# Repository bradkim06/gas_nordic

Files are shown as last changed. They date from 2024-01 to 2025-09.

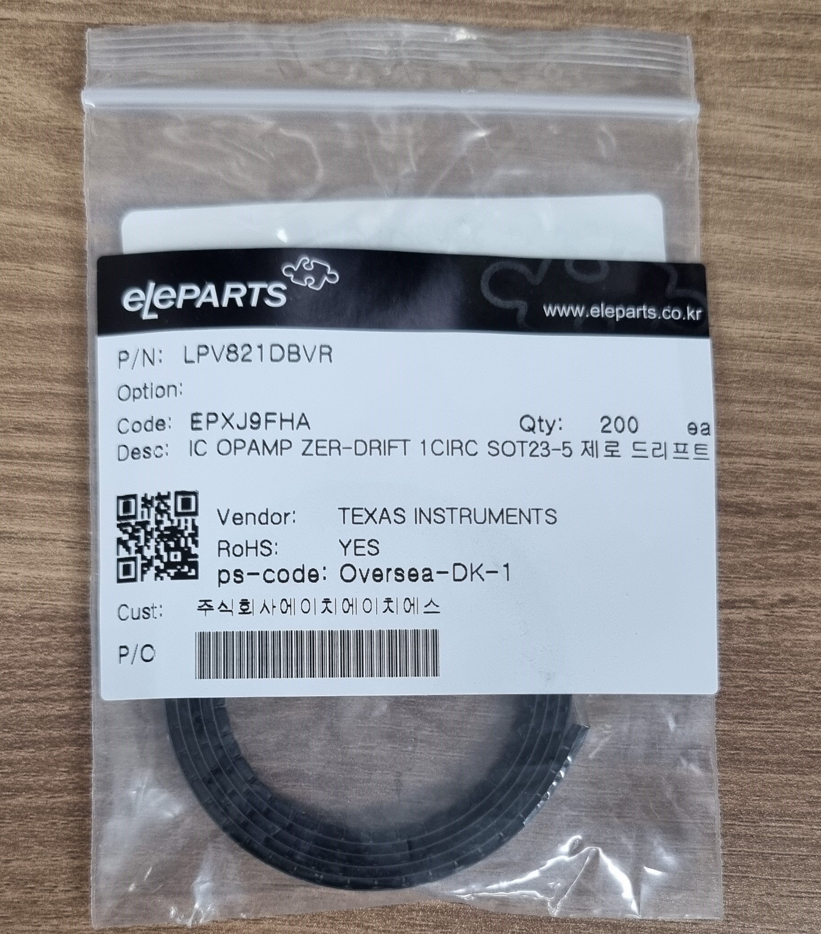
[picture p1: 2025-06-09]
hardware/gas_nrf52832/pcb/2차_Rev1.0.2(4L)/24.9.19 검수조서/9.19 검수조서 사진/19.jpg

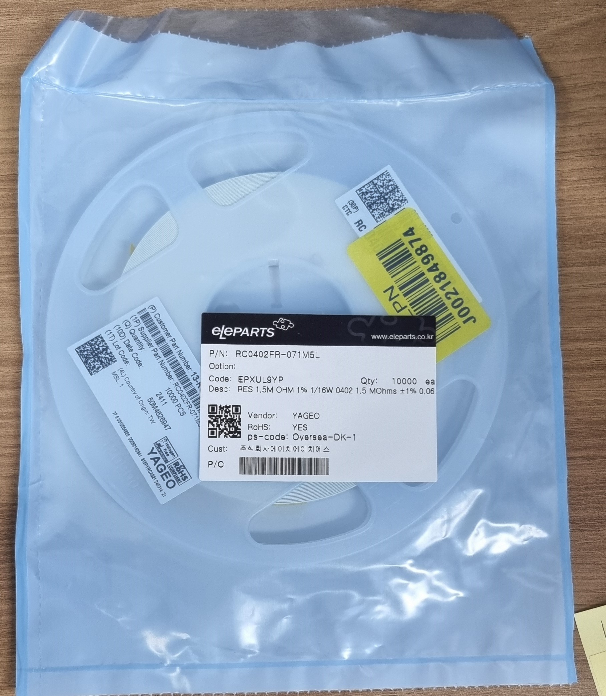
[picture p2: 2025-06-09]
hardware/gas_nrf52832/pcb/2차_Rev1.0.2(4L)/24.9.19 검수조서/9.19 검수조서 사진/10.jpg

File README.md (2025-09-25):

# Industrial Gas Monitor Firmware (nRF52832 + Zephyr)

Firmware version **1.0.2** for HHS's portable industrial gas monitor. The
application runs on a custom nRF52832 board, measures multiple gases, and
transmits real-time readings over Bluetooth® Low Energy. Environmental data is
fused with the Bosch BSEC2 library to provide indoor air-quality indicators in
addition to electrochemical gas concentrations.

---

## Table of contents

1. [Key features](#key-features)
2. [Hardware overview](#hardware-overview)
3. [Supported measurements](#supported-measurements)
4. [Firmware architecture](#firmware-architecture)
5. [Build and flash](#build-and-flash)
6. [Bluetooth protocol](#bluetooth-protocol)
7. [Calibration & persistent settings](#calibration--persistent-settings)
8. [Reference tables](#reference-tables)
9. [License](#license)

---

## Key features

- **Multi-gas sensing** – Electrochemical front-end for oxygen and a selectable
  toxic gas channel (NO₂, CO, H₂S, Cl₂, NH₃, etc.) with temperature
  compensation and dynamic calibration algorithms.【F:src/gas.c†L1-L212】
- **Environmental monitoring** – Integrated BME68x support with Bosch BSEC2
  fusion to derive temperature, humidity, pressure, IAQ, equivalent CO₂, and
  VOC indices. BSEC state is saved to flash for consistent long-term behavior.
  【F:drivers/bme68x_iaq/bme68x_iaq.c†L40-L460】【F:src/settings.c†L1-L137】
- **Bluetooth LE connectivity** – Custom 128-bit GATT service publishes
  semicolon-delimited measurements every 10 seconds and accepts configuration
  commands from a companion application.【F:src/bluetooth.h†L5-L45】【F:src/bluetooth.c†L520-L585】
- **Robust low-power platform** – Built on Zephyr RTOS (nRF Connect SDK v2.4.2)
  with watchdog, power management, persistent storage, and board-specific
  optimizations.【F:prj.conf†L1-L110】

## Hardware overview

- **Target SoC:** Nordic Semiconductor nRF52832 (ARM® Cortex®-M4F, BLE 5).
- **Custom board definition:** `boards/arm/hhs_nrf52832` (schematic and layout
  included in `doc/`).【F:boards/arm/hhs_nrf52832/hhs_nrf52832.yaml†L1-L53】
- **Latest hardware pack:** `doc/gas_nrf52832_rev1.0.1.pdf` with matching
  schematic `doc/gas_nrf52832_sch_rev0.1.0.pdf`.
- **Peripheral highlights:**
  - Bosch BME688/BME680 environmental sensor on I²C.
  - Dual-channel electrochemical sensor front-end via SAADC.
  - Battery gauge through voltage divider + ADC.
  - RGB status LED and watchdog support.

## Supported measurements

| Domain | Reported values |
| --- | --- |
| Electrochemical gas | Oxygen concentration (%VOL) and one selectable toxic gas in
| | ppm, both temperature compensated and filtered.【F:src/gas.c†L1-L212】 |
| Environmental | Temperature (°C), relative humidity (%RH), barometric
| | pressure (Pa), IAQ score, equivalent CO₂ (ppm), and breath
| | VOC index via BSEC2.【F:drivers/bme68x_iaq/bme68x_iaq.c†L40-L460】 |
| Power | Battery percentage derived from loaded voltage profile.
| BLE telemetry | Timestamped payload streamed every 10 seconds (default).

## Firmware architecture

The firmware is organized into cooperative Zephyr threads and kernel events. A
high-level flow is shown below:

```mermaid
---
title: Portable Gas Monitor Firmware Flow
---
stateDiagram-v2
    direction TB
    [*] --> ZephyrRTOS
    ZephyrRTOS --> BME68x_BSEC
    ZephyrRTOS --> Electrochemical_ADC
    ZephyrRTOS --> BluetoothLE

    state ZephyrRTOS {
        state BME68x_BSEC {
            direction LR
            initBSEC --> readEnvironmental : 3 s
            initBSEC --> computeIAQ : 60 s
        }
        state Electrochemical_ADC {
            direction TB
            sampleADC --> tempCompensation
            tempCompensation --> gasConversion
            gasConversion --> dynamicCalibration
        }
        state BluetoothLE {
            direction LR
            initialize --> advertise
            advertise --> connected
            connected --> notifyData : 10 s
        }
    }
```

Key modules reside in `src/` (application logic), `drivers/bme68x_iaq/`
(BSEC2 integration), and `lib/` (Bosch libraries). Threads communicate via
Zephyr events for deterministic BLE publishing and alarm handling.

## Build and flash

1. **Install prerequisites**
   - [nRF Connect SDK v2.4.2](https://developer.nordicsemi.com/nRF_Connect_SDK/doc/2.4.2/nrf/index.html)
     with the Zephyr toolchain, `west`, and SEGGER J-Link tools.
   - Bosch BSEC2 library files are already provided under `lib/`.
2. **Fetch the source**
   ```bash
   git clone https://github.com/<your-org>/gas_nordic.git
   cd gas_nordic
   west init -l .
   west update
   ```
3. **Build**
   ```bash
   west build -b hhs_nrf52832 .
   ```
   The output image is generated at `build/zephyr/zephyr.hex`.
4. **Flash**
   ```bash
   west flash
   ```
   or, to use Nordic's command-line tools directly:
   ```bash
   ./flash.sh
   ```
   (`flash.sh` performs a chip erase and programs the generated HEX via
   `nrfjprog`).【F:flash.sh†L1-L5】

## Bluetooth protocol

The device exposes a proprietary 128-bit primary service (`0000FFF0-0000-1000-8000-00805F9B34FB`).【F:src/bluetooth.h†L9-L26】

| Characteristic | UUID | Properties | Description |
| --- | --- | --- | --- |
| Measurement | `0000FFF1-0000-1000-8000-00805F9B34FB` | Notify | Periodic payload `O2;Gas;Battery;Temp;Pressure;Humidity` separated by semicolons, integers scaled as `<val1>.<val2>` where applicable.【F:src/bluetooth.c†L536-L576】 |
| Command | `0000FFF2-0000-1000-8000-00805F9B34FB` | Write | ASCII commands for calibration and configuration: `O2=<percent>`, `NO2=<ppm>`, `BT=<name>`.【F:src/bluetooth.c†L60-L124】 |

Notifications are issued when a connection is active and the client enables
CCCD. Each update corresponds to the latest sensor snapshot and is throttled to
the configured 10 s publishing interval.

## Calibration & persistent settings

- **Dynamic calibration** continuously refines oxygen and toxic gas baselines by
  monitoring derivative stability, expected ranges, and board temperature.
  Manual calibration can be triggered by writing to the command characteristic as
  described above.【F:src/gas.c†L1-L212】【F:src/bluetooth.c†L60-L124】
- **Persistent storage** uses Zephyr's settings/NVS subsystem to retain BSEC
  state, sensor calibration voltages, and the advertised Bluetooth name across
  reboots.【F:src/settings.c†L1-L200】
- **Battery reporting** samples SAADC channels and converts them into a
  percentage using empirically tuned thresholds (see `src/battery.c`).

## Reference tables

### Oxygen concentration guide

| Category | Concentration range | Notes |
| --- | --- | ----- |
| High oxygen | &gt; 24 % | Elevated combustion risk. |
| Normal air | 20.9 % | Nominal breathable atmosphere. |
| Elevated exposure risk | 19.5 – 20.9 % | Monitor for dilution hazards. |
| Low oxygen | 16 – 19.5 % | Impaired cognition and physical performance. |
| Anoxic | &lt; 16 % | Life-threatening within minutes. |

### Indoor air quality (IAQ) interpretation

| IAQ index | Air quality | Suggested action |
| --- | --- | --- |
| 0 – 50 | Excellent | None required. |
| 51 – 100  | Good | None required. |
| 101 – 150 | Lightly polluted | Ventilate if convenient. |
| 151 – 200 | Moderately polluted | Increase ventilation with clean air. |
| 201 – 250 | Heavily polluted | Identify contamination source, improve airflow. |
| 251 – 350 | Severely polluted | Restrict access, maximize ventilation. |
| &gt; 351 | Extremely polluted | Avoid occupancy until levels normalize. |

### CO₂ comfort levels

| Level | Description | ppm |
| :---: | --- | --- |
| 😆 | Healthy outdoor reference | 350 |
| 😀 | Healthy indoor climate | 600 |
| 🙂 | Acceptable indoors | 800 |
| 🙁 | Ventilation desirable | 1000 |
| 😩 | Ventilation necessary | 1200 |
| 😡 | Noticeable health effects | 2000 |
| ⚠️ | Dangerous for prolonged exposure | 5000 |

### VOC hygiene guidance

| Rating | Recommendation | Exposure duration | TVOC (ppm) |
| --- | --- | --- | --- |
| Excellent | Target value | Unlimited | 0 – 0.065 |
| Good | Ventilation recommended | Unlimited | 0.065 – 0.22 |
| Moderate  | Increase ventilation, inspect for sources | &lt; 12 months | 0.22 – 0.66 |
| Poor | Intensify ventilation, locate emission sources  | &lt; 1 month | 0.66 – 2.2 |
| Unhealthy | Immediate ventilation required | Hours | 2.2 – 5.5 |

## License

Distributed under the terms of the [MIT License](LICENSE). Bosch BSEC2 library
usage is subject to its proprietary license (see `lib/Bosch-BSEC2-Library`).

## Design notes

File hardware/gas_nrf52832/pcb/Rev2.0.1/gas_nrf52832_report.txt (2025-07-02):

PCB 통계 보고서
=======================
- 날짜: Tuesday, June 24, 2025 at 10:41:05 AM
- 프로젝트: gas_nrf52832
- 보드 이름: gas_nrf52832

기판
-----
- 두께: 알 수 없음
- 높이: 알 수 없음
- 지역: 알 수 없음

패드
----
- 스루홀: 28
- SMD: 236
- 연결선: 0
- NPTH: 4

비아
----
- 관통 비아: 104
- 매립/매장: 0
- 마이크로 비아: 0

부품
----------

| | 전면 | 후면 | 합계 |
|---|----|----|----|
|THT: |  6 |  2 |  8 |
|SMD: | 68 |  7 | 75 |
|지정되지 않음:  |  0 |  0 |  0 |
|합계: | 74 |  9 | 83 |

드릴 홀
-----------

| 개수 | 형상 | X 크기 | Y 크기 | 도금 | 비아/패드 | 시작 레이어 | 종료 레이어 |
|----|----|---|---|---|---|---|---|
| 92 | 둥근 | 0.3000 mm | 0.3000 mm | 도금 관통 홀 | 비아 | F.Cu | B.Cu |
| 12 | 둥근 | 0.4000 mm | 0.4000 mm | 도금 관통 홀 | 비아 | F.Cu | B.Cu |
|  8 | 둥근 | 1.0000 mm | 1.0000 mm | 도금 관통 홀 | 패드 | F.Cu | B.Cu |
|  6 | 둥근 | 2.8000 mm | 2.8000 mm | 도금 관통 홀 | 패드 | F.Cu | B.Cu |
|  4 | 둥근 | 0.9000 mm | 0.9000 mm | 도금 관통 홀 | 패드 | F.Cu | B.Cu |
|  4 | 둥근 | 2.2000 mm | 2.2000 mm | NPTH | 패드 | F.Cu | B.Cu |
|  4 | 슬롯 | 0.4000 mm | 0.8000 mm | 도금 관통 홀 | 패드 | F.Cu | B.Cu |
|  2 | 둥근 | 0.6500 mm | 0.6500 mm | 도금 관통 홀 | 패드 | F.Cu | B.Cu |
|  2 | 둥근 | 1.3000 mm | 1.3000 mm | 도금 관통 홀 | 패드 | F.Cu | B.Cu |
|  2 | 슬롯 | 0.4000 mm | 1.2000 mm | 도금 관통 홀 | 패드 | F.Cu | B.Cu |

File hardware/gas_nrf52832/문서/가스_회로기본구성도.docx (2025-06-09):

기능 Flow Chart

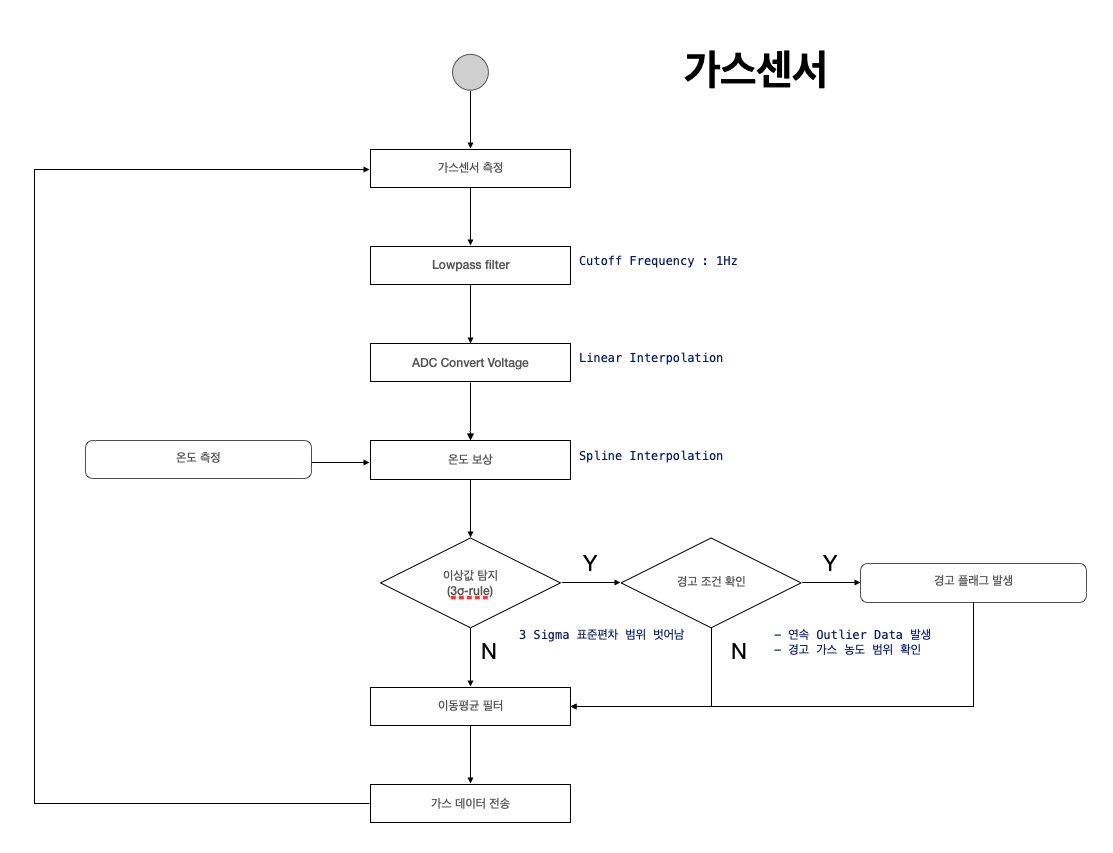
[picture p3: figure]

전기화학식 가스센서 회로 구성 요약

- 전원 주기를 반복하는 것은 일반적으로 긴 회복 시간, 재영점 조정 요구사항, 또는 전원 주기로 인한 센서 손상 가능성 때문에 지속적으로 바이어스가 필요
- LPV821 마이크로파워 증폭기는 초저전력(일반적으로 채널당 650 nA)으로 선택되어 전체 포텐셔스탯 회로가 1 µA의 공급 전류를 사용하므로 배터리 구동 애플리케이션에서 회로를 지속적으로 전원을 공급
- 센서 바이어스와 전류-전압 변환을 제공하는 3단자 전기화학 센서 증폭기 회로, 저항 분배기 바이어스 전압 회로, 아날로그-디지털 변환, 처리 및 블루투스 전송 기능
- 가스센서 온,습도 보정을 위한 BME680 환경센서

전기화학식 가스 센서 장점

- 출력 선형 성
- 저전력 소모
- 우수한 분해능
- 목표 기체에 대해 측정의 반복정 밀도(repeatability)와 정확도

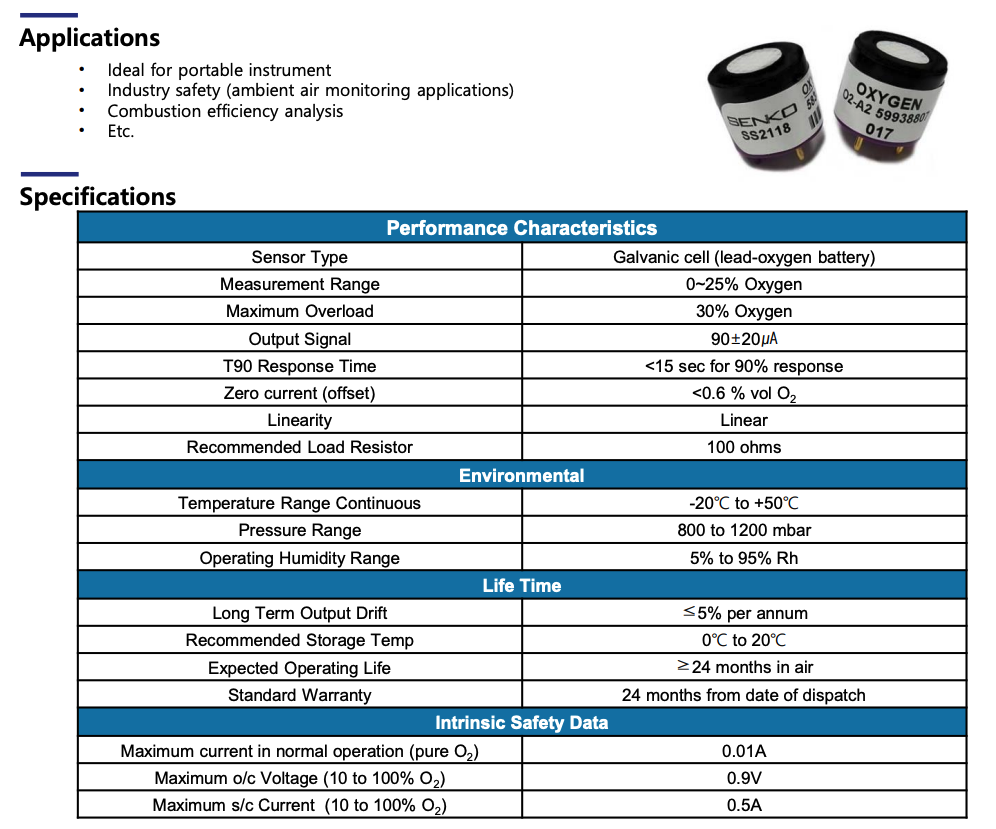
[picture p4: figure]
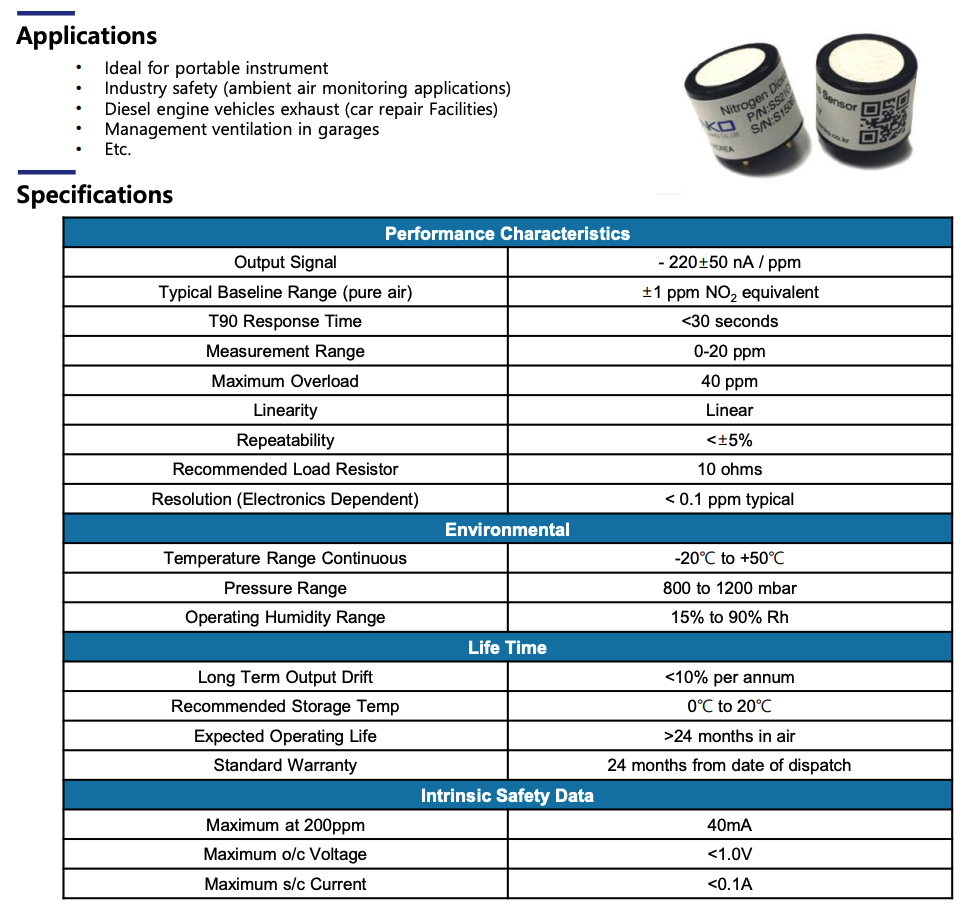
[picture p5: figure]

가스센서 회로

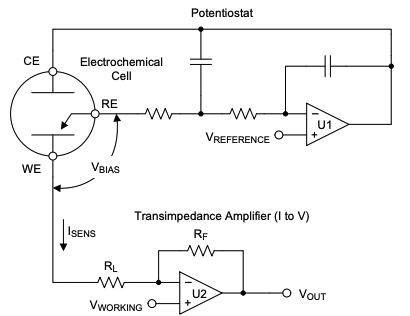
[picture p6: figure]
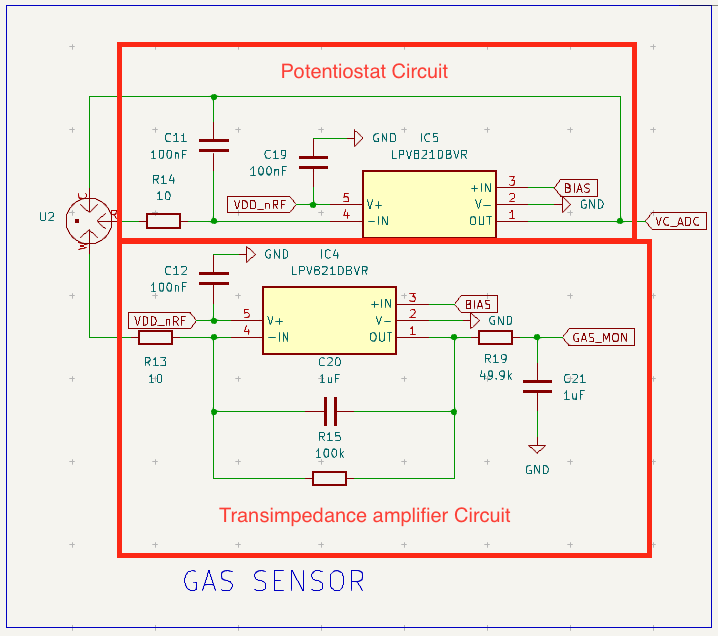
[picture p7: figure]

- 유해가스 회로는 3단자 가스센서로 구성
- 센서의 안정적인 작동과 정확한 측정을 위해 작용전극(Working electrode)과 기준전극(Reference electrode) 사이의 전압을 일정하게 유지하는 Potentiostat 회로
- 가스센서에서 발생하는 미세한 전류 신호를 안정적이고 측정 가능한 전압 신호로 변환하여 가스 농도를 정확하게 측정할 수 있게 해주는 Transimpedance amplifier 회로
- Amplifier의 출력단과 피드백단은 Hardware Low-pass filter 적용

Gas Detection OP-Amp (LPV821)

- 저전력 : Quiescent Current 650 nA
- 고정밀 : Low Offset Voltage: ±10 μV (Maximum) Offset Voltage Drift: ±0.096 μV/°C (Maximum)

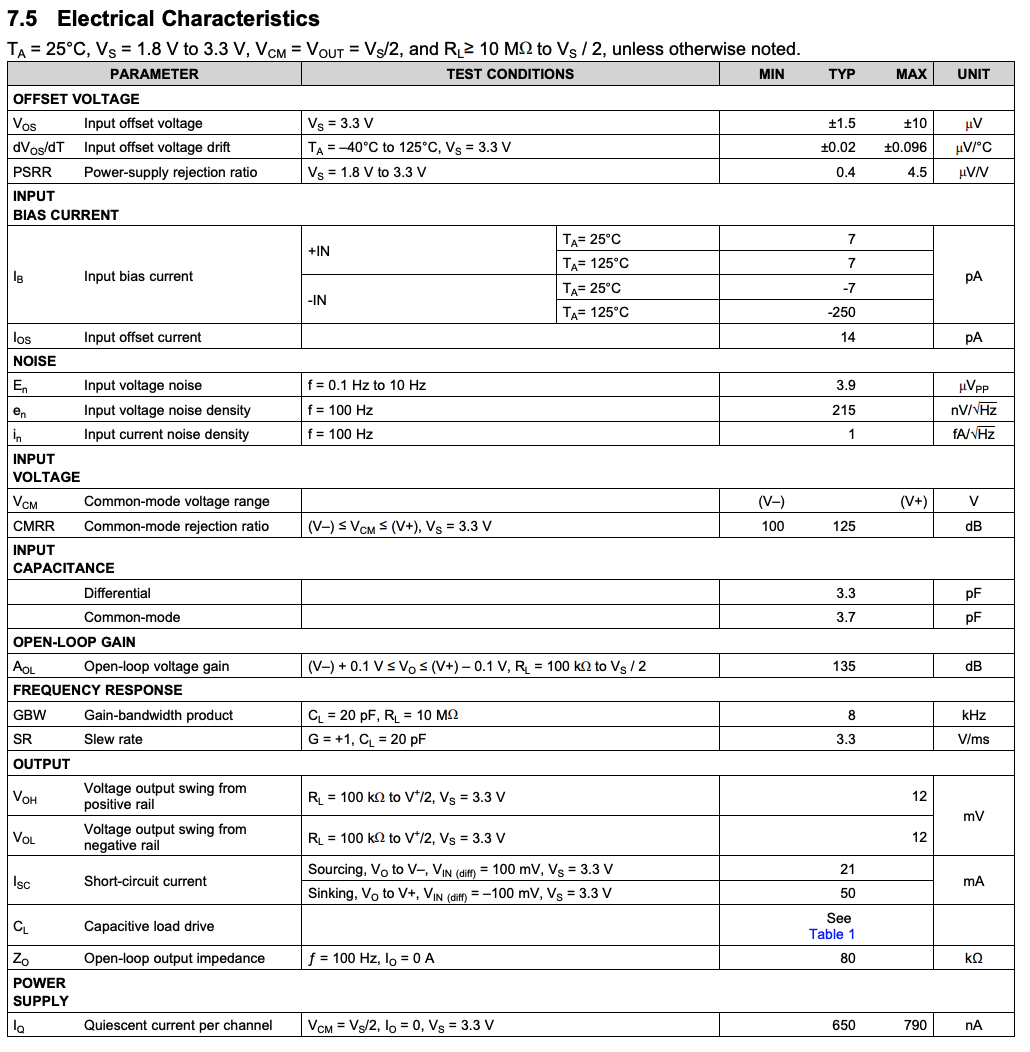
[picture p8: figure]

Battery System

- 50uA 저전력소모 (연간 = 0.05mA*24*365 = 438mA)
- 400mA 이하의 2차 전지 사용시 USB-C 충전 부가회로 (현재)
- 1000mA 이상 1차 전지 사용시 2년 10개월 사용 (전기화학식 센서의 일반적인 수명 2년) (TODO)

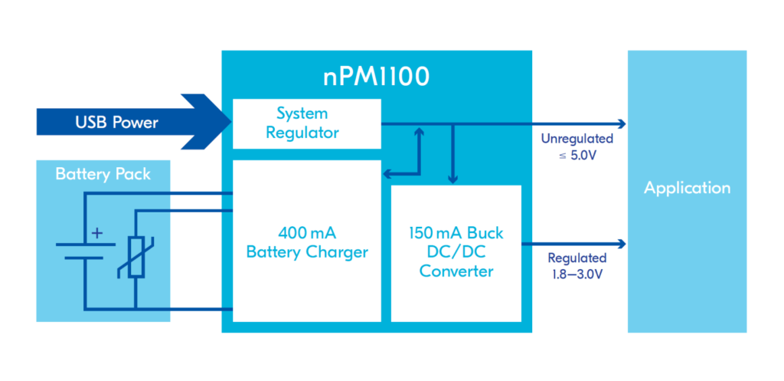
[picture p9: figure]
nPM1100 Power Management IC from Nordic Semiconductor Delivers Power to Your Circuits and Charges Battery - CIRCUITSTATE Electronics

환경센서 BME680(온도,습도 등)

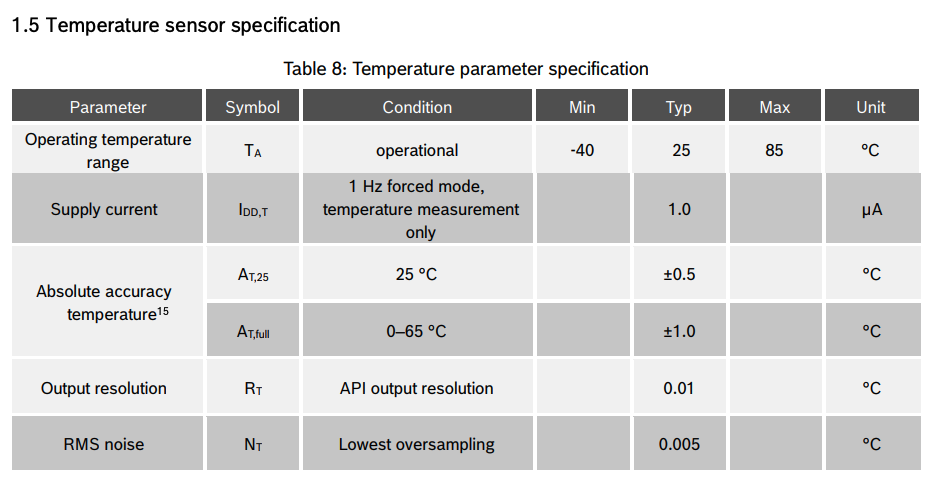
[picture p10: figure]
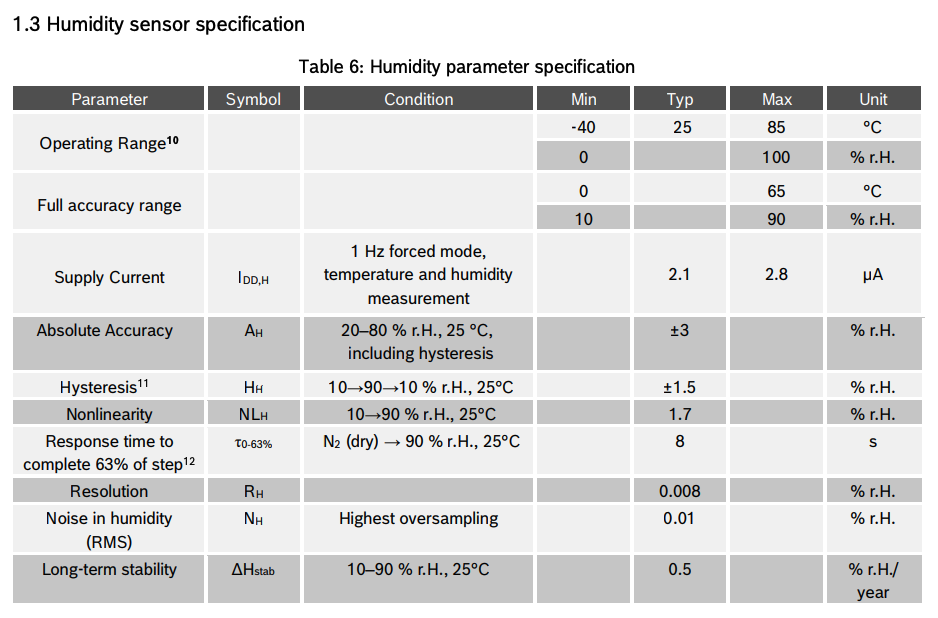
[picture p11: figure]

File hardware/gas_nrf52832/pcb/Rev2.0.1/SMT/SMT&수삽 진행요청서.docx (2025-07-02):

S M T & 수 삽 견 적 요 청 서
업체명 | HHS | | 담당자 /연락처 | 김준수 010-4496-1966
모델명 | Gas_Rev2.0.1 | | 수량 | 4Kit

SMT 제작정보
1 표면실장 : 양면 2 메탈마스크 : 도급 3 크림솔더유형 : 유연 4 부품인계방법 : 경동화물 5 수삽부품유무 : 무 | | | | (단면/양면) (사급/도급) (유연/무연) (퀵/경동화물/방문전달) (유/무)

기타 요청사항

- 부품 6/24(화) 경동화물 발송예정

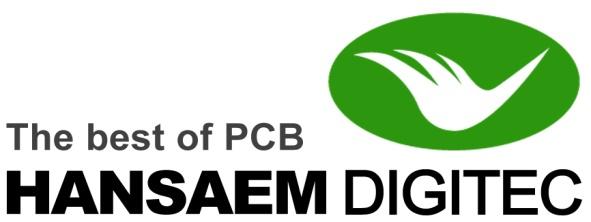
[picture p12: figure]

BOM,PL 및 데이터 전송 | | hs@hsdgt.com
SMT 주문관련 문의 032-581-5375 | | 영업부 차장 김병길 010-6516-5375 과장 최인석 010-6517-5375

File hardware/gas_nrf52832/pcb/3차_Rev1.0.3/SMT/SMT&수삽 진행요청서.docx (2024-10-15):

S M T & 수 삽 견 적 요 청 서
업체명 | HHS | | 담당자 /연락처 | 김준수 010-4496-1966
모델명 | Gas_Rev1.0.3 | | 수량 | 10Kit(20EA)

SMT 제작정보
1 표면실장 : 단면 2 메탈마스크 : 도급 3 크림솔더유형 : 유연 4 부품인계방법 : 경동화물 5 수삽부품유무 : 무 | | | | (단면/양면) (사급/도급) (유연/무연) (퀵/경동화물/방문전달) (유/무)

기타 요청사항

- 부품 10/4(금) 경동화물 발송예정

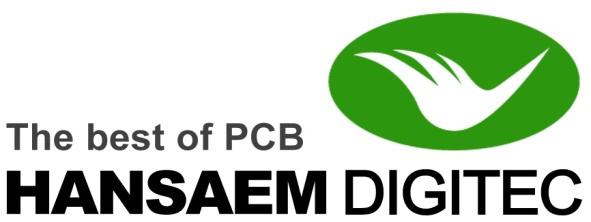
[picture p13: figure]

BOM,PL 및 데이터 전송 | | hs@hsdgt.com
SMT 주문관련 문의 032-581-5375 | | 영업부 차장 김병길 010-6516-5375 과장 최인석 010-6517-5375

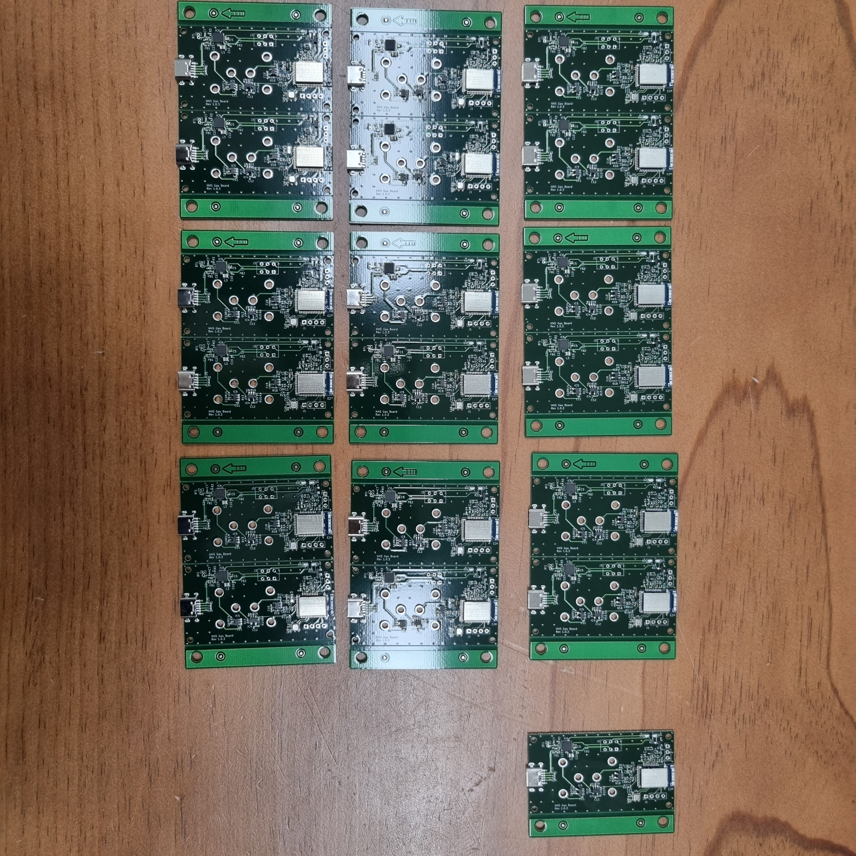
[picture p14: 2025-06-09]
hardware/gas_nrf52832/pcb/3차_Rev1.0.3/문서/24.10.15 검수조서/10.15 검수조서 사진/KakaoTalk_20241015_093432720_01.jpg

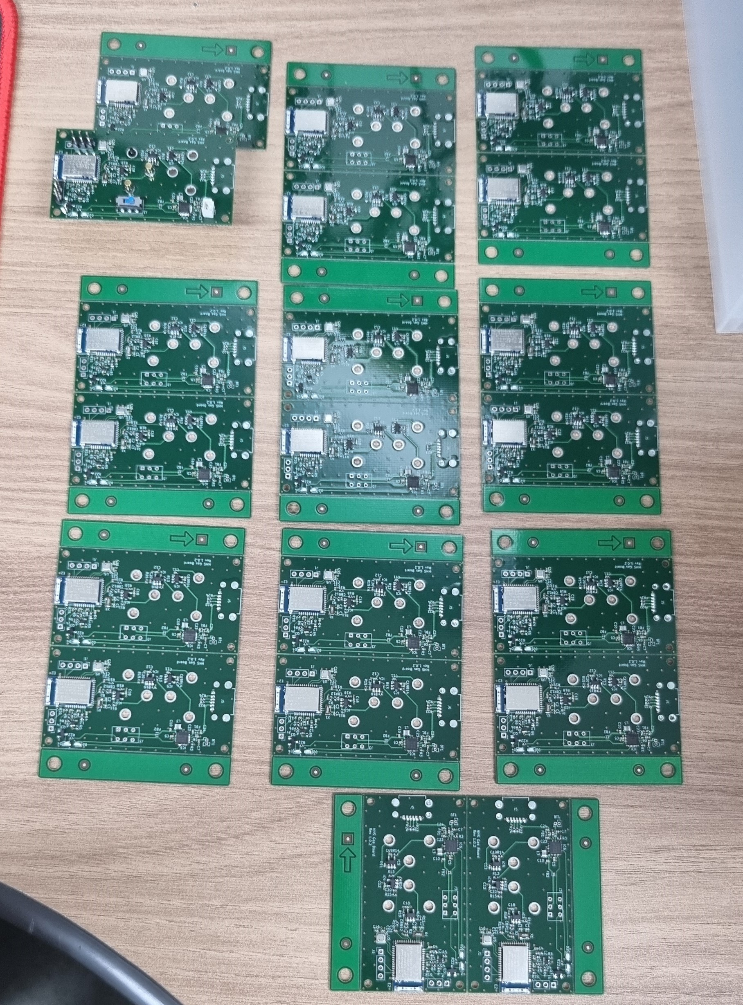
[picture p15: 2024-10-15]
hardware/gas_nrf52832/pcb/2차_Rev1.0.2(4L)/24.9.26 검수조서/9.26 검수조서 사진/KakaoTalk_20240926_162621671_01.jpg

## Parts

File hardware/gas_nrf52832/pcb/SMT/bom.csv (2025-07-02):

Reference | Value | Qty | MANUFACTURER | Manufacturer_Part_Number | 설명 | Package | Type
X1 | 32.768kHz | 1 | EPSON | FC-135 32.7680KA-A5 | Crystals SMD 32.768kHz | SMD3215-2P | Surface Mount
U5 | BME680 | 1 | Bosch Sensortec | BME680 | Pressure Sensors ROHS | LGA-8 | Surface Mount
U3 | MMBFJ177 | 1 | onsemi | MMBFJ177LT1G | JFET P-Channel 30 V 225 mW Surface Mount SOT-23-3 (TO-236) | SOT-23-3 | Surface Mount
R23,R24 | 5.1k | 2 | TA-I Tech | RM04FTN5101 | Fixed Resistor, Metal Glaze/thick Film, 0.0625W, 5.1k ohm, 50V, 1% +/-Tol, 100ppm/Cel | 0402 (1005 Metric) | Surface Mount
R22 | 150 | 1 | TA-I Tech | RM04FTN1500 | Fixed Resistor, Metal Glaze/thick Film, 0.0625W, 150 ohm, 50V, 1% +/-Tol, 100ppm/Cel | 0402 (1005 Metric) | Surface Mount
R21 | 953k | 1 | WALSIN | WR06X9533FTL | 953 kOhms ±1% 0.1W, 1/10W Chip Resistor 0603 (1608 Metric) Thick Film | 0603 (1608 Metric) | Surface Mount
R20 | 0 | 1 | TA-I Tech | RM04JTN0 | 62.5mW Thick Film Resistors 50V ±100ppm/℃ ±5% 0Ω 0402 Chip Resistor - Surface Mount ROHS | 0402 (1005 Metric) | Surface Mount
R17 | 9.1M | 1 | WALSIN | WR06W9104FTL | RES 9.1M OHM 1% 0603 | 0603 (1608 Metric) | Surface Mount
R15 | 300k | 1 | WALSIN | WR04X3003FTL | 300 kOhms ±1% 0.063W, 1/16W Chip Resistor 0402 (1005 Metric) Thick Film | 0402 (1005 Metric) | Surface Mount
R13 | 10 | 1 | YAGEO | RC0402FR-0710RL | 62.5mW Thick Film Resistors 50V ±1% ±200ppm/℃ 10Ω 0402 Chip Resistor - Surface Mount ROHS | 0402 (1005 Metric) | Surface Mount
R12 | 2M | 1 | YAGEO | RC0402FR-072ML | 62.5mW Thick Film Resistors 50V ±100ppm/℃ ±1% 2MΩ 0402 Chip Resistor - Surface Mount ROHS | 0402 (1005 Metric) | Surface Mount
R11 | 100 | 1 | YAGEO | RC0402FR-07100RL | 62.5mW Thick Film Resistors 50V ±100ppm/℃ ±1% 100Ω 0402 Chip Resistor - Surface Mount ROHS | 0402 (1005 Metric) | Surface Mount
R7 | 180k | 1 | TA-I Tech | RM04FTN1803 | Fixed Resistor, Metal Glaze/thick Film, 0.0625W, 180k ohm, 50V, 1% +/-Tol, 100ppm/Cel | 0402 (1005 Metric) | Surface Mount
R6 | 1M5 | 1 | YAGEO | RC0402FR-071M5L | 62.5mW Thick Film Resistors 50V ±100ppm/℃ ±1% 1.5MΩ 0402 Chip Resistor - Surface Mount ROHS | 0402 (1005 Metric) | Surface Mount
R4,R5,R9,R10,R25,R26,R31 | 1M | 7 | YAGEO | RC0402FR-071ML | 62.5mW Thick Film Resistors 50V ±100ppm/℃ ±1% 1MΩ 0402 Chip Resistor - Surface Mount ROHS | 0402 (1005 Metric) | Surface Mount
R3,R8,R14,R18 | 10k | 4 | TA-I Tech | RM04FTN1002 | Fixed Resistor, Metal Glaze/thick Film, 0.0625W, 10k ohm, 50V, 1% +/-Tol, 100ppm/Cel | 0402 (1005 Metric) | Surface Mount
R1,R2,R19 | 49.9k | 3 | TA-I Tech | RM04FTN4992 | 62.5mW Thick Film Resistors 50V ±100ppm/℃ ±1% 49.9kΩ 0402 Chip Resistor - Surface Mount ROHS | 0402 (1005 Metric) | Surface Mount
Q4 | DMC2400UV-7 | 1 | Diodes Incorporated | DMC2400UV-7 | 20V 480mΩ@200mA,5V 450mW 900mV@250uA 1PCSNChannel+1PCSPChannel SOT-563 MOSFETs ROHS | SOT-563 | Surface Mount
Q3 | FDV303N | 1 | ONSEMI | FDV303N | FDV303N N-Channel MOSFET, 680 mA, 25 V, 3-Pin SOT-23 ON Semiconductor | SOT-23 | Surface Mount
L3 | 2.2uH | 1 | Murata Electronics | 1285AS-H-2R2M=P2 | 1.5A 2.2uH ±20% 0806 Power Inductors ROHS | 0806 (2016 Metric) | Surface Mount
L2 | 10uH | 1 | Murata Electronics | LQM18FN100M00D | 50mA 10uH ±20% 50mA 1.17Ω 0603 Inductors (SMD) ROHS | 0603 (1608 Metric) | Surface Mount
L1 | 15nH | 1 | TDK | MLG1005S15NJT000 | 400mA 15nH ±5% 350mΩ 0402 Inductors (SMD) ROHS | 0402 (1005 Metric) | Surface Mount
IC6 | NPM1100-QDAA-R | 1 | NORDIC SEMICONDUCTOR | NPM1100-QDAA-R | Lithium-Ion/Polymer Battery Management ROHS | QFN-24(4x4) | Surface Mount
IC3,IC4,IC5 | LPV821DBVR | 3 | Texas Instruments | LPV821DBVR | 8kHz 1.5uV 7pA Single Channel Precision Op Amps ROHS | SOT-23-5 | Surface Mount
IC1 | REF1112AIDBZR | 1 | Texas Instruments | REF1112AIDBZR | Shunt Voltage Reference IC Fixed 1.25V V ±0.2% 5 mA SOT-23-3 | SOT-23-3 | Surface Mount
FB1,FB2 | 120R/0.9A | 2 | Murata Electronics | BLM15PE121SH1D | FERRITE BEAD | 0402 (1005 Metric) | Surface Mount
E2 | MDBT42Q-512KV2 | 1 | Raytac | MDBT42Q-512KV2 | Bluetooth Bluetooth v5.2 Transceiver Module | SMD-41 | Surface Mount
C24 | 10nF | 1 | Samsung Electro-Mechanics | CL05B103KB5NNNC | 50V 10nF X7R ±10% 0402 Multilayer Ceramic Capacitors MLCC - SMD/SMT ROHS | 0402 (1005 Metric) | Surface Mount
C11,C12,C14,C15,C16,C18,C19,C22,C23 | 100nF | 9 | Samsung Electro-Mechanics | CL05B104KO5NNNC | 16V 100nF X7R ±10% 0402 Multilayer Ceramic Capacitors MLCC - SMD/SMT ROHS | 0402 (1005 Metric) | Surface Mount
C4,C5,C6,C8,C9,C10,C13,C20,C21,C25,C26,C28 | 10uF | 12 | Murata Electronics | GRM155C80J106ME11D | 6.3V 10uF X6S ±20% 0402 Multilayer Ceramic Capacitors MLCC - SMD/SMT ROHS | 0402 (1005 Metric) | Surface Mount
C3,C7,C17,C27 | 1uF | 4 | Murata Electronics | GRM155C71A105ME11D | 10V 1uF X7S 0402 Multilayer Ceramic Capacitors MLCC - SMD/SMT ROHS | 0402 (1005 Metric) | Surface Mount
C1,C2 | 12pF | 2 | Samsung Electro-Mechanics | CL05C120JB5NNNC | 50V 12pF C0G ±5% 0402 Multilayer Ceramic Capacitors MLCC - SMD/SMT ROHS | 0402 (1005 Metric) | Surface Mount
J2 | USB | 1 | CUI Devices | UJ20-C-G-MSMT-TR-68 | USB-C (USB TYPE-C) USB 2.0 Receptacle Connector Mid-mount | SMD-8 | Surface Mount

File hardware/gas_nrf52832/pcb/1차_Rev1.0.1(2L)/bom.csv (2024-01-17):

Ref | Qnty | Value | Cmp name | Footprint | Vendor | Description
C1, C2 | 2 | 12pF | CAPACITOR_0402_N | Capacitor_SMD:C_0402_1005Metric | [YAGEO] CC0402FRNPO9BN120 | Capacitor
C3, C10, C12 | 3 | 1.0µF | CAPACITOR_0603_N | Capacitor_SMD:C_0603_1608Metric | [WALSIN] 0603B105K160CT | Capacitor
C4, C5, C6, C7 | 4 | 10uF | CAPACITOR_0402_N | Capacitor_SMD:C_0603_1608Metric | [삼성전기] CL10A106KQ8NNNC | Capacitor
C8 | 1 | 4.7nF | CAPACITOR_0402_N | Capacitor_SMD:C_0402_1005Metric | [WALSIN] 칩세라믹 1005사이즈 4.7nF K급 50V | Capacitor
C9 | 1 | 2.2uF | CAPACITOR_0402_N | Capacitor_SMD:C_0603_1608Metric | [MURATA] GRM188R71A225KE15D | Capacitor
C11, C13, C14, C15 | 4 | 0.1uF | CAPACITOR_0603_N | Capacitor_SMD:C_0603_1608Metric | [WALSIN] 0603B104K500CT | Light emitting diode
D1 | 1 | L0603R | LED | LED_SMD:LED_0603_1608Metric | [LONGSUM(중국)] [LS-SP190SR34-5] 칩LED1608-빨강 | Light emitting diode
D2 | 1 | L0603O | LED | LED_SMD:LED_0603_1608Metric | [Nationstar] 칩LED 1608 주황 [FC-DA1608HOK-600H] | Light emitting diode
D3 | 1 | L0603Y | LED | LED_SMD:LED_0603_1608Metric | [HSUKWANG (중국)] [LS-SP190HY34-5] 칩LED1608-노랑 | Light emitting diode
D4 | 1 | L0603G | LED | LED_SMD:LED_0603_1608Metric | [HSUKWANG (중국)] [LS-SP190YG84-5] 칩LED1608-녹색 | Light emitting diode
E1 | 1 | MDBT42Q-512KV2 | MDBT42Q-512KV2 | MDBT42Q-512KV2:RAYTAC_MDBT42Q-512KV2 | [Adafruit] nRF52832 Bluetooth Low Energy Module - MDBT42Q-512KV2 | Nordic 52832 Module
IC1 | 1 | NPM1100-QDAA-R | NPM1100-QDAA-R | NPM1100-QDAA:QFN50P400X400X90-25N-D | [NORDIC SEMICONDUCTOR] NPM1100-QDAA-R | Battery Management Extremely compact Power Management IC (PMIC) QFN
IC2 | 1 | TCK106AG,LF | TCK106AG,LF | TCK106AG,LF:BGA4C40P2X2_79X79X59 | [TOSHIBA] TCK106AG,LF(S | Power Switch ICs - Power Distribution Load Switch IC 1.0 A Load Switch IC with Slew Rate Control Driver in Ultra Small Package
J2 | 1 | USB4515-GF-A_REVA | USB4515-GF-A_REVA | USB4515-GF-A_REVA:GCT_USB4515-GF-A_REVA | [GCT (GLOBAL CONNECTOR TECHNOLOGY)] USB4515-GF-A | Type C USB Charging Connector
L1 | 1 | 15nH | INDUCTOR_0402_N | Capacitor_SMD:C_0402_1005Metric | [TDK] MLG1005S15NJT000 | Inductor
L2 | 1 | 10µH | INDUCTOR_0603_N | Inductor_SMD:L_0603_1608Metric | [MURATA] LQM18FN100M00D | Inductor
L3 | 1 | 2.2µH | INDUCTOR_0603_N | LIB_1285AS-H-2R2M=P2:1285ASH1R0MP2 | [MURATA] 1285AS-H-2R2M=P2 | Inductor
Q1 | 1 | DMC2400UV | DMC2400UV | DMC2400UV:SOTFL50P162X60-6N | [Diodes Incorporated] DMC2400UV-7 | COMPLEMENTARY PAIR ENHANCEMENT MODE MOSFET
Q2, Q3 | 2 | FDV303N | FDV303N | FDV303N:SOT96P237X111-3N | [ONSEMI] FDV303N | FDV303N N-Channel MOSFET, 680 mA, 25 V, 3-Pin SOT-23 ON Semiconductor
R1 | 1 | 0 | R | Resistor_SMD:R_0402_1005Metric | [TA-I] R1005-000J-0.0Ω | Resistor
R2 | 1 | 100 | R | Resistor_SMD:R_0402_1005Metric | [TA-I] R1005-101J-100Ω | Resistor
R3, R15 | 2 | 10k | R | Resistor_SMD:R_0402_1005Metric | [TA-I] R1005-103J-10KΩ | Resistor
R4, R5, R8, R9, R11, R12, R22 | 7 | 1M | R | Resistor_SMD:R_0402_1005Metric | [TA-I] R1005-105J-1MΩ | Resistor
R6 | 1 | 1M5 | R | Resistor_SMD:R_0402_1005Metric | [TA-I] R1005-155J-1.5MΩ | Resistor
R7 | 1 | 180k | R | Resistor_SMD:R_0402_1005Metric | [TA-I] R1005-1803F-180KΩ | Resistor
R10, R17 | 2 | 150 | R | Resistor_SMD:R_0402_1005Metric | [TA-I] R1005-1500F-150Ω | Resistor
R13 | 1 | 147k | R | Resistor_SMD:R_0402_1005Metric | [TA-I] R1005-1473F-147KΩ | Resistor
R14, R16 | 2 | 10 | R | Resistor_SMD:R_0402_1005Metric | [TA-I] R1005-100J-10Ω | Resistor
R18, R19 | 2 | 4.7k | R | Resistor_SMD:R_0402_1005Metric | [TA-I] R1005-4701F-4.7KΩ | Resistor
R20, R21 | 2 | 5.1k | R | Resistor_SMD:R_0402_1005Metric | [TA-I] R1005-5101F-5.1KΩ | Resistor
U3 | 1 | LPV811DBV | LPV811DBV | Package_TO_SOT_SMD:SOT-23-5 | [Texas Instruments] LPV811DBVR | Single operational amplifier, 8kHz GBW, 425 nA/channel quiescent, 100 fA input bias, 300 uV offset max, 1 uV/C, SOT-23-5
U4 | 1 | LPV812DGK | LPV812DGK | Package_SO:VSSOP-8_3.0x3.0mm_P0.65mm | [Texas Instruments] LPV812DGKR | Dual operational amplifier, 8kHz GBW, 425 nA/channel quiescent, 100 fA input bias, 300 uV offset max, 1 uV/C, VSSOP-8
U5 | 1 | BME680 | BME680 | Package_LGA:Bosch_LGA-8_3x3mm_P0.8mm_ClockwisePinNumbering | [Bosch Sensortec] BME680 | 4-in-1 sensor, gas, humidity, pressure, temperature, I2C and SPI interface, 1.71-3.6V, LGA-8
X1 | 1 | 32.768kHz | XTAL_32KHZ | Crystal:Crystal_SMD_3215-2Pin_3.2x1.5mm | [KYOCERA] ST3215 32.768KHz(SMD) | Crystal Units Surface Mount Type

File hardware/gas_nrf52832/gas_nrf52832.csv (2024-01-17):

Source: | /Users/bradkim06/Library/CloudStorage/OneDrive-UOU/kicad/test/gas_uipa/gas_uipa/gas_nrf52832/gas_nrf52832.kicad_sch
Date: | Friday, December 22, 2023 at 01:59:37 PM
Tool: | Eeschema 7.0.9
Generator: | /Applications/KiCad/KiCad.app/Contents/SharedSupport/plugins/bom_csv_grouped_by_value_with_fp.py
Component Count: | 66
Ref | Qnty | Value | Cmp name | Footprint | Description | Vendor | DNP
C1, C2 | 2 | 12pF | C | Capacitor_SMD:C_0402_1005Metric | Unpolarized capacitor
C3, C7, C12, C17, C23 | 5 | 1.0uF | C | Capacitor_SMD:C_0603_1608Metric | Unpolarized capacitor
C4, C5, C6, C10, C13 | 5 | 10uF | C | Capacitor_SMD:C_0603_1608Metric | Unpolarized capacitor
C8, C19 | 2 | 4.7nF | C | Capacitor_SMD:C_0402_1005Metric | Unpolarized capacitor
C9 | 1 | 2.2uF | C | Capacitor_SMD:C_0603_1608Metric | Unpolarized capacitor
C11, C14, C15, C16, C18, C20, C21, C22 | 8 | 0.1uF | C | Capacitor_SMD:C_0603_1608Metric | Unpolarized capacitor
D1 | 1 | L0603R | LED | LED_SMD:LED_0603_1608Metric | Light emitting diode
D2 | 1 | L0603O | LED | LED_SMD:LED_0603_1608Metric | Light emitting diode
D3 | 1 | L0603Y | LED | LED_SMD:LED_0603_1608Metric | Light emitting diode
D4 | 1 | L0603G | LED | LED_SMD:LED_0603_1608Metric | Light emitting diode
E1 | 1 | MDBT42Q-512KV2 | MDBT42Q-512KV2 | MDBT42Q-512KV2:RAYTAC_MDBT42Q-512KV2
FB1, FB2 | 2 | BLM15PE121SH1D | BLM15PE121SH1D | BLM15PE121SH1D:NFZ15SG152SN10B | Ferrite Beads 0402in 120ohm 900mA AEC-Q200 125degC
IC1 | 1 | NPM1100-QDAA-R | NPM1100-QDAA-R | NPM1100-QDAA:QFN50P400X400X90-25N-D | Battery Management Extremely compact Power Management IC (PMIC) QFN
IC2 | 1 | TCK106AG,LF | TCK106AG,LF | TCK106AG,LF:BGA4C40P2X2_79X79X59 | Power Switch ICs - Power Distribution Load Switch IC 1.0 A Load Switch IC with Slew Rate Control Driver in Ultra Small Package
J2 | 1 | USB4515-GF-A_REVA | USB4515-GF-A_REVA | USB4515-GF-A_REVA:GCT_USB4515-GF-A_REVA
L1 | 1 | 15nH | L | Inductor_SMD:L_0402_1005Metric | Inductor
L2 | 1 | 10uH | L | Inductor_SMD:L_0603_1608Metric | Inductor
L3 | 1 | 2.2uH | L | LIB_1285AS-H-2R2M=P2:1285ASH1R0MP2 | Inductor
Q1 | 1 | DMC2400UV | DMC2400UV | DMC2400UV:SOTFL50P162X60-6N | COMPLEMENTARY PAIR ENHANCEMENT MODE MOSFET
Q2, Q3 | 2 | FDV303N | FDV303N | FDV303N:SOT96P237X111-3N | FDV303N N-Channel MOSFET, 680 mA, 25 V, 3-Pin SOT-23 ON Semiconductor
R1, R23 | 2 | 0 | R | Resistor_SMD:R_0402_1005Metric | Resistor
R2 | 1 | 100 | R | Resistor_SMD:R_0402_1005Metric | Resistor
R3 | 1 | 10k | R | Resistor_SMD:R_0402_1005Metric | Resistor
R4, R5, R9, R10, R21 | 5 | 1M | R | Resistor_SMD:R_0402_1005Metric | Resistor
R6 | 1 | 1M5 | R | Resistor_SMD:R_0402_1005Metric | Resistor
R7 | 1 | 180k | R | Resistor_SMD:R_0402_1005Metric | Resistor
R8, R20 | 2 | 5.1k | R | Resistor_SMD:R_0402_1005Metric | Resistor
R11, R18 | 2 | 10.7 | R | Resistor_SMD:R_0402_1005Metric | Resistor
R12 | 1 | 2k | R | Resistor_SMD:R_0402_1005Metric | Resistor
R13, R14, R15 | 3 | 10 | R | Resistor_SMD:R_0402_1005Metric | Resistor
R16 | 1 | 150k | R | Resistor_SMD:R_0603_1608Metric | Resistor
R17, R22 | 2 | 150 | R | Resistor_SMD:R_0402_1005Metric | Resistor
R19 | 1 | 49.9k | R | Resistor_SMD:R_0402_1005Metric | Resistor
U3 | 1 | LPV811DBV | LPV811DBV | Package_TO_SOT_SMD:SOT-23-5 | Single operational amplifier, 8kHz GBW, 425 nA/channel quiescent, 100 fA input bias, 300 uV offset max, 1 uV/C, SOT-23-5
U4 | 1 | LPV812DGK | LPV812DGK | Package_SO:VSSOP-8_3.0x3.0mm_P0.65mm | Dual operational amplifier, 8kHz GBW, 425 nA/channel quiescent, 100 fA input bias, 300 uV offset max, 1 uV/C, VSSOP-8
U5 | 1 | BME680 | BME680 | Package_LGA:Bosch_LGA-8_3x3mm_P0.8mm_ClockwisePinNumbering | 4-in-1 sensor, gas, humidity, pressure, temperature, I2C and SPI interface, 1.71-3.6V, LGA-8
X1 | 1 | 32.768kHz | Crystal | Crystal:Crystal_SMD_3215-2Pin_3.2x1.5mm | Two pin crystal

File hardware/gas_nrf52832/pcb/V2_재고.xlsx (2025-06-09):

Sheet: SMT
Reference | Value | Qty | MANUFACTURER | Manufacturer_Part_Number | 설명 | Package | Type | 재고 | V2.0.1 | 현재
C1,C2 | 12pF | 2 | Samsung Electro-Mechanics | CL05C120JB5NNNC | 50V 12pF C0G ±5% 0402 Multilayer Ceramic Capacitors MLCC - SMD/SMT ROHS | 0402 (1005 Metric) | Surface Mount | 9880 |  | 9880
C3,C7,C17,C27 | 1uF | 4 | Murata Electronics | GRM155C71A105ME11D | 10V 1uF X7S 0402 Multilayer Ceramic Capacitors MLCC - SMD/SMT ROHS | 0402 (1005 Metric) | Surface Mount | 760 |  | 760
C4,C5,C6,C8,C9,C10,C13,C20,C21,C25,C26,C28 | 10uF | 12 | Murata Electronics | GRM155C80J106ME11D | 6.3V 10uF X6S ±20% 0402 Multilayer Ceramic Capacitors MLCC - SMD/SMT ROHS | 0402 (1005 Metric) | Surface Mount | 280 |  | 280
C11,C12,C14,C15,C16,C18,C19,C22,C23 | 100nF | 9 | Samsung Electro-Mechanics | CL05B104KO5NNNC | 16V 100nF X7R ±10% 0402 Multilayer Ceramic Capacitors MLCC - SMD/SMT ROHS | 0402 (1005 Metric) | Surface Mount | 9460 |  | 9460
C24 | 10nF | 1 | Samsung Electro-Mechanics | CL05B103KB5NNNC | 50V 10nF X7R ±10% 0402 Multilayer Ceramic Capacitors MLCC - SMD/SMT ROHS | 0402 (1005 Metric) | Surface Mount | 9940 |  | 9940
E2 | MDBT42Q-512KV2 | 1 | Raytac | MDBT42Q-512KV2 | Bluetooth Bluetooth v5.2 Transceiver Module | SMD-41 | Surface Mount | 20 |  | 20
FB1,FB2 | 120R/0.9A | 2 | Murata Electronics | BLM15PE121SH1D | FERRITE BEAD | 0402 (1005 Metric) | Surface Mount | 380 |  | 380
IC1 | REF1112AIDBZR | 1 | Texas Instruments | REF1112AIDBZR | Shunt Voltage Reference IC Fixed 1.25V V ±0.2% 5 mA SOT-23-3 | SOT-23-3 | Surface Mount | 50 |  | 50
IC3,IC4,IC5 | LPV821DBVR | 3 | Texas Instruments | LPV821DBVR | 8kHz 1.5uV 7pA Single Channel Precision Op Amps ROHS | SOT-23-5 | Surface Mount | 70 |  | 70
IC6 | NPM1100-QDAA-R | 1 | NORDIC SEMICONDUCTOR | NPM1100-QDAA-R | Lithium-Ion/Polymer Battery Management ROHS | QFN-24(4x4) | Surface Mount | 40 |  | 40
J2 | USB | 1 | CUI Devices | UJ20-C-G-MSMT-TR-68 | USB-C (USB TYPE-C) USB 2.0 Receptacle Connector Mid-mount | SMD-8 | Surface Mount | 160 |  | 160
L1 | 15nH | 1 | TDK | MLG1005S15NJT000 | 400mA 15nH ±5% 350mΩ 0402 Inductors (SMD) ROHS | 0402 (1005 Metric) | Surface Mount | 440 |  | 440
L2 | 10uH | 1 | Murata Electronics | LQM18FN100M00D | 50mA 10uH ±20% 50mA 1.17Ω 0603 Inductors (SMD) ROHS | 0603 (1608 Metric) | Surface Mount | 440 |  | 440
L3 | 2.2uH | 1 | Murata Electronics | 1285AS-H-2R2M=P2 | 1.5A 2.2uH ±20% 0806 Power Inductors ROHS | 0806 (2016 Metric) | Surface Mount | 440 |  | 440
Q3 | FDV303N | 1 | ONSEMI | FDV303N | FDV303N N-Channel MOSFET, 680 mA, 25 V, 3-Pin SOT-23 ON Semiconductor | SOT-23 | Surface Mount | 440 |  | 440
Q4 | DMC2400UV-7 | 1 | Diodes Incorporated | DMC2400UV-7 | 20V 480mΩ@200mA,5V 450mW 900mV@250uA 1PCSNChannel+1PCSPChannel SOT-563 MOSFETs ROHS | SOT-563 | Surface Mount | 440 |  | 440
R1,R2,R19 | 49.9k | 3 | TA-I Tech | RM04FTN4992 | 62.5mW Thick Film Resistors 50V ±100ppm/℃ ±1% 49.9kΩ 0402 Chip Resistor - Surface Mount ROHS | 0402 (1005 Metric) | Surface Mount | 9820 |  | 9820
R3,R8,R14,R18 | 10k | 4 | TA-I Tech | RM04FTN1002 | Fixed Resistor, Metal Glaze/thick Film, 0.0625W, 10k ohm, 50V, 1% +/-Tol, 100ppm/Cel | 0402 (1005 Metric) | Surface Mount | 9760 |  | 9760
R4,R5,R9,R10,R25,R26,R31 | 1M | 7 | YAGEO | RC0402FR-071ML | 62.5mW Thick Film Resistors 50V ±100ppm/℃ ±1% 1MΩ 0402 Chip Resistor - Surface Mount ROHS | 0402 (1005 Metric) | Surface Mount | 9580 |  | 9580
R6 | 1M5 | 1 | YAGEO | RC0402FR-071M5L | 62.5mW Thick Film Resistors 50V ±100ppm/℃ ±1% 1.5MΩ 0402 Chip Resistor - Surface Mount ROHS | 0402 (1005 Metric) | Surface Mount | 9940 |  | 9940
R7 | 180k | 1 | TA-I Tech | RM04FTN1803 | Fixed Resistor, Metal Glaze/thick Film, 0.0625W, 180k ohm, 50V, 1% +/-Tol, 100ppm/Cel | 0402 (1005 Metric) | Surface Mount | 9940 |  | 9940
R11 | 100 | 1 | YAGEO | RC0402FR-07100RL | 62.5mW Thick Film Resistors 50V ±100ppm/℃ ±1% 100Ω 0402 Chip Resistor - Surface Mount ROHS | 0402 (1005 Metric) | Surface Mount | 9940 |  | 9940
R12 | 2M | 1 | YAGEO | RC0402FR-072ML | 62.5mW Thick Film Resistors 50V ±100ppm/℃ ±1% 2MΩ 0402 Chip Resistor - Surface Mount ROHS | 0402 (1005 Metric) | Surface Mount | 9940 |  | 9940
R13 | 10 | 1 | YAGEO | RC0402FR-0710RL | 62.5mW Thick Film Resistors 50V ±1% ±200ppm/℃ 10Ω 0402 Chip Resistor - Surface Mount ROHS | 0402 (1005 Metric) | Surface Mount | 9940 |  | 9940
R15 | 300k | 1 | WALSIN | WR04X3003FTL | 300 kOhms ±1% 0.063W, 1/16W Chip Resistor 0402 (1005 Metric) Thick Film | 0402 (1005 Metric) | Surface Mount | 9940 |  | 9940
R17 | 9.1M | 1 | WALSIN | WR06W9104FTL | RES 9.1M OHM 1% 0603 | 0603 (1608 Metric) | Surface Mount | 4940 |  | 4940
R20 | 0 | 1 | TA-I Tech | RM04JTN0 | 62.5mW Thick Film Resistors 50V ±100ppm/℃ ±5% 0Ω 0402 Chip Resistor - Surface Mount ROHS | 0402 (1005 Metric) | Surface Mount | 9940 |  | 9940
R21 | 953k | 1 | WALSIN | WR06X9533FTL | 953 kOhms ±1% 0.1W, 1/10W Chip Resistor 0603 (1608 Metric) Thick Film | 0603 (1608 Metric) | Surface Mount | 4940 |  | 4940
R22 | 150 | 1 | TA-I Tech | RM04FTN1500 | Fixed Resistor, Metal Glaze/thick Film, 0.0625W, 150 ohm, 50V, 1% +/-Tol, 100ppm/Cel | 0402 (1005 Metric) | Surface Mount | 9940 |  | 9940
R23,R24 | 5.1k | 2 | TA-I Tech | RM04FTN5101 | Fixed Resistor, Metal Glaze/thick Film, 0.0625W, 5.1k ohm, 50V, 1% +/-Tol, 100ppm/Cel | 0402 (1005 Metric) | Surface Mount | 9880 |  | 9880
U3 | MMBFJ177 | 1 | onsemi | MMBFJ177LT1G | JFET P-Channel 30 V 225 mW Surface Mount SOT-23-3 (TO-236) | SOT-23-3 | Surface Mount | 100 |  | 100
U5 | BME680 | 1 | Bosch Sensortec | BME680 | Pressure Sensors ROHS | LGA-8 | Surface Mount | 40 |  | 40
X1 | 32.768kHz | 1 | EPSON | FC-135 32.7680KA-A5 | Crystals SMD 32.768kHz | SMD3215-2P | Surface Mount | 140 |  | 140

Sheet: Through Hole
Reference | Value | Qty | MANUFACTURER | Manufacturer_Part_Number | 설명 | Package | Type | 재고 | V2.0.1 | 현재
S1 | SW1 | 1 | CUI Devices | TS11-674-43-BK-100-RA-D | SWITCH TACTILE SPST-NO 0.05A 12V |  | Through Hole | 10 |  | 10
D2 | L0603R | 1 | Kingbright | WP1533BQ/ID | LED Circuit Board Indicator Single Red Diffused |  | Through Hole | 10
D4 | L0603G | 1 | Kingbright | WP1533BQ/GD | LED Circuit Board Indicator Single Green Diffused |  | Through Hole | 10

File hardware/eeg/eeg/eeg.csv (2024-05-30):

Reference | Qty | Value | MANUFACTURER | MANUFACTURER_PART_NUMBER | 설명 | Package | Type
BT1 | 1 | Battery | CAX | 1.25T-2A | 1x2P 2P 1 1.25mm 2 -25℃~+85℃ 1A Straight Plugin,P=1.25mm Wire To Board / Wire To Wire Connector ROHS | 2POS | Through Hole
C1,C2,C8,C10,C14,C23,C26,C27,C28,C29,C30,C31,C32,C33,C34,C35,C36,C37 | 18 | 1uF | Murata Electronics | GRM155R61A105KE15D | 10V 1uF X5R ±10% 0402 Multilayer Ceramic Capacitors MLCC - SMD/SMT ROHS | 0402 (1005 Metric) | Surface Mount
C3,C5 | 2 | 4.7uF | Murata Electronics | GRM155R61A475MEAAD | 10V 4.7uF X5R ±20% 0402 Multilayer Ceramic Capacitors MLCC - SMD/SMT ROHS | 0402 (1005 Metric) | Surface Mount
C4,C6,C7,C16,C22,C25 | 6 | 100nF | Murata Electronics | GRM155R71C104KA88D | 16V 100nF X7R ±10% 0402 Multilayer Ceramic Capacitors MLCC - SMD/SMT ROHS | 0402 (1005 Metric) | Surface Mount
C9 | 1 | 2.2uF | Murata Electronics | GRM155Z71A225KE01D | 10V 2.2uF X7R ±10% 0402 Multilayer Ceramic Capacitors MLCC - SMD/SMT ROHS | 0402 (1005 Metric) | Surface Mount
C11,C12,C13,C15,C17,C18,C19,C21 | 8 | 10uF | Murata Electronics | GRM155R61A106ME44D | 10V 10uF X5R ±20% 0402 Multilayer Ceramic Capacitors MLCC - SMD/SMT ROHS | 0402 (1005 Metric) | Surface Mount
C20,C38,C39,C40,C41,C42,C43 | 7 | 1nF | Murata Electronics | GRM155R71H102KA01D | 50V 1nF X7R ±10% 0402 Multilayer Ceramic Capacitors MLCC - SMD/SMT ROHS | 0402 (1005 Metric) | Surface Mount
C24 | 1 | 100uF | Murata Electronics | GRM21BR60J107ME15L | 6.3V 100uF X5R ±20% 0805 Multilayer Ceramic Capacitors MLCC - SMD/SMT ROHS | 0805 (2012 Metric) | Surface Mount
D1 | 1 | LED_Y | Everlight Elec | 19-213/Y2C-CQ2R2L/3T(CY) | 20mA -40℃~+85℃ 585.5nm~591.5nm Yellow 120° 60mW 0603 Light Emitting Diodes (LED) ROHS | 0603 (1608 Metric) | Surface Mount
D2 | 1 | PRTR5V0U2X | Nexperia | PRTR5V0U2X,215 | 6V Unidirectional 5.5V SOT-143 Electrostatic and Surge Protection (TVS/ESD) | SOT-143 | Surface Mount
IC1 | 1 | NPM1300 | NORDIC SEMICONDUCTOR | nPM1300-QEAA-R | Battery Management Power Management IC (PMIC) with unique system management features, QFN32 | QFN-32 | Surface Mount
IC2 | 1 | LM2664M6X_NOPB | Texas Instruments | LM2664M6X/NOPB | Switching Voltage Regulators Switched Capacitor Vtg Cnvtr | SOT-23-6 | Surface Mount
IC3 | 1 | ADS1299-4PAGR | Texas Instruments | ADS1299-4PAGR | Analog to Digital Converters - ADC Low-Noise, 4-Channel, 24-Bit Analog-to-Digital Converter for Biopotential Measurements | TQFP-64 | Surface Mount
J1 | 1 | Conn_01x03 | CAX | 1.25T-3A | 1x3P 3P 1 1.25mm 3 -25℃~+85℃ 1A Straight Plugin,P=1.25mm Wire To Board / Wire To Wire Connector ROHS | 3POS | Through Hole
J2 | 1 | Conn_01x04 | CAX | 1.25T-4A | 1x4P 4P 1 1.25mm 4 -25℃~+85℃ 1A Straight Plugin,P=1.25mm Wire To Board / Wire To Wire Connector ROHS | 4POS | Through Hole
J3 | 1 | USB-C Connectors | Korean Hroparts Elec | TYPE-C-31-M-12 | 5A 1 16P Female Type-C SMD USB Connectors ROHS | SMD | Surface Mount
J4 | 1 | Conn_01x06 | CAX | 1.25T-6A | 1x6P 6P 1 1.25mm 6 -25℃~+85℃ 1A Straight Plugin,P=1.25mm Wire To Board / Wire To Wire Connector ROHS | 6POS | Through Hole
L1,L2 | 2 | 2.2uH | TDK Corporation | MLP2016H2R2MT0S1 | SMD / SMT Inductors (Coils), L=2.2?H, L x W x T : | 0806 (2016 Metric) | Surface Mount
R1 | 1 | 2.2 | YAGEO | RC0402FR-072R2L | 62.5mW Thick Film Resistors 50V ±1% ±200ppm/℃ 2.2Ω 0402 Chip Resistor - Surface Mount ROHS | 0402 (1005 Metric) | Surface Mount
R2,R3 | 2 | 150k | YAGEO | RC0402FR-07150KL | 62.5mW Thick Film Resistors 50V ±100ppm/℃ ±1% 150kΩ 0402 Chip Resistor - Surface Mount ROHS | 0402 (1005 Metric) | Surface Mount
R4 | 1 | 1M | YAGEO | RC0402FR-071ML | 62.5mW Thick Film Resistors 50V ±100ppm/℃ ±1% 1MΩ 0402 Chip Resistor - Surface Mount ROHS | 0402 (1005 Metric) | Surface Mount
R5,R6,R7,R8,R9,R10 | 6 | 2.2k | YAGEO | RC0402FR-071ML | 62.5mW Thick Film Resistors 50V ±100ppm/℃ ±1% 1MΩ 0402 Chip Resistor - Surface Mount ROHS | 0402 (1005 Metric) | Surface Mount
SW1 | 1 | SW_SPDT | SHOUHAN | SK12D07VG5 | 500mA SPDT 50V 5千次 Plugin Slide Switches ROHS | 5POS | Through Hole
U1 | 1 | NRF5340 | InsightSIP | ISP2053-AX-RS | Bluetooth Modules - 802.15.1 ISP2053-AX nRF5340 Bluetooth 5.2 LE Audio, DF and Long Range Module | LGA-65 | Surface Mount
U2 | 1 | BMI270 | Bosch Sensortec | BMI270 | Attitude Sensor/Gyroscope | LGA-14 | Surface Mount
U3,U4,U5 | 3 | TPD4E1B06DRLR | Texas Instruments | TPD4E1B06DRLR | 3A@(8/20us) 45W 14.5V 7V 5.5V SOT(5x3) Electrostatic and Surge Protection (TVS/ESD) | SOT-5X3 | Surface Mount

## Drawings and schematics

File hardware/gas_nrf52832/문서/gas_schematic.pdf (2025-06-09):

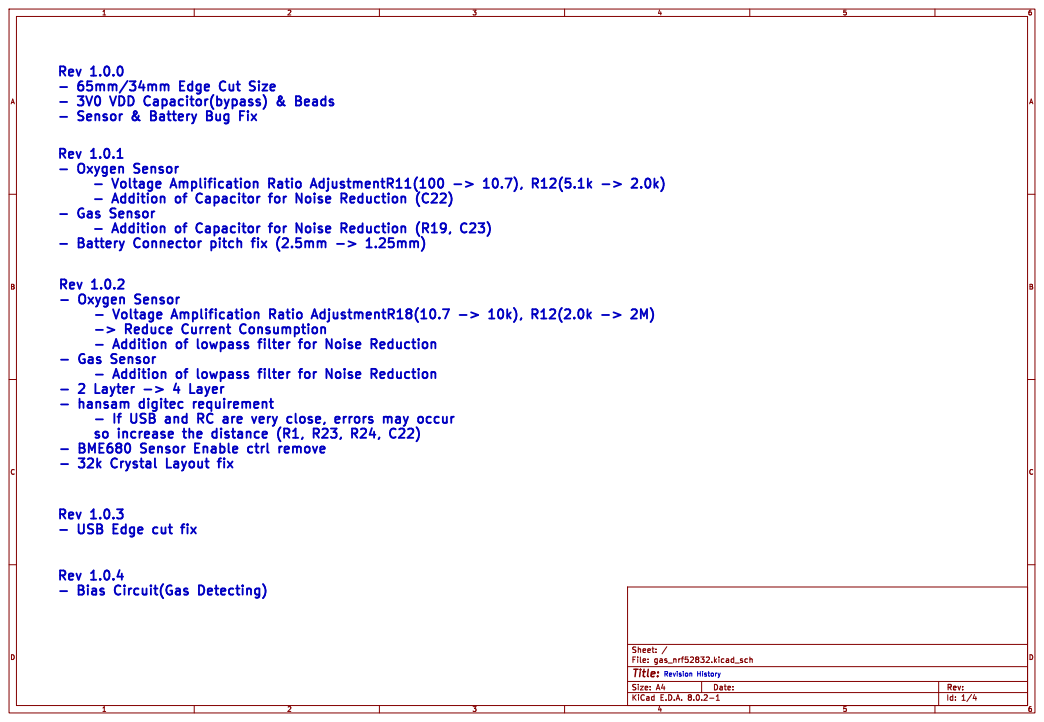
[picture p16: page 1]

Rev 1.0.2
- Oxygen Sensor
- Gas Sensor
- hansam digitec requirement
- If USB and RC are very close, errors may occur
- BME680 Sensor Enable ctrl remove
- 32k Crystal Layout fix

Rev 1.0.3
- USB Edge cut fix

Rev 1.0.4
- Bias Circuit(Gas Detecting)

Id: 1/4 Title: File: gas_nrf52832.kicad_sch Sheet: / nrf52832

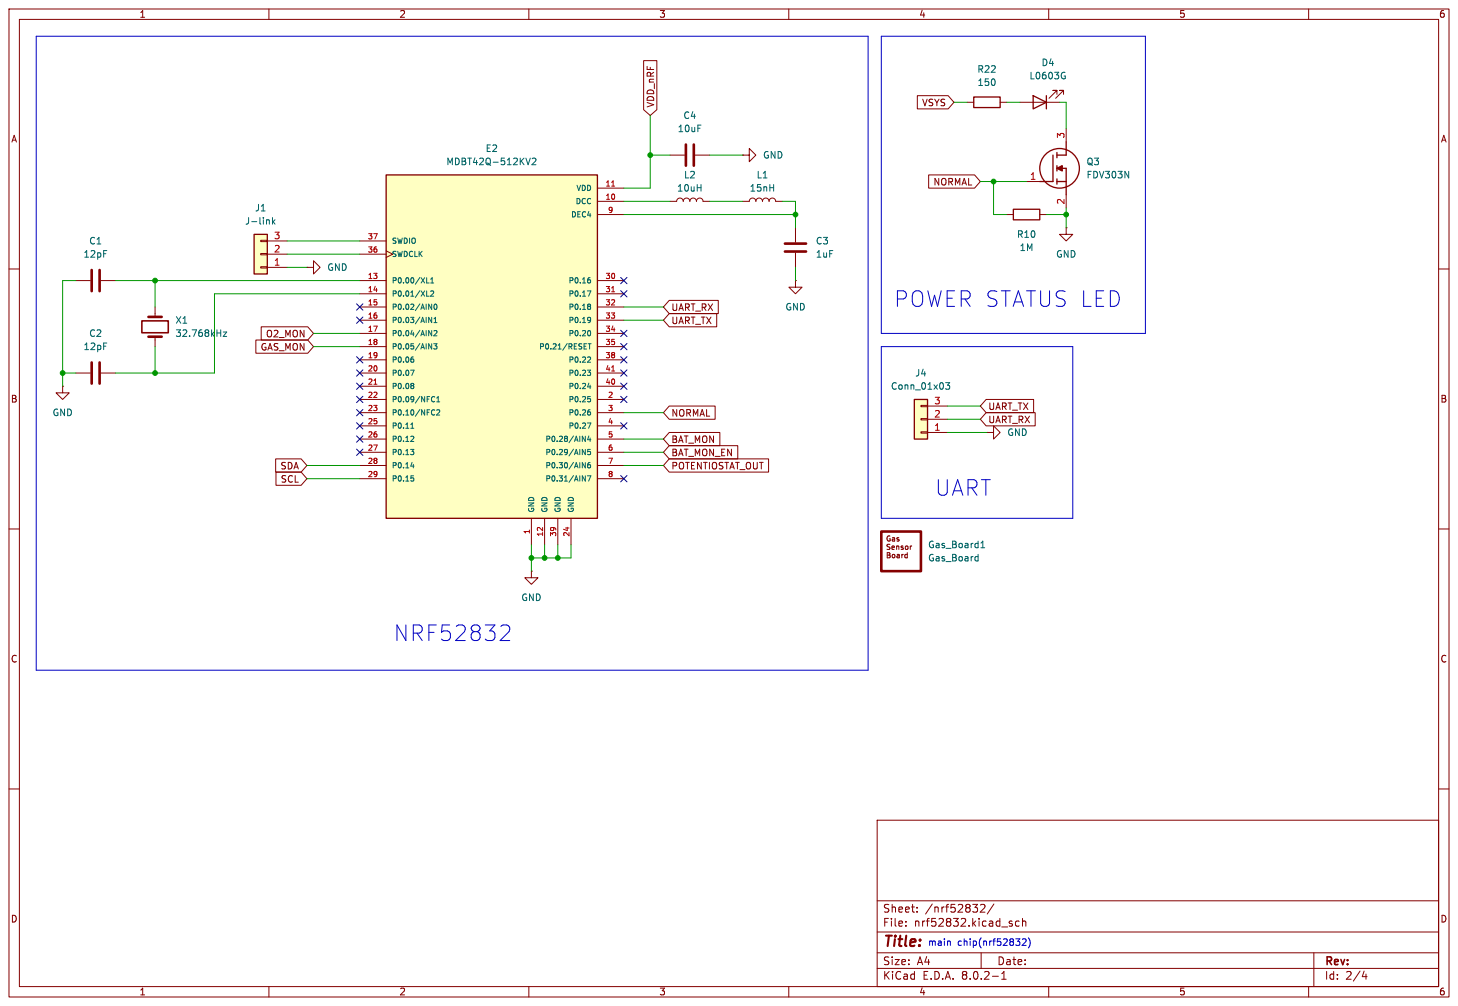
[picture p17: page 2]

1 DCC 10 VDD 11 GND 12 P0.00/XL1 13 P0.01/XL2 14 P0.06 19 P0.25 2 P0.07 20 P0.08 21 GND 24 P0.11 25 P0.12 26 P0.13 27 P0.14 28 P0.15 29 P0.26 3 P0.16 30 P0.17 31 P0.18 32 P0.19 33 P0.20 34 P0.21/RESET 35 SWDCLK 36 SWDIO 37 P0.22 38 GND 39 P0.27 4 P0.24 40 P0.23 41 DEC4 9 P0.02/AIN0 15 P0.03/AIN1 16 P0.04/AIN2 17 P0.05/AIN3 18 P0.09/NFC1 22 P0.10/NFC2 23 P0.28/AIN4 5 P0.29/AIN5 6 P0.30/AIN6 7 P0.31/AIN7 8 E2 MDBT42Q-512KV2 R22

Id: 2/4 Title: File: nrf52832.kicad_sch Sheet: /nrf52832/ GND

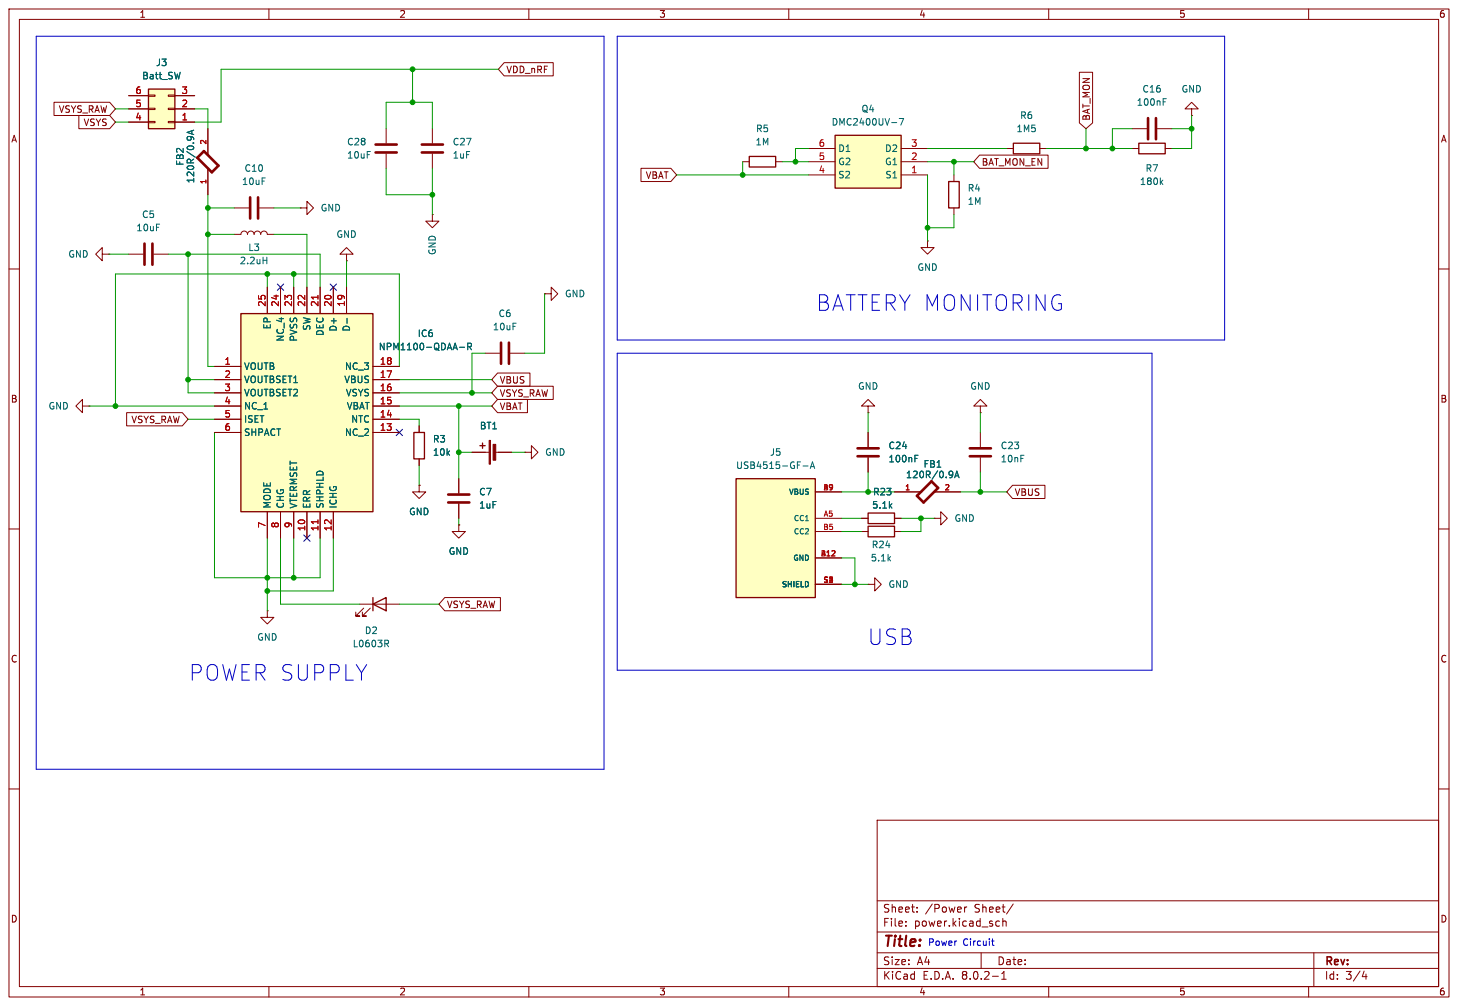
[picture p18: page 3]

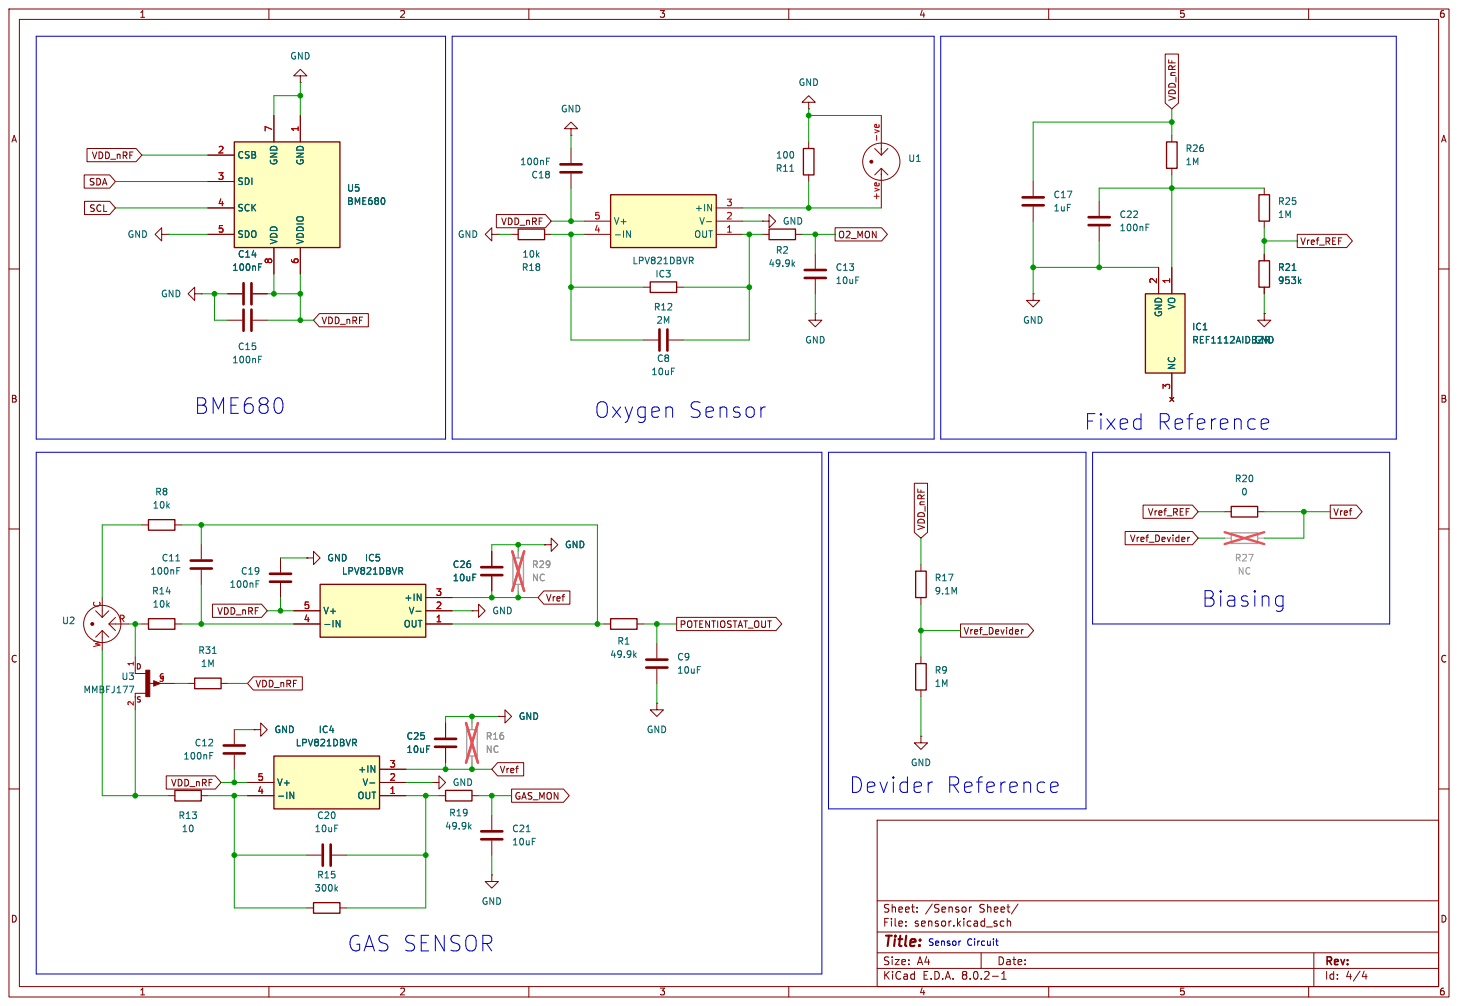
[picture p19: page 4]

1 CSB 2 SDI 3 SCK 4 SDO 5 VDDIO

GND
Sensor Circuit Devider Reference

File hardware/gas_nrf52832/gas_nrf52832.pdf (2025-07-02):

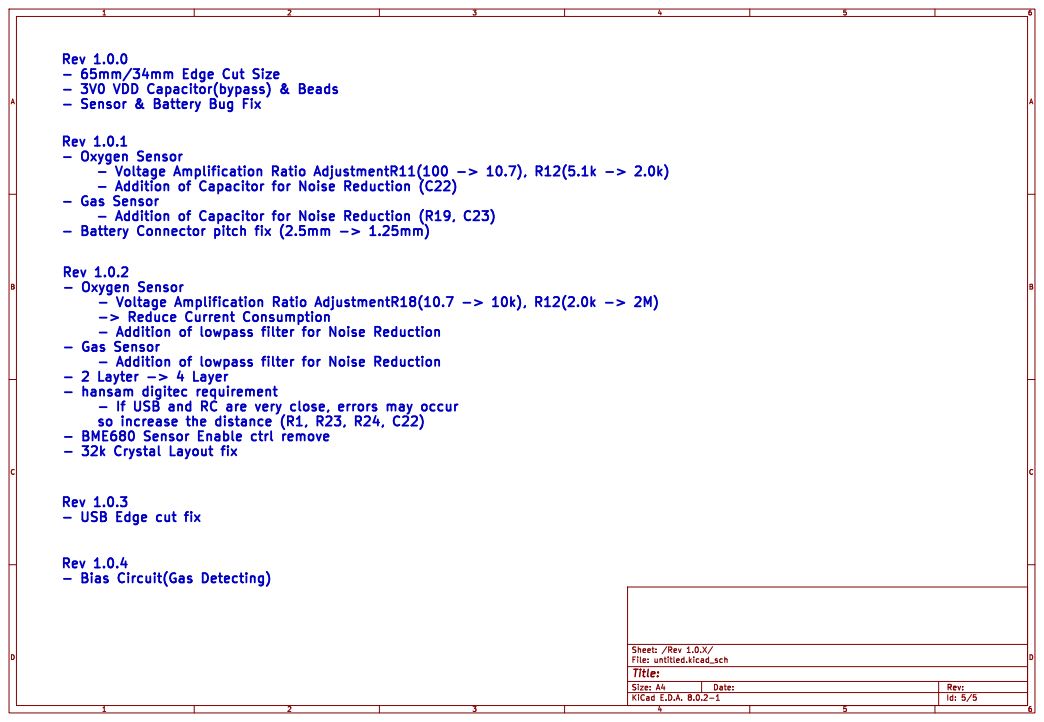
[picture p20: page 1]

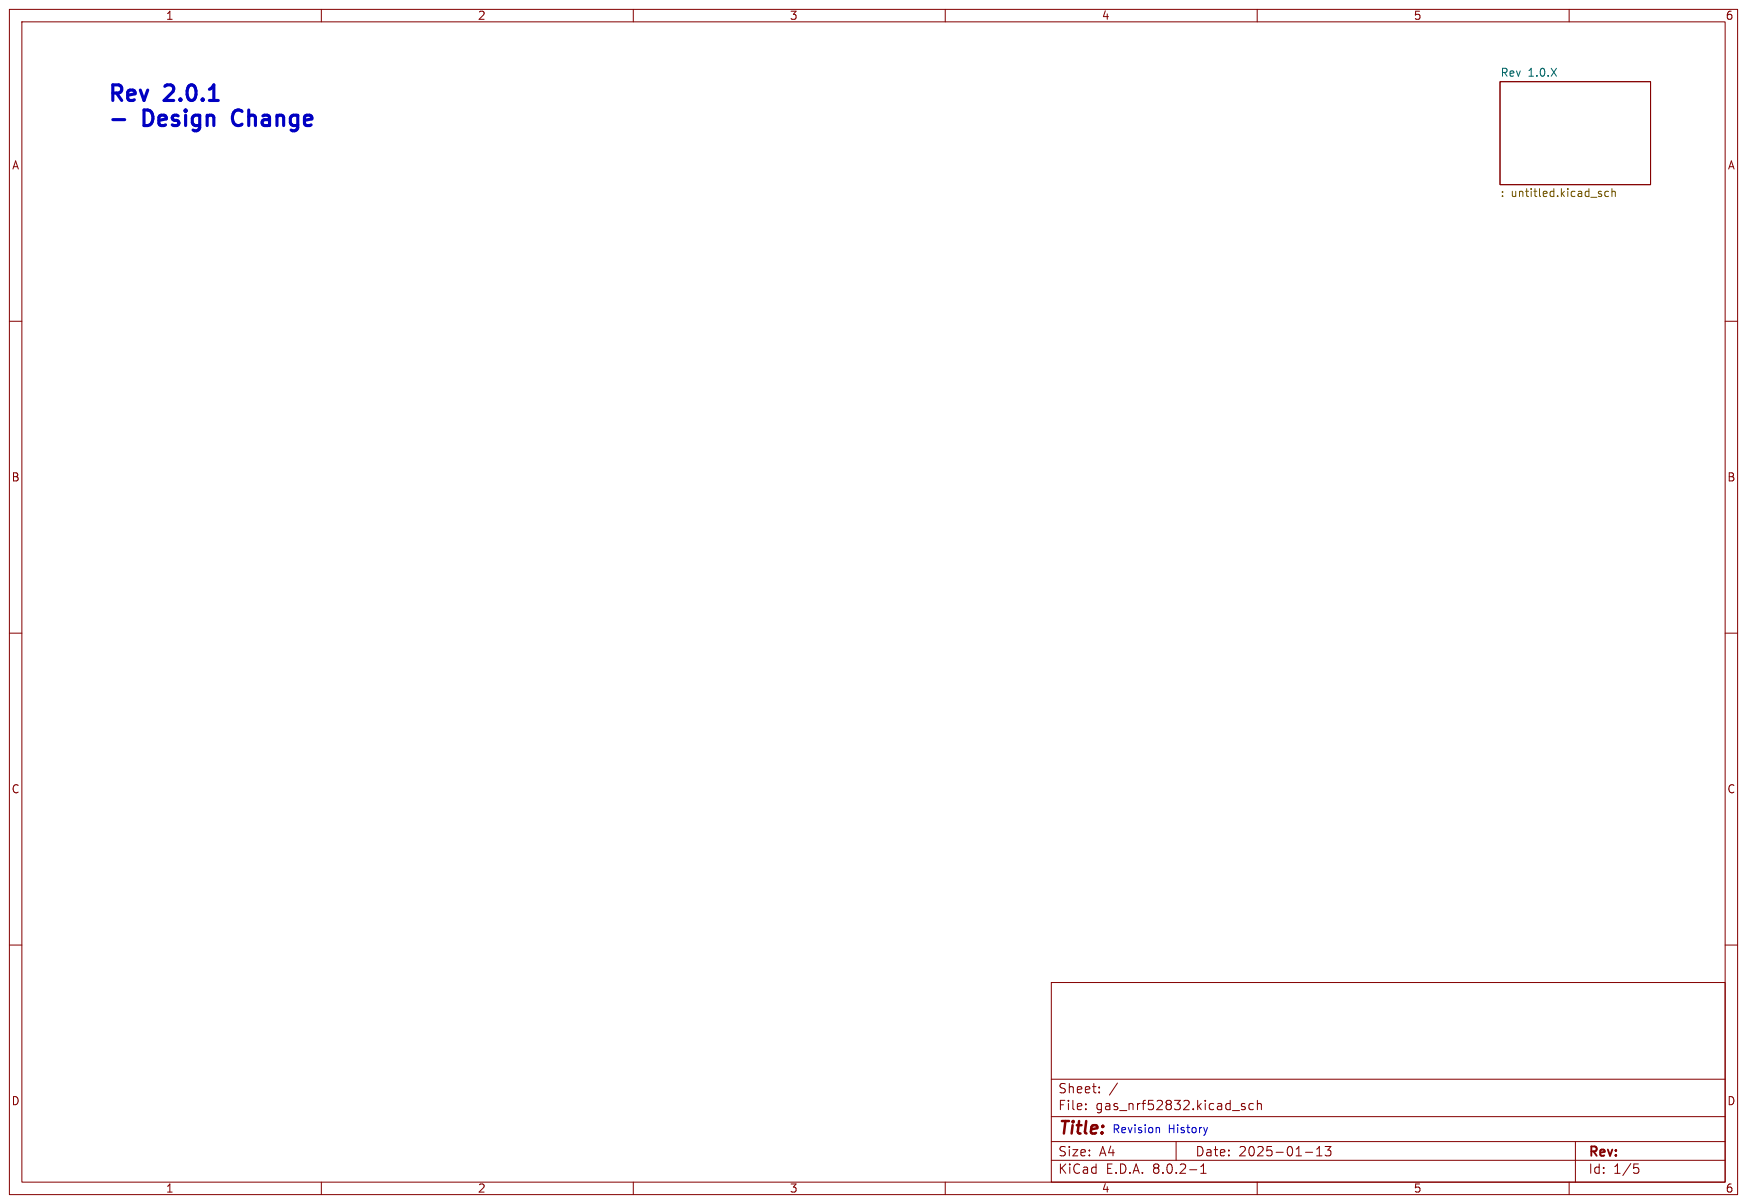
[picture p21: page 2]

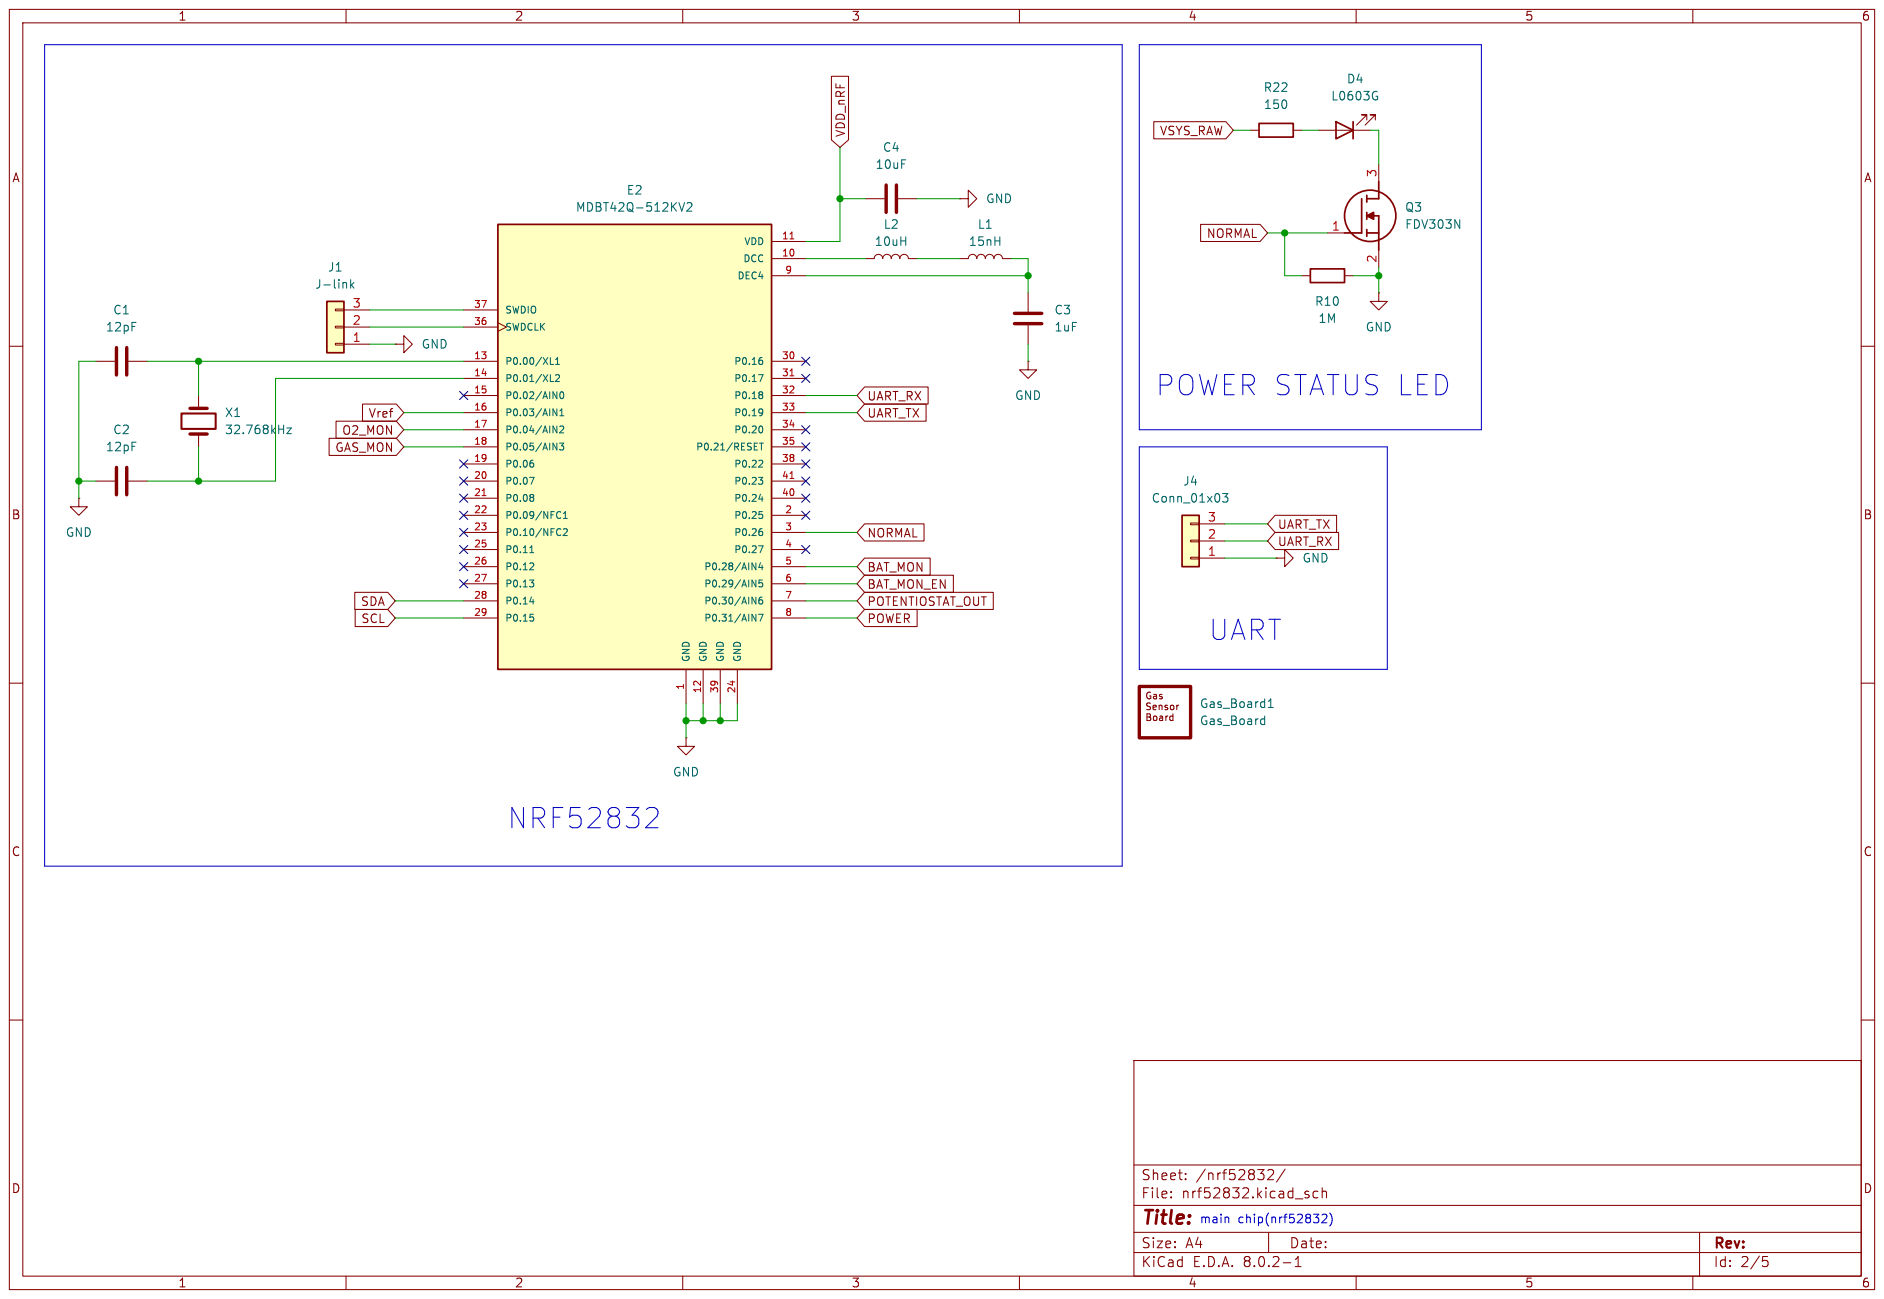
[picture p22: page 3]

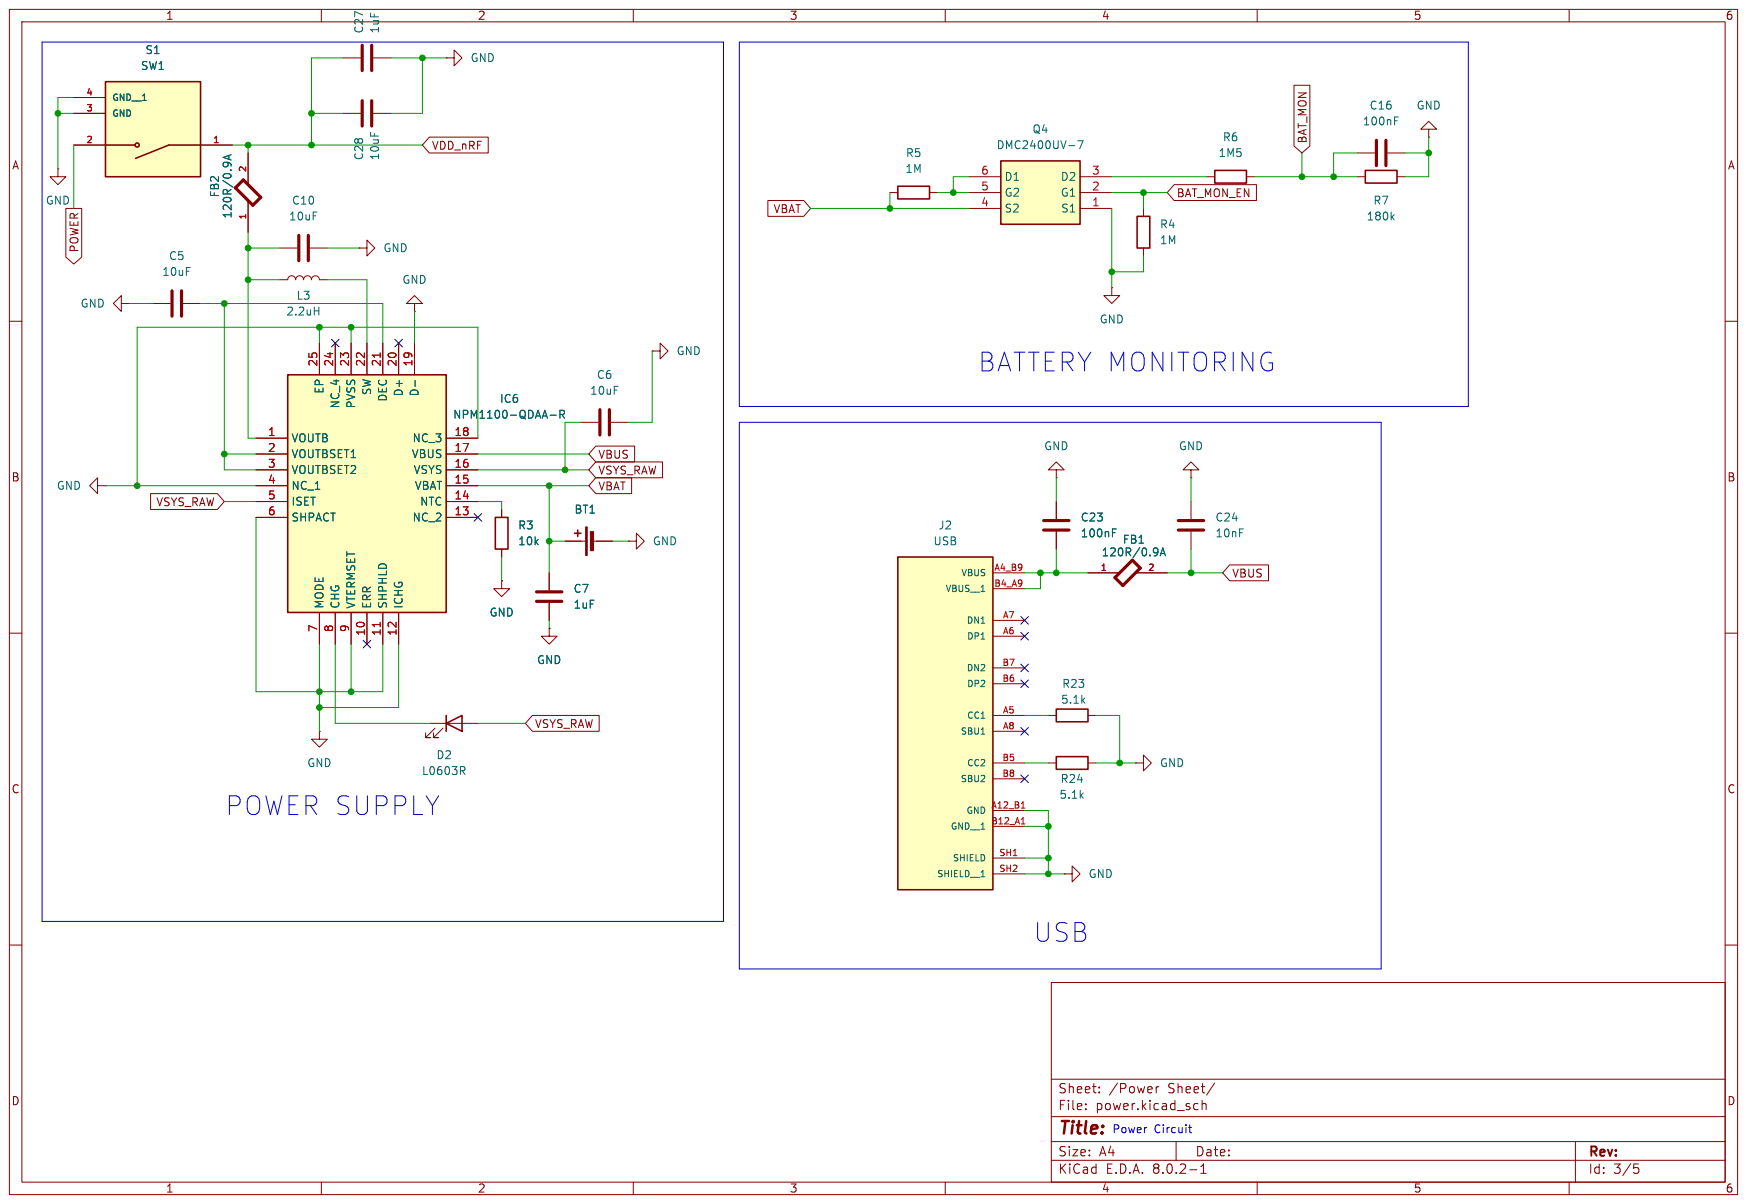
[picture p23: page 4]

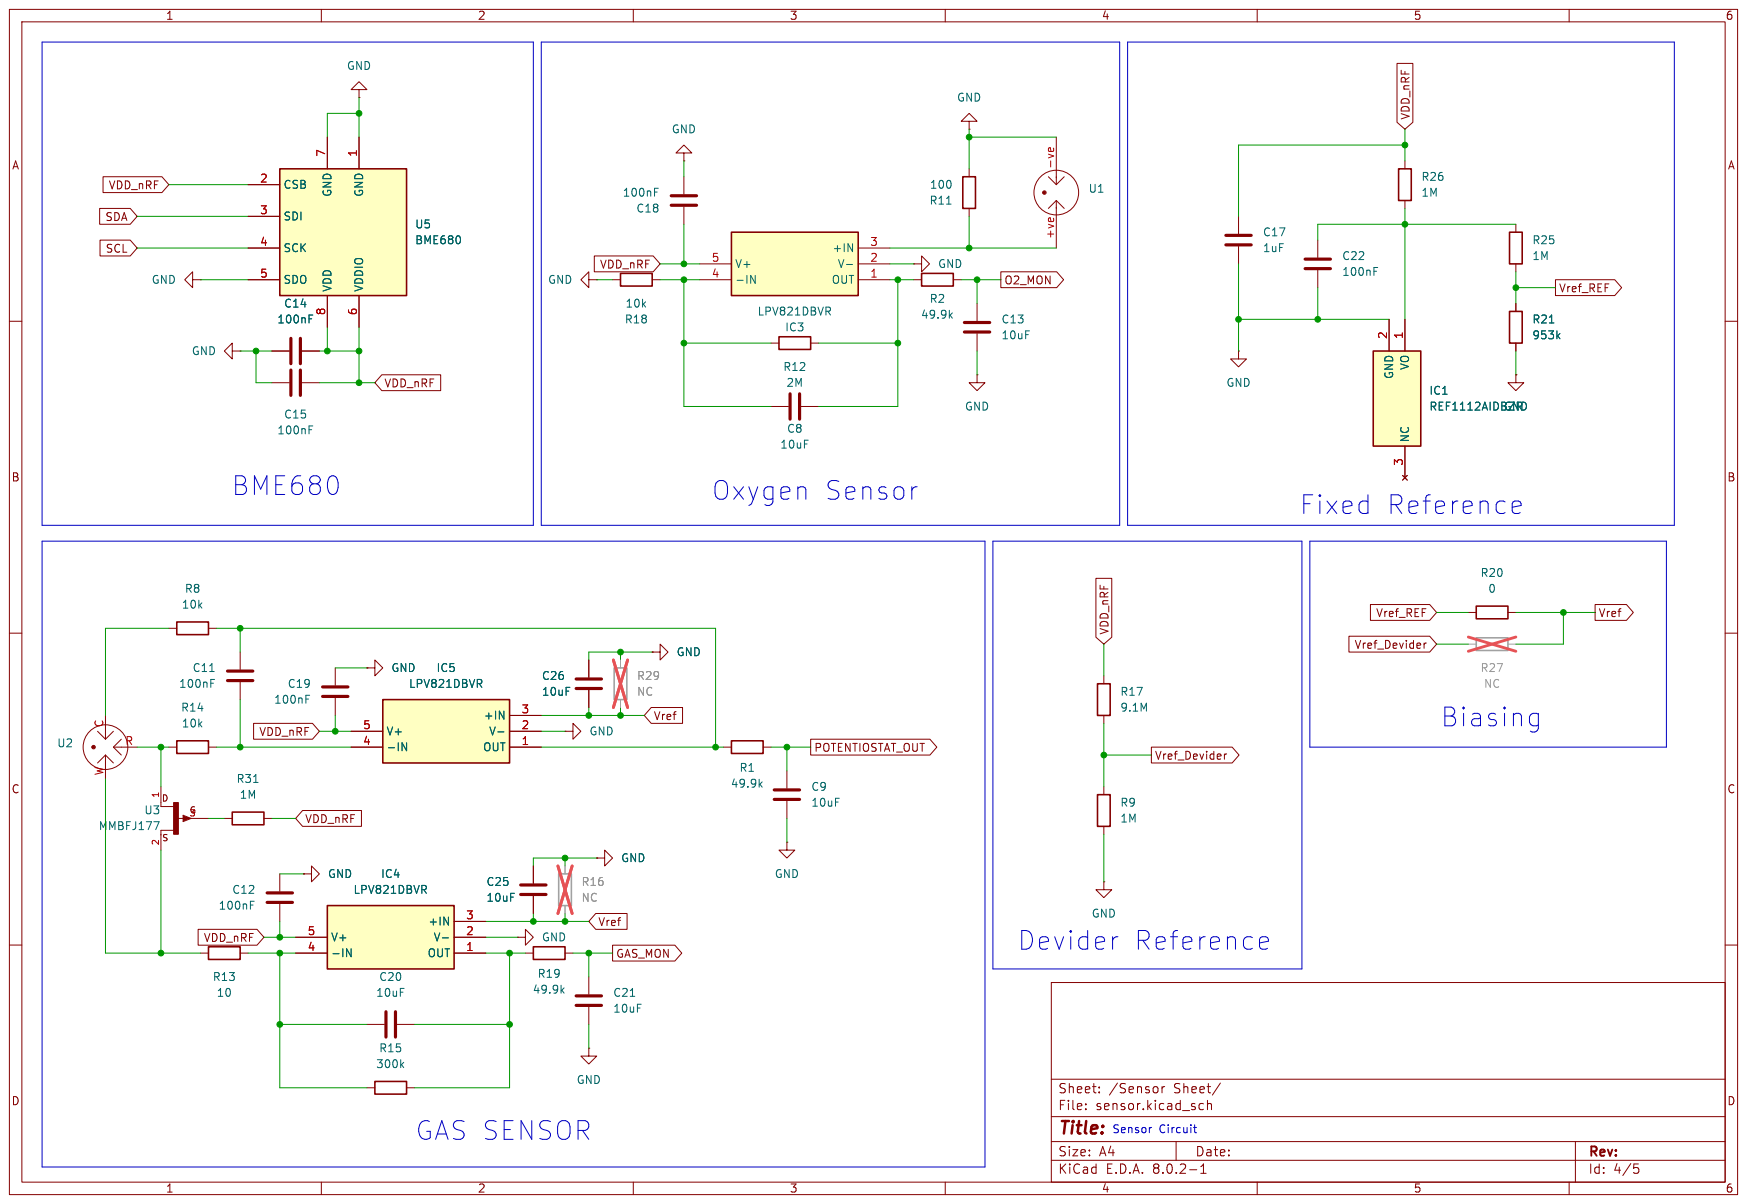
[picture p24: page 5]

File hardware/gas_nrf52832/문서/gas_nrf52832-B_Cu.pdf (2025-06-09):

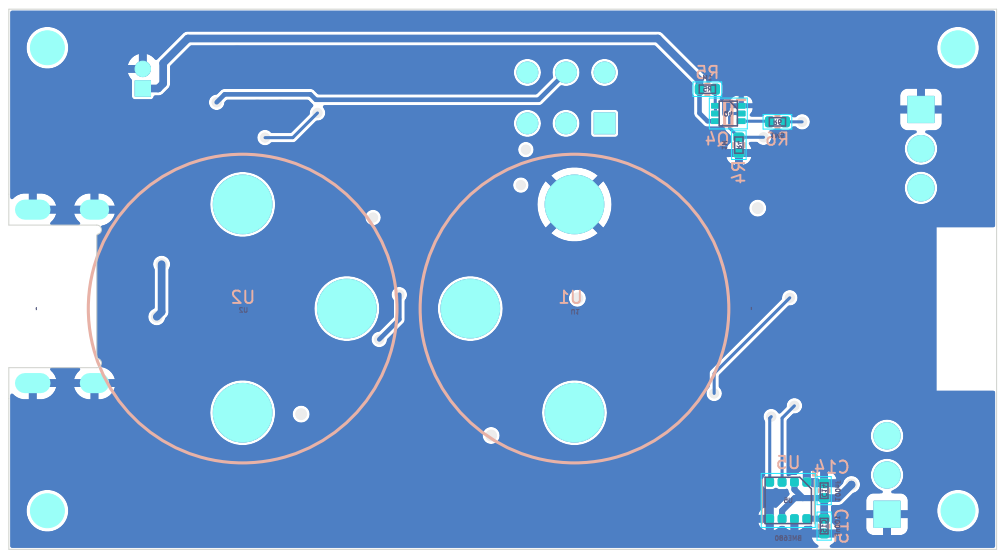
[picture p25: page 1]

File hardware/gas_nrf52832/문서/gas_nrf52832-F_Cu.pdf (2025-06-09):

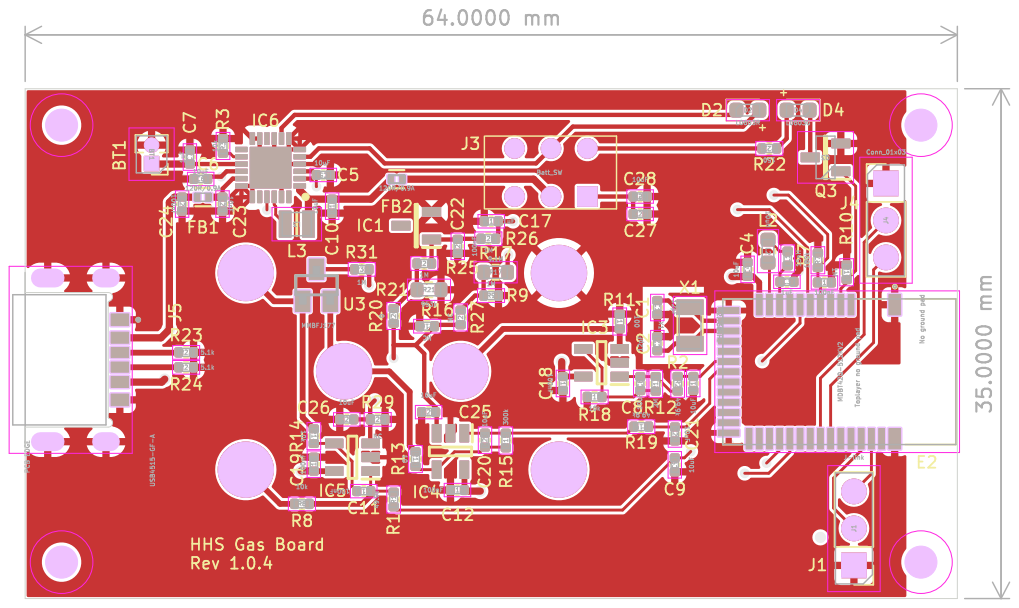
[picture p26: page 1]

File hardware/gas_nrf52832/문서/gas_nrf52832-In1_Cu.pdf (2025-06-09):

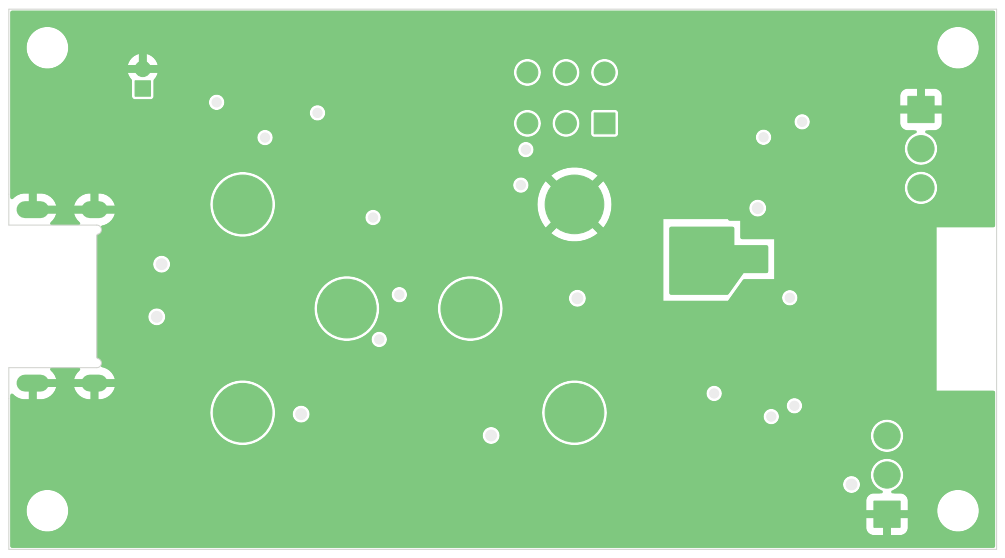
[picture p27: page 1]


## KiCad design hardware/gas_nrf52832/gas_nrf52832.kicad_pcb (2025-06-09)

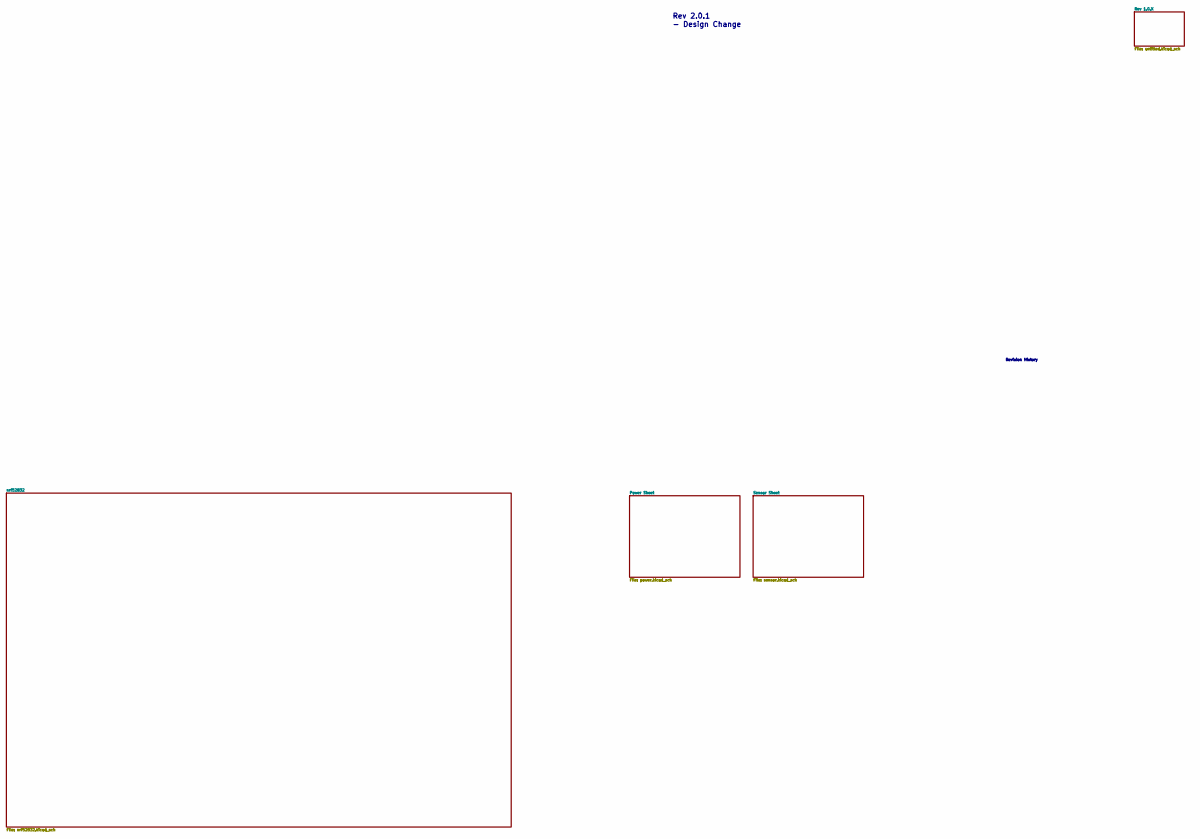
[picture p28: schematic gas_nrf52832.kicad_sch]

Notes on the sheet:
Revision History
Rev 2.0.1 - Design Change

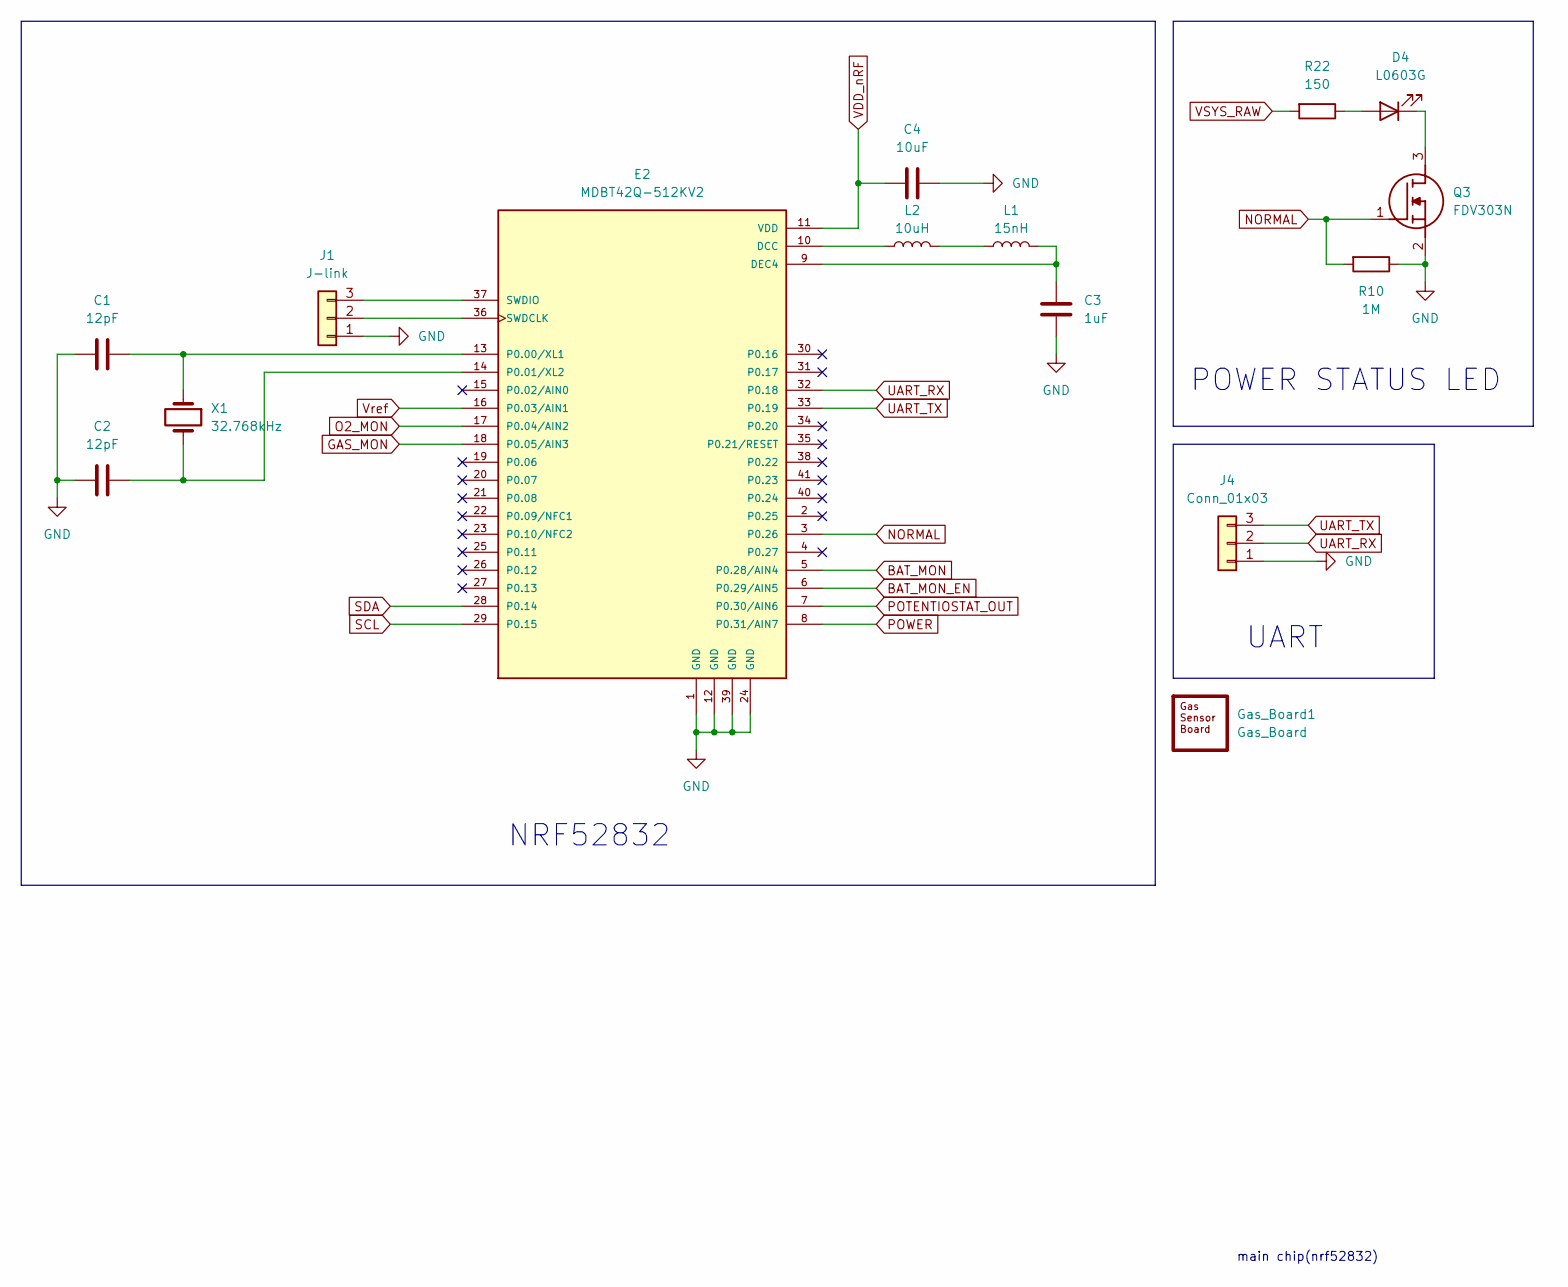
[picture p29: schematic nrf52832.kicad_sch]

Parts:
C1, C2: 12pF; C_0402_1005Metric; Manufacturer_Part_Number CL05C120JB5NNNC
C3: 1uF; C_0402_1005Metric; Manufacturer_Part_Number GRM155C71A105ME11D
C4: 10uF; C_0402_1005Metric; Manufacturer_Part_Number GRM155C80J106ME11D
D4: L0603G; WP1533BQ; Manufacturer_Part_Number WP1533BQ/GD
E2: MDBT42Q-512KV2; RAYTAC_MDBT42Q-512KV2; PARTREV J
Gas_Board1: Gas_Board; gas_nordic_edge
J1: J-link; PinHeader_1x03_P2.54mm_Vertical
J4: Conn_01x03; PinHeader_1x03_P2.54mm_Vertical
L1: 15nH; L_0402_1005Metric; Manufacturer_Part_Number MLG1005S15NJT000
L2: 10uH; L_0603_1608Metric; Manufacturer_Part_Number LQM18FN100M00D
Q3: FDV303N; SOT96P237X111-3N; Manufacturer_Part_Number FDV303N; Mouser Part Number 512-FDV303N
R10: 1M; R_0402_1005Metric; Manufacturer_Part_Number RC0402FR-071ML
R22: 150; R_0402_1005Metric; Manufacturer_Part_Number RM04FTN1500
X1: 32.768kHz; Crystal_SMD_3215-2Pin_3.2x1.5mm; Manufacturer_Part_Number FC-135 32.7680KA-A5

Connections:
BAT_MON: E2.5 (P0.28/AIN4); also elsewhere on the board
BAT_MON_EN: E2.6 (P0.29/AIN5); also elsewhere on the board
GAS_MON: E2.18 (P0.05/AIN3); also elsewhere on the board
GND: C1.1, C2.1, C3.2, C4.2, E2.1 (GND), E2.12 (GND), E2.24 (GND), E2.39 (GND), J1.1, J4.1, Q3.2 (S), R10.1; also elsewhere on the board
NORMAL: E2.3 (P0.26), Q3.1 (G), R10.2
unnamed: D4.2 (A), R22.1
unnamed: D4.1 (K), Q3.3 (D)
unnamed: E2.10 (DCC), L2.1
unnamed: C3.1, E2.9 (DEC4), L1.2
unnamed: C1.2, E2.13 (P0.00/XL1), X1.1
unnamed: C2.2, E2.14 (P0.01/XL2), X1.2
unnamed: E2.36 (SWDCLK), J1.2
unnamed: E2.37 (SWDIO), J1.3
unnamed: L1.1, L2.2
O2_MON: E2.17 (P0.04/AIN2); also elsewhere on the board
POTENTIOSTAT_OUT: E2.7 (P0.30/AIN6); also elsewhere on the board
POWER: E2.8 (P0.31/AIN7); also elsewhere on the board
SCL: E2.29 (P0.15); also elsewhere on the board
SDA: E2.28 (P0.14); also elsewhere on the board
UART_RX: E2.32 (P0.18), J4.2
UART_TX: E2.33 (P0.19), J4.3
VDD_nRF: C4.1, E2.11 (VDD); also elsewhere on the board
VSYS_RAW: R22.2; also elsewhere on the board
Vref: E2.16 (P0.03/AIN1); also elsewhere on the board

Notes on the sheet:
main chip(nrf52832)
NRF52832
UART
POWER STATUS LED

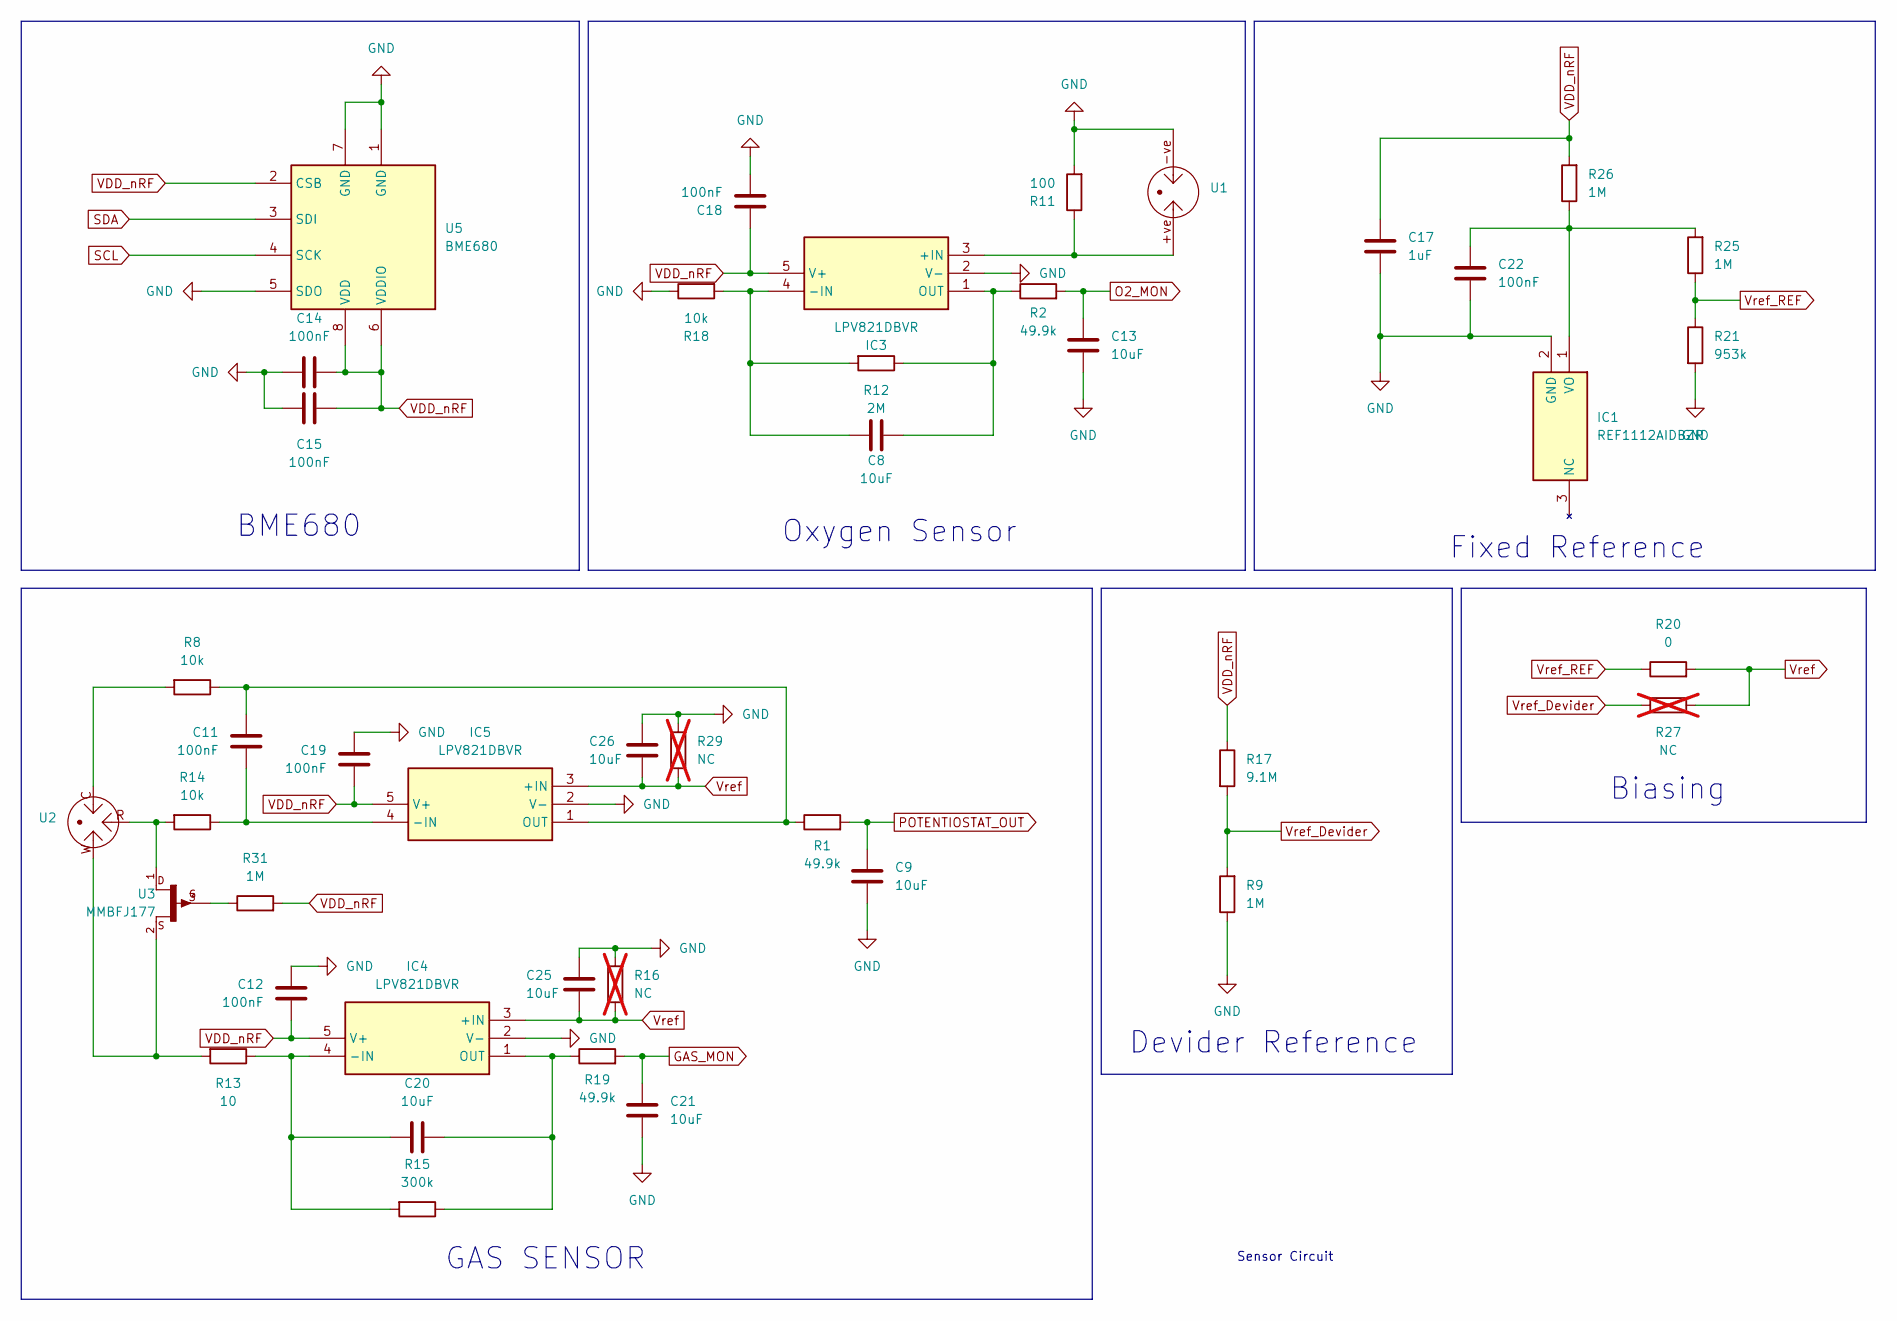
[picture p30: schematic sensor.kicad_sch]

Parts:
C8, C9, C13, C20, C21, C25, C26: 10uF; C_0402_1005Metric; Manufacturer_Part_Number GRM155C80J106ME11D
C11, C12, C14, C15, C18, C19, C22: 100nF; C_0402_1005Metric; Manufacturer_Part_Number CL05B104KO5NNNC
C17: 1uF; C_0402_1005Metric; Manufacturer_Part_Number GRM155C71A105ME11D
IC1: REF1112AIDBZR; SOT95P237X112-3N; Manufacturer_Part_Number REF1112AIDBZR; Mouser Part Number 595-REF1112AIDBZR
IC3, IC4, IC5: LPV821DBVR; SOT95P280X145-5N; Manufacturer_Part_Number LPV821DBVR; Mouser Part Number 595-LPV821DBVR
R1, R2, R19: 49.9k; R_0402_1005Metric; Manufacturer_Part_Number RM04FTN4992
R8, R14, R18: 10k; R_0402_1005Metric; Manufacturer_Part_Number RM04FTN1002
R9, R25, R26, R31: 1M; R_0402_1005Metric; Manufacturer_Part_Number RC0402FR-071ML
R11: 100; R_0402_1005Metric; Manufacturer_Part_Number RC0402FR-07100RL
R12: 2M; R_0402_1005Metric; Manufacturer_Part_Number RC0402FR-072ML
R13: 10; R_0402_1005Metric; Manufacturer_Part_Number RC0402FR-0710RL
R15: 300k; R_0402_1005Metric; Manufacturer_Part_Number WR04X3003FTL
R16, R27, R29: NC; R_0402_1005Metric; not fitted
R17: 9.1M; R_0603_1608Metric; Manufacturer_Part_Number WR06W9104FTL
R20: 0; R_0402_1005Metric; Manufacturer_Part_Number RM04JTN0
R21: 953k; R_0603_1608Metric; Manufacturer_Part_Number WR06X9533FTL
U1: SS2118_O2
U2: SS2198_H2S
U3: MMBFJ177; SOT23; Manufacturer_Part_Number MMBFJ177LT1G
U5: BME680; Bosch_LGA-8_3x3mm_P0.8mm_ClockwisePinNumbering; Manufacturer_Part_Number BME680

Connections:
GAS_MON: C21.2, R19.2; also elsewhere on the board
GND: C9.1, C12.1, C13.1, C14.1, C15.1, C17.1, C18.1, C19.1, C21.1, C22.1, C25.2, C26.2, IC1.2 (GND), IC3.2 (V-), IC4.2 (V-), IC5.2 (V-), R9.1, R11.2, R16.2, R18.1, R21.2, R29.2, U1.-ve, U5.1 (GND), U5.5 (SDO), U5.7 (GND); also elsewhere on the board
unnamed: C22.2, IC1.1 (VO), R25.2, R26.1
unnamed: IC3.3 (+IN), R11.1, U1.+ve
unnamed: C8.2, IC3.4 (-IN), R12.2, R18.2
unnamed: C8.1, IC3.1 (OUT), R2.1, R12.1
unnamed: C20.2, IC4.4 (-IN), R13.1, R15.2
unnamed: C20.1, IC4.1 (OUT), R15.1, R19.1
unnamed: C11.2, IC5.4 (-IN), R14.1
unnamed: C11.1, IC5.1 (OUT), R1.1, R8.1
unnamed: R8.2, U2.C
unnamed: R13.2, U2.W, U3.2
unnamed: R14.2, U2.R, U3.1
unnamed: R31.1, U3.3
O2_MON: C13.2, R2.2; also elsewhere on the board
POTENTIOSTAT_OUT: C9.2, R1.2; also elsewhere on the board
SCL: U5.4 (SCK); also elsewhere on the board
SDA: U5.3 (SDI); also elsewhere on the board
VDD_nRF: C12.2, C14.2, C15.2, C17.2, C18.2, C19.2, IC3.5 (V+), IC4.5 (V+), IC5.5 (V+), R17.1, R26.2, R31.2, U5.2 (CSB), U5.6 (VDDIO), U5.8 (VDD); also elsewhere on the board
Vref: C25.1, C26.1, IC4.3 (+IN), IC5.3 (+IN), R16.1, R20.2, R27.2, R29.1; also elsewhere on the board
Vref_Devider: R9.2, R17.2, R27.1
Vref_REF: R20.1, R21.1, R25.1

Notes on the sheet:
GAS SENSOR
Biasing
Oxygen Sensor
Fixed Reference
BME680
Devider Reference
Sensor Circuit

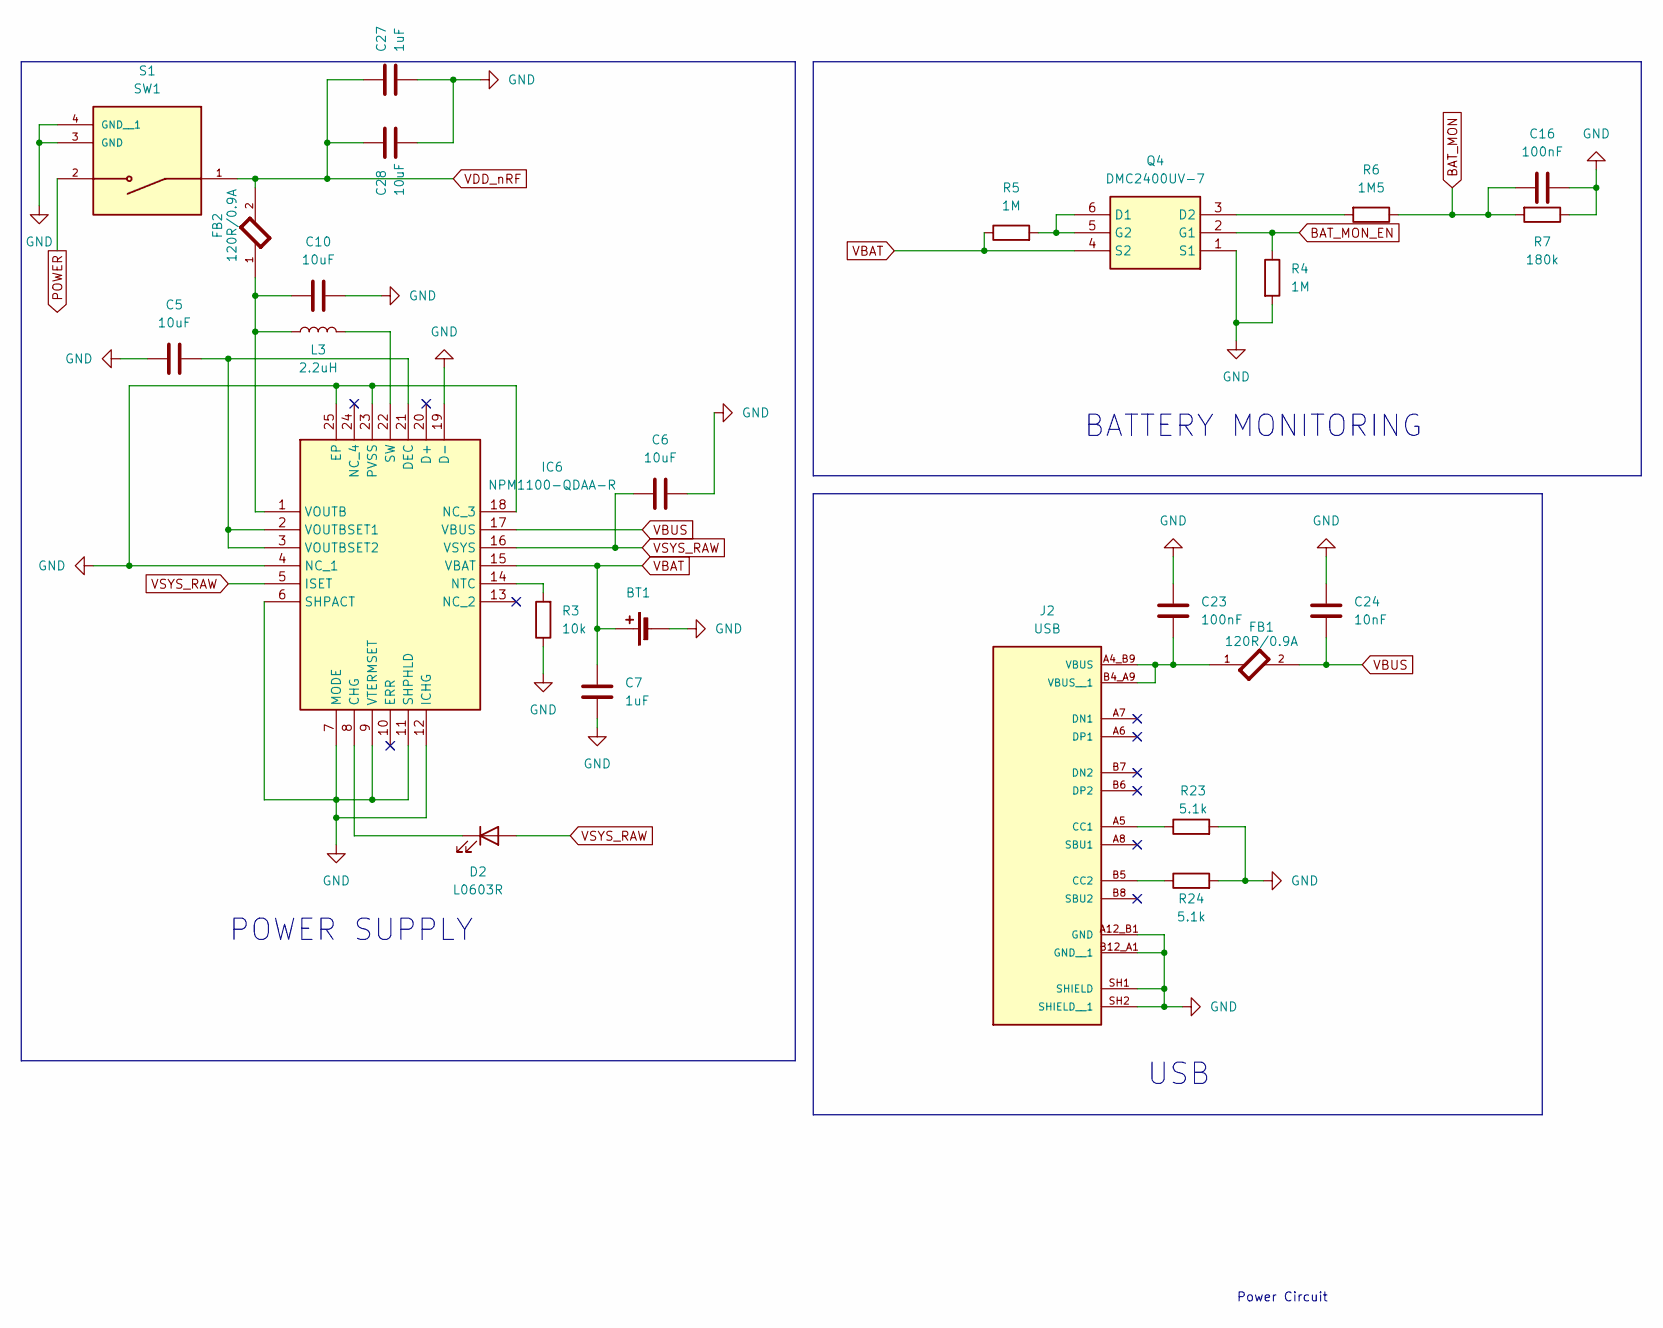
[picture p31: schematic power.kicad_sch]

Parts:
BT1: BT1; PinHeader_1x02_P1.27mm_Vertical
C5, C6, C10, C28: 10uF; C_0402_1005Metric; Manufacturer_Part_Number GRM155C80J106ME11D
C7, C27: 1uF; C_0402_1005Metric; Manufacturer_Part_Number GRM155C71A105ME11D
C16, C23: 100nF; C_0402_1005Metric; Manufacturer_Part_Number CL05B104KO5NNNC
C24: 10nF; C_0402_1005Metric; Manufacturer_Part_Number CL05B103KB5NNNC
D2: L0603R; WP1533BQ; Manufacturer_Part_Number WP1533BQ/ID
FB1, FB2: 120R/0.9A; MURATA_BLM15PE121SH1D_0; Manufacturer_Part_Number BLM15PE121SH1D; DigiKey_Part_Number 490-BLM15PE121SH1DTR-ND
IC6: NPM1100-QDAA-R; QFN50P400X400X90-25N-D; Manufacturer_Part_Number NPM1100-QDAA-R; Mouser Part Number 949-NPM1100-QDAA-R
J2: USB; CUI_UJ20-C-G-MSMT-TR-68; PARTREV 1.0
L3: 2.2uH; 1285ASH1R0MP2; Manufacturer_Part_Number 1285AS-H-2R2M=P2
Q4: DMC2400UV-7; SOTFL50P162X60-6N; Manufacturer_Part_Number DMC2400UV-7; Mouser Part Number N/A
R3: 10k; R_0402_1005Metric; Manufacturer_Part_Number RM04FTN1002
R4, R5: 1M; R_0402_1005Metric; Manufacturer_Part_Number RC0402FR-071ML
R6: 1M5; R_0402_1005Metric; Manufacturer_Part_Number RC0402FR-071M5L
R7: 180k; R_0402_1005Metric; Manufacturer_Part_Number RM04FTN1803
R23, R24: 5.1k; R_0402_1005Metric; Manufacturer_Part_Number RM04FTN5101
S1: SW1; SW_TS11-674-43-BK-100-RA-D; PARTREV 1.01

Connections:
BAT_MON: C16.1, R6.1, R7.2; also elsewhere on the board
BAT_MON_EN: Q4.2 (G1), R4.1; also elsewhere on the board
GND: BT1.2 (-), C5.1, C6.2, C7.1, C10.2, C16.2, C23.1, C24.1, C27.1, C28.1, IC6.4 (NC_1), IC6.6 (SHPACT), IC6.7 (MODE), IC6.9 (VTERMSET), IC6.11 (SHPHLD), IC6.12 (ICHG), IC6.18 (NC_3), IC6.19 (D-), IC6.23 (PVSS), IC6.25 (EP), J2.A12_B1 (GND), J2.B12_A1 (GND__1), J2.SH1 (SHIELD), J2.SH2 (SHIELD__1), Q4.1 (S1), R3.1, R4.2, R7.1, R23.2, R24.2, S1.3 (GND), S1.4 (GND__1); also elsewhere on the board
unnamed: D2.1 (K), IC6.8 (CHG)
unnamed: C5.2, IC6.2 (VOUTBSET1), IC6.3 (VOUTBSET2), IC6.21 (DEC)
unnamed: IC6.14 (NTC), R3.2
unnamed: IC6.22 (SW), L3.2
unnamed: C10.1, FB2.1, IC6.1 (VOUTB), L3.1
unnamed: J2.A5 (CC1), R23.1
unnamed: J2.B5 (CC2), R24.1
unnamed: C23.2, FB1.1, J2.A4_B9 (VBUS), J2.B4_A9 (VBUS__1)
unnamed: Q4.5 (G2), Q4.6 (D1), R5.2
unnamed: Q4.3 (D2), R6.2
POWER: S1.2; also elsewhere on the board
VBAT: BT1.1 (+), C7.2, IC6.15 (VBAT), Q4.4 (S2), R5.1
VBUS: C24.2, FB1.2, IC6.17 (VBUS)
VDD_nRF: C27.2, C28.2, FB2.2, S1.1; also elsewhere on the board
VSYS_RAW: C6.1, D2.2 (A), IC6.5 (ISET), IC6.16 (VSYS); also elsewhere on the board

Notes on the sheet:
Power Circuit
POWER SUPPLY
BATTERY MONITORING
USB

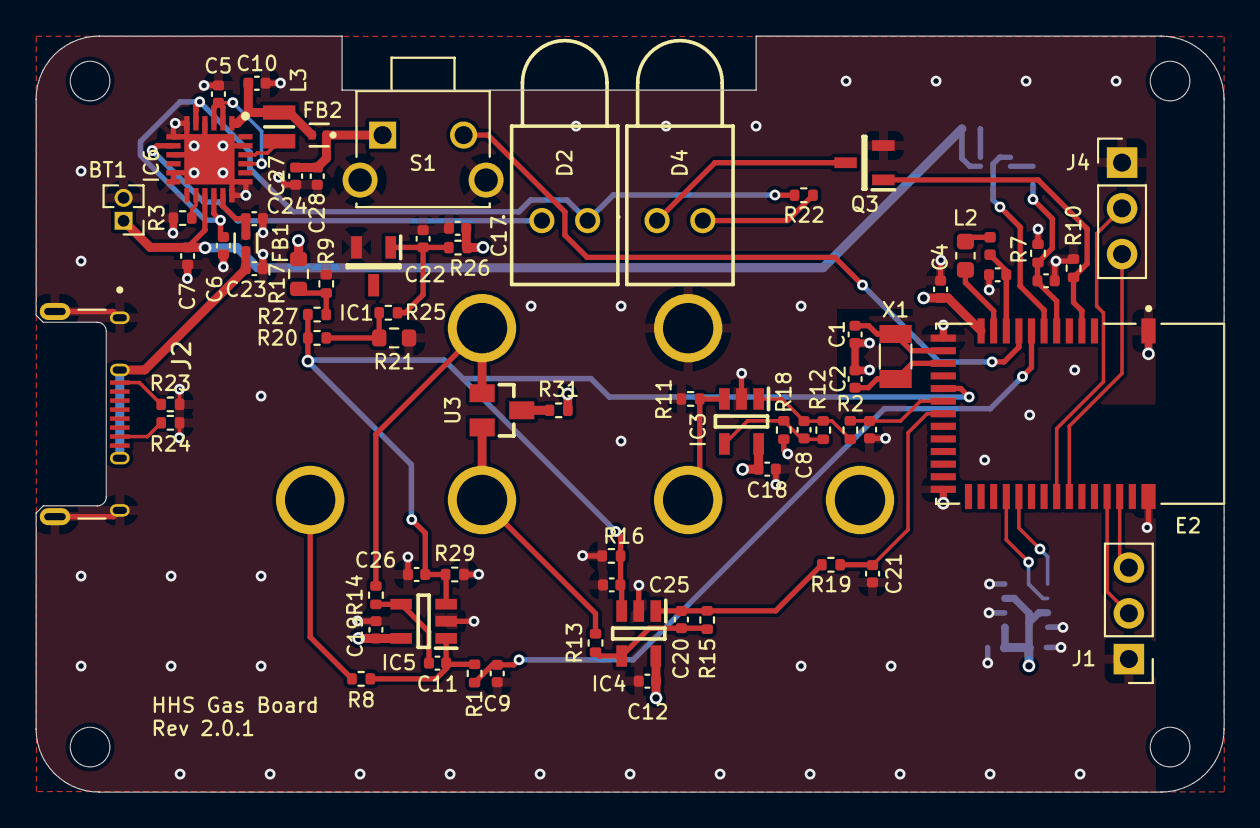
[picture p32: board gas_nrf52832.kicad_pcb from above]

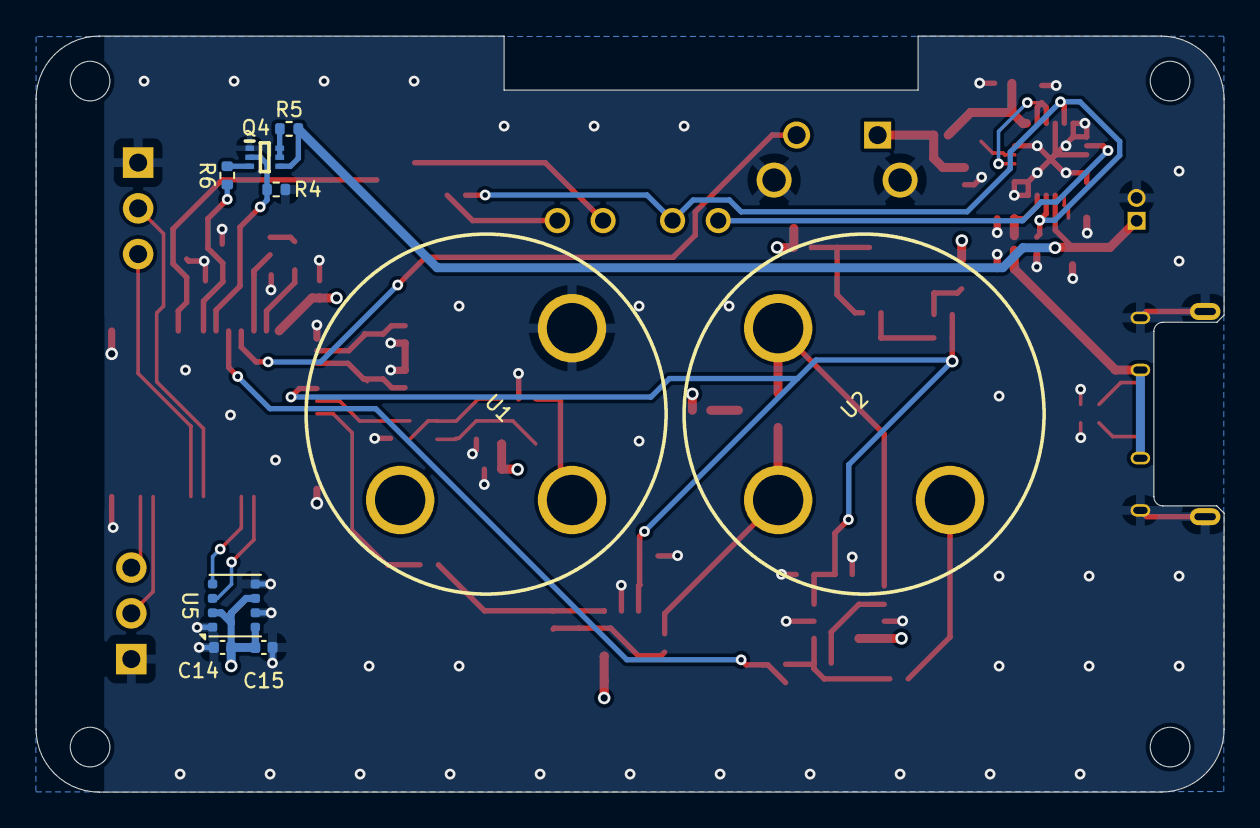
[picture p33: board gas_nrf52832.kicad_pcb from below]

Board: 4 copper layers, 66.0 x 42.0 mm, 83 parts (9 on the bottom side), 50 nets.

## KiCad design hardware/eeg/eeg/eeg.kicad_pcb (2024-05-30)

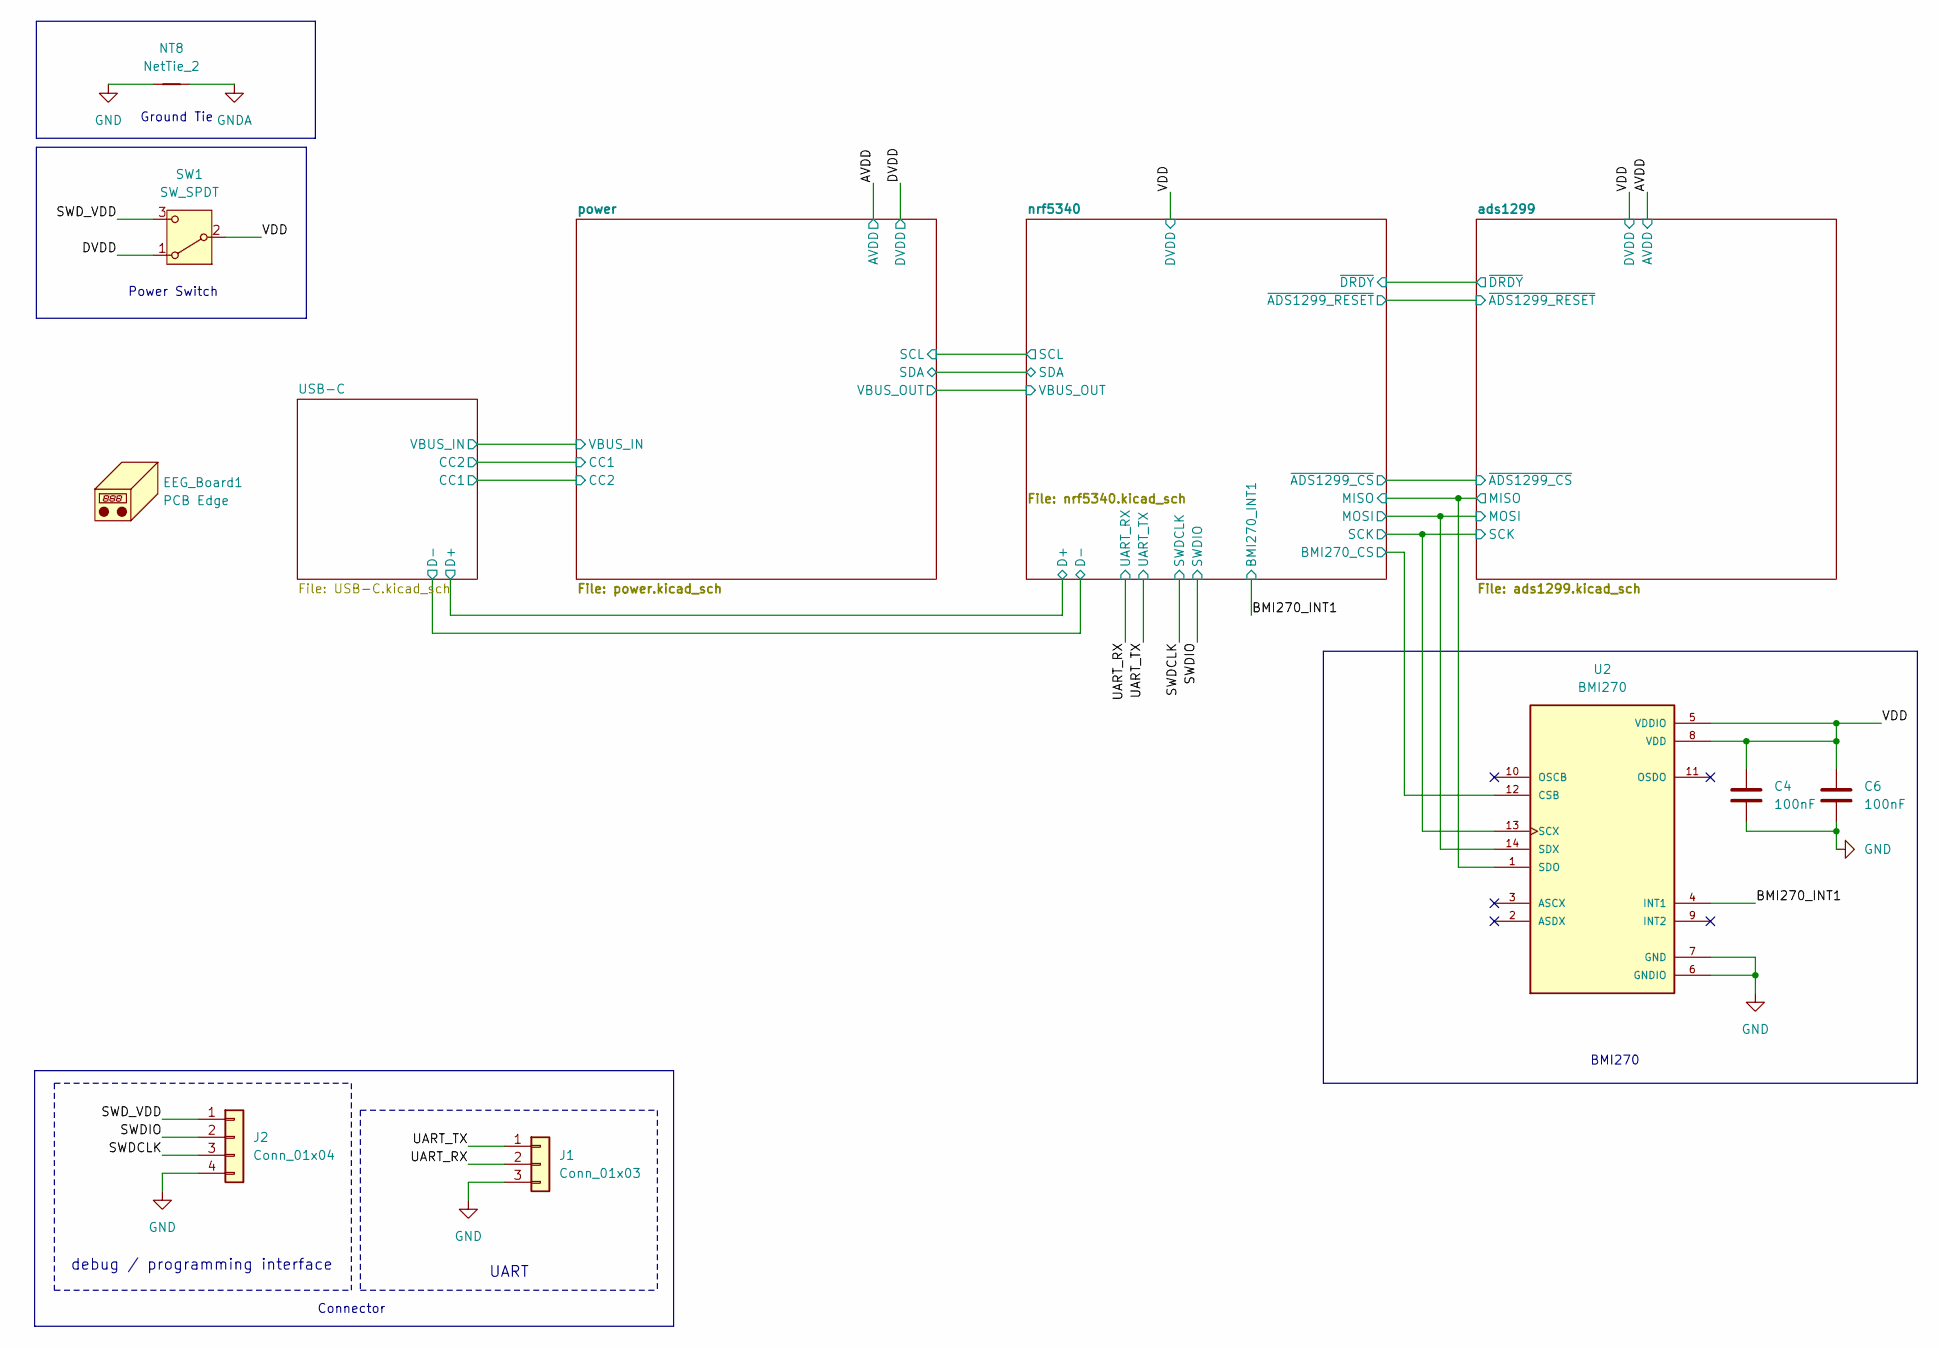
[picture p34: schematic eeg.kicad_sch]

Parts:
C4, C6: 100nF; C_0402_1005Metric; MANUFACTURER_PART_NUMBER GRM155R71C104KA88D
EEG_Board1: PCB Edge; eeg
J1: Conn_01x03; PinHeader_1x03_P1.27mm_Vertical; MANUFACTURER_PART_NUMBER 1.25T-3A
J2: Conn_01x04; PinHeader_1x04_P1.27mm_Vertical; MANUFACTURER_PART_NUMBER 1.25T-4A
NT8: NetTie_2; NetTie-2_SMD_Pad0.5mm
SW1: SW_SPDT; SK12D07VG4NSPA_CNK; MANUFACTURER_PART_NUMBER SK12D07VG5
U2: BMI270; XDCR_BMI270; MANUFACTURER_PART_NUMBER BMI270

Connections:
/BMI270_INT1: U2.4 (INT1); also elsewhere on the board
/DVDD: SW1.1 (A); also elsewhere on the board
/SWDCLK: J2.3; also elsewhere on the board
/SWDIO: J2.2; also elsewhere on the board
/SWD_VDD: J2.1, SW1.3 (C)
/UART_RX: J1.2; also elsewhere on the board
/UART_TX: J1.1; also elsewhere on the board
/VDD: C4.1, C6.1, SW1.2 (B), U2.5 (VDDIO), U2.8 (VDD); also elsewhere on the board
/ads1299/MISO: U2.1 (SDO); also elsewhere on the board
/ads1299/MOSI: U2.14 (SDX); also elsewhere on the board
/ads1299/SCK: U2.13 (SCX); also elsewhere on the board
/nrf5340/BMI270_CS: U2.12 (CSB); also elsewhere on the board
GND: C4.2, C6.2, J1.3, J2.4, NT8.1, U2.6 (GNDIO), U2.7 (GND); also elsewhere on the board
GNDA: NT8.2; also elsewhere on the board

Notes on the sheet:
Ground Tie
UART
Connector
BMI270
Power Switch
debug / programming interface

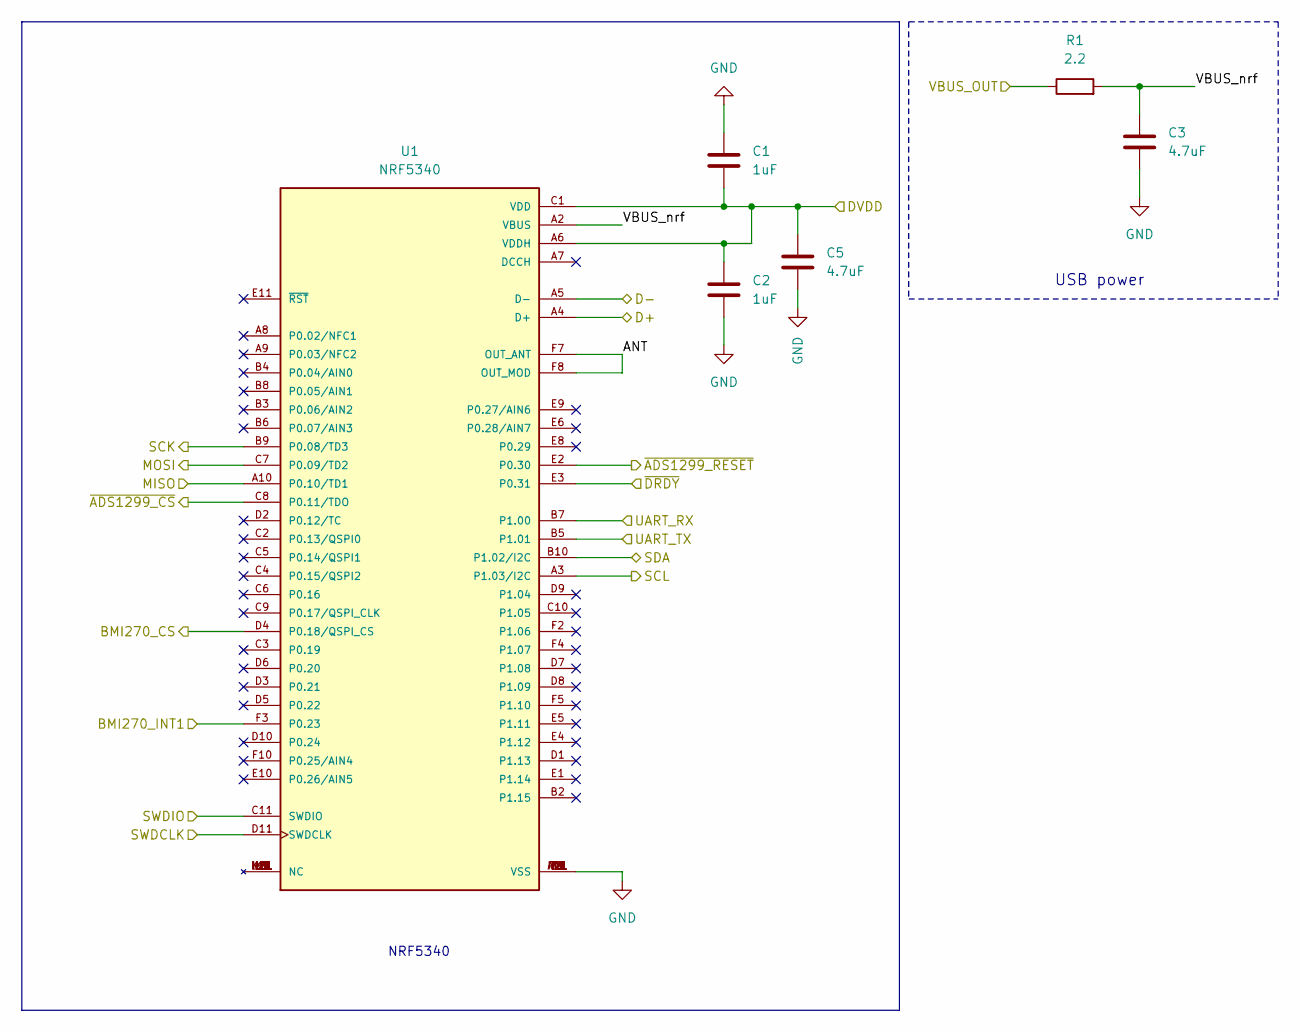
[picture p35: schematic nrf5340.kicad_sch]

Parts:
C1, C2: 1uF; C_0402_1005Metric; MANUFACTURER_PART_NUMBER GRM155R61A105KE15D
C3, C5: 4.7uF; C_0402_1005Metric; MANUFACTURER_PART_NUMBER GRM155R61A475MEAAD
R1: 2.2; R_0402_1005Metric; MANUFACTURER_PART_NUMBER RC0402FR-072R2L
U1: NRF5340; XCVR_ISP2053-AX-RS; PARTREV R6

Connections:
/BMI270_INT1: U1.F3 (P0.23); also elsewhere on the board
/SWDCLK: U1.D11 (SWDCLK); also elsewhere on the board
/SWDIO: U1.C11 (SWDIO); also elsewhere on the board
/UART_RX: U1.B7 (P1.00); also elsewhere on the board
/UART_TX: U1.B5 (P1.01); also elsewhere on the board
/USB-C/D+: U1.A4 (D+); also elsewhere on the board
/USB-C/D-: U1.A5 (D-); also elsewhere on the board
/VDD: C1.2, C2.1, C5.1, U1.A6 (VDDH), U1.C1 (VDD); also elsewhere on the board
/ads1299/MISO: U1.A10 (P0.10/TD1); also elsewhere on the board
/ads1299/MOSI: U1.C7 (P0.09/TD2); also elsewhere on the board
/ads1299/SCK: U1.B9 (P0.08/TD3); also elsewhere on the board
/ads1299/~ADS1299_CS: U1.C8 (P0.11/TDO); also elsewhere on the board
/ads1299/~ADS1299_RESET: U1.E2 (P0.30); also elsewhere on the board
/ads1299/~DRDY: U1.E3 (P0.31); also elsewhere on the board
/nrf5340/ANT: U1.F7 (OUT_ANT), U1.F8 (OUT_MOD)
/nrf5340/BMI270_CS: U1.D4 (P0.18/QSPI_CS); also elsewhere on the board
/nrf5340/SCL: U1.A3 (P1.03/I2C); also elsewhere on the board
/nrf5340/SDA: U1.B10 (P1.02/I2C); also elsewhere on the board
/nrf5340/VBUS_OUT: R1.1; also elsewhere on the board
/nrf5340/VBUS_nrf: C3.1, R1.2, U1.A2 (VBUS)
GND: C1.1, C2.2, C3.2, C5.2, U1.A1 (VSS), U1.A11 (VSS), U1.E7 (VSS), U1.F1 (VSS), U1.F6 (VSS), U1.F9 (VSS), U1.F11 (VSS); also elsewhere on the board

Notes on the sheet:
NRF5340
USB power

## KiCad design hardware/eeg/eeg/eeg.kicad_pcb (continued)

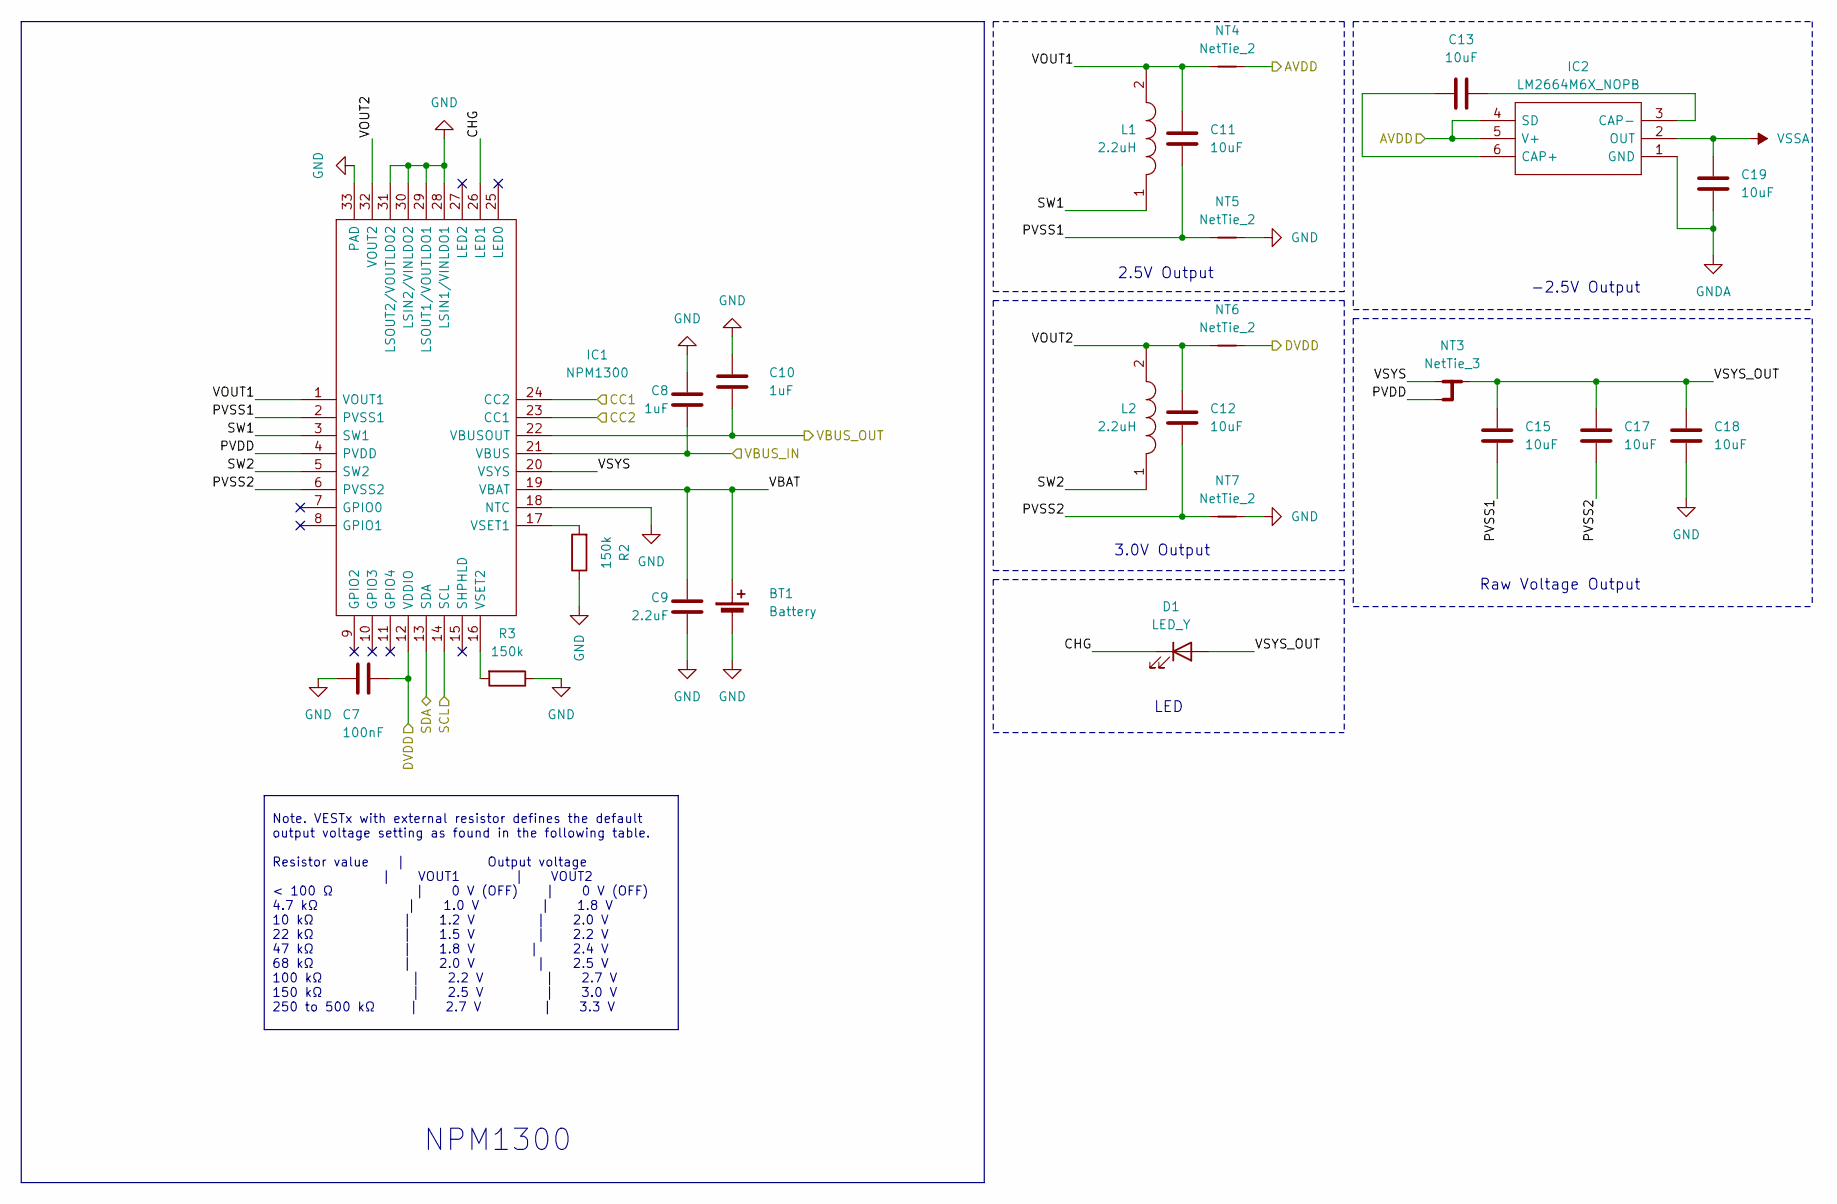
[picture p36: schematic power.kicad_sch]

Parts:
BT1: Battery; PinHeader_1x02_P1.27mm_Vertical; MANUFACTURER_PART_NUMBER 1.25T-2A
C7: 100nF; C_0402_1005Metric; MANUFACTURER_PART_NUMBER GRM155R71C104KA88D
C8, C10: 1uF; C_0402_1005Metric; MANUFACTURER_PART_NUMBER GRM155R61A105KE15D
C9: 2.2uF; C_0402_1005Metric; MANUFACTURER_PART_NUMBER GRM155Z71A225KE01D
C11, C12, C13, C15, C17, C18, C19: 10uF; C_0402_1005Metric; MANUFACTURER_PART_NUMBER GRM155R61A106ME44D
D1: LED_Y; LED_0603_1608Metric; MANUFACTURER_PART_NUMBER 19-213/Y2C-CQ2R2L/3T(CY)
IC1: NPM1300; QFN50P500X500X90-33N; Manufacturer_Part_Number NPM1300-QEAA-R; Mouser Part Number 949-NPM1300-QEAA-R
IC2: LM2664M6X_NOPB; SOT95P280X145-6N; Manufacturer_Part_Number LM2664M6X/NOPB; Mouser Part Number 926-LM2664M6X/NOPB
L1, L2: 2.2uH; INDC2016X100N; Manufacturer_Part_Number MLP2016H2R2MT0S1; Mouser Part Number 810-MLP2016H2R2MT0S1
NT3: NetTie_3; NetTie-3_SMD_Pad0.5mm
NT4, NT5, NT6, NT7: NetTie_2; NetTie-2_SMD_Pad0.5mm
R2, R3: 150k; R_0402_1005Metric; MANUFACTURER_PART_NUMBER RC0402FR-07150KL

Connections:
/AVDD: IC2.4 (SD), IC2.5 (V+), NT4.2; also elsewhere on the board
/DVDD: C7.1, IC1.12 (VDDIO), NT6.2; also elsewhere on the board
/USB-C/CC1: IC1.23 (CC1); also elsewhere on the board
/USB-C/CC2: IC1.24 (CC2); also elsewhere on the board
/USB-C/VBUS_IN: C8.1, IC1.21 (VBUS); also elsewhere on the board
/nrf5340/SCL: IC1.14 (SCL); also elsewhere on the board
/nrf5340/SDA: IC1.13 (SDA); also elsewhere on the board
/nrf5340/VBUS_OUT: C10.1, IC1.22 (VBUSOUT); also elsewhere on the board
/power/CHG: D1.1 (K), IC1.26 (LED1)
/power/PVDD: IC1.4 (PVDD), NT3.3
/power/PVSS1: C11.1, C15.1, IC1.2 (PVSS1), NT5.1
/power/PVSS2: C12.1, C17.1, IC1.6 (PVSS2), NT7.1
/power/SW1: IC1.3 (SW1), L1.1
/power/SW2: IC1.5 (SW2), L2.1
/power/VBAT: BT1.1 (+), C9.2, IC1.19 (VBAT)
/power/VOUT1: C11.2, IC1.1 (VOUT1), L1.2, NT4.1
/power/VOUT2: C12.2, IC1.32 (VOUT2), L2.2, NT6.1
/power/VSYS: IC1.20 (VSYS), NT3.1
/power/VSYS_OUT: C15.2, C17.2, C18.2, D1.2 (A), NT3.2
GND: BT1.2 (-), C7.2, C8.2, C9.1, C10.2, C18.1, IC1.18 (NTC), IC1.28 (LSIN1/VINLDO1), IC1.29 (LSOUT1/VOUTLDO1), IC1.30 (LSIN2/VINLDO2), IC1.31 (LSOUT2/VOUTLDO2), IC1.33 (PAD), NT5.2, NT7.2, R2.1, R3.1; also elsewhere on the board
GNDA: C19.1, IC2.1 (GND); also elsewhere on the board
unnamed: IC1.17 (VSET1), R2.2
unnamed: IC1.16 (VSET2), R3.2
unnamed: C13.1, IC2.6 (CAP+)
unnamed: C13.2, IC2.3 (CAP-)
VSSA: C19.2, IC2.2 (OUT); also elsewhere on the board

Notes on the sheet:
Note. VESTx with external resistor defines the default output voltage setting as found in the following table. Resistor value | Output voltage | VOUT1 | VOUT2 < 100 Ω | 0 V (OFF) | 0 V (OFF) 4.7 kΩ | 1.0 V | 1.8 V 10 kΩ | 1.2 V | 2.0 V 22 kΩ | 1.5 V | 2.2 V 47 kΩ | 1.8 V | 2.4 V 68 kΩ | 2.0 V | 2.5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
-2.5V Output
Raw Voltage Output
3.0V Output
2.5V Output
LED
NPM1300

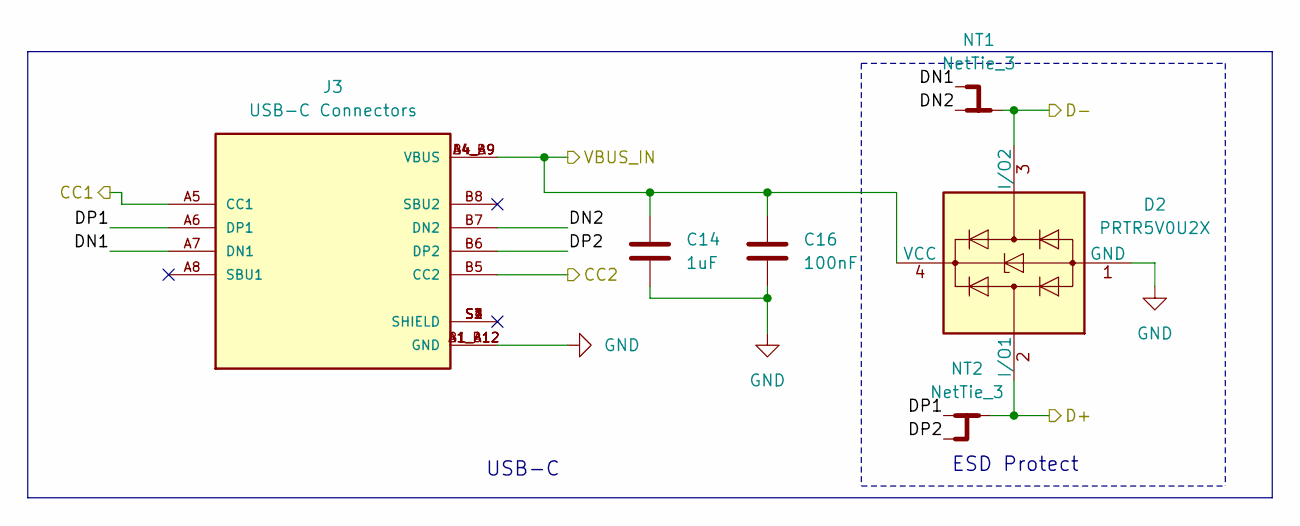
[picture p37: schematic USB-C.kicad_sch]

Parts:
C14: 1uF; C_0402_1005Metric; MANUFACTURER_PART_NUMBER GRM155R61A105KE15D
C16: 100nF; C_0402_1005Metric; MANUFACTURER_PART_NUMBER GRM155R71C104KA88D
D2: PRTR5V0U2X; SOT-143; MANUFACTURER_PART_NUMBER PRTR5V0U2X,215
J3: USB-C Connectors; HRO_TYPE-C-31-M-12; PARTREV 2020.12.08
NT1, NT2: NetTie_3; NetTie-3_SMD_Pad0.5mm

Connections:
/USB-C/CC1: J3.A5 (CC1); also elsewhere on the board
/USB-C/CC2: J3.B5 (CC2); also elsewhere on the board
/USB-C/D+: D2.2 (I/O1), NT2.2; also elsewhere on the board
/USB-C/D-: D2.3 (I/O2), NT1.2; also elsewhere on the board
/USB-C/DN1: J3.A7 (DN1), NT1.3
/USB-C/DN2: J3.B7 (DN2), NT1.1
/USB-C/DP1: J3.A6 (DP1), NT2.1
/USB-C/DP2: J3.B6 (DP2), NT2.3
/USB-C/VBUS_IN: C14.2, C16.2, D2.4 (VCC), J3.A4_B9 (VBUS), J3.B4_A9 (VBUS); also elsewhere on the board
GND: C14.1, C16.1, D2.1 (GND), J3.A1_B12 (GND), J3.B1_A12 (GND); also elsewhere on the board

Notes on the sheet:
ESD Protect
USB-C

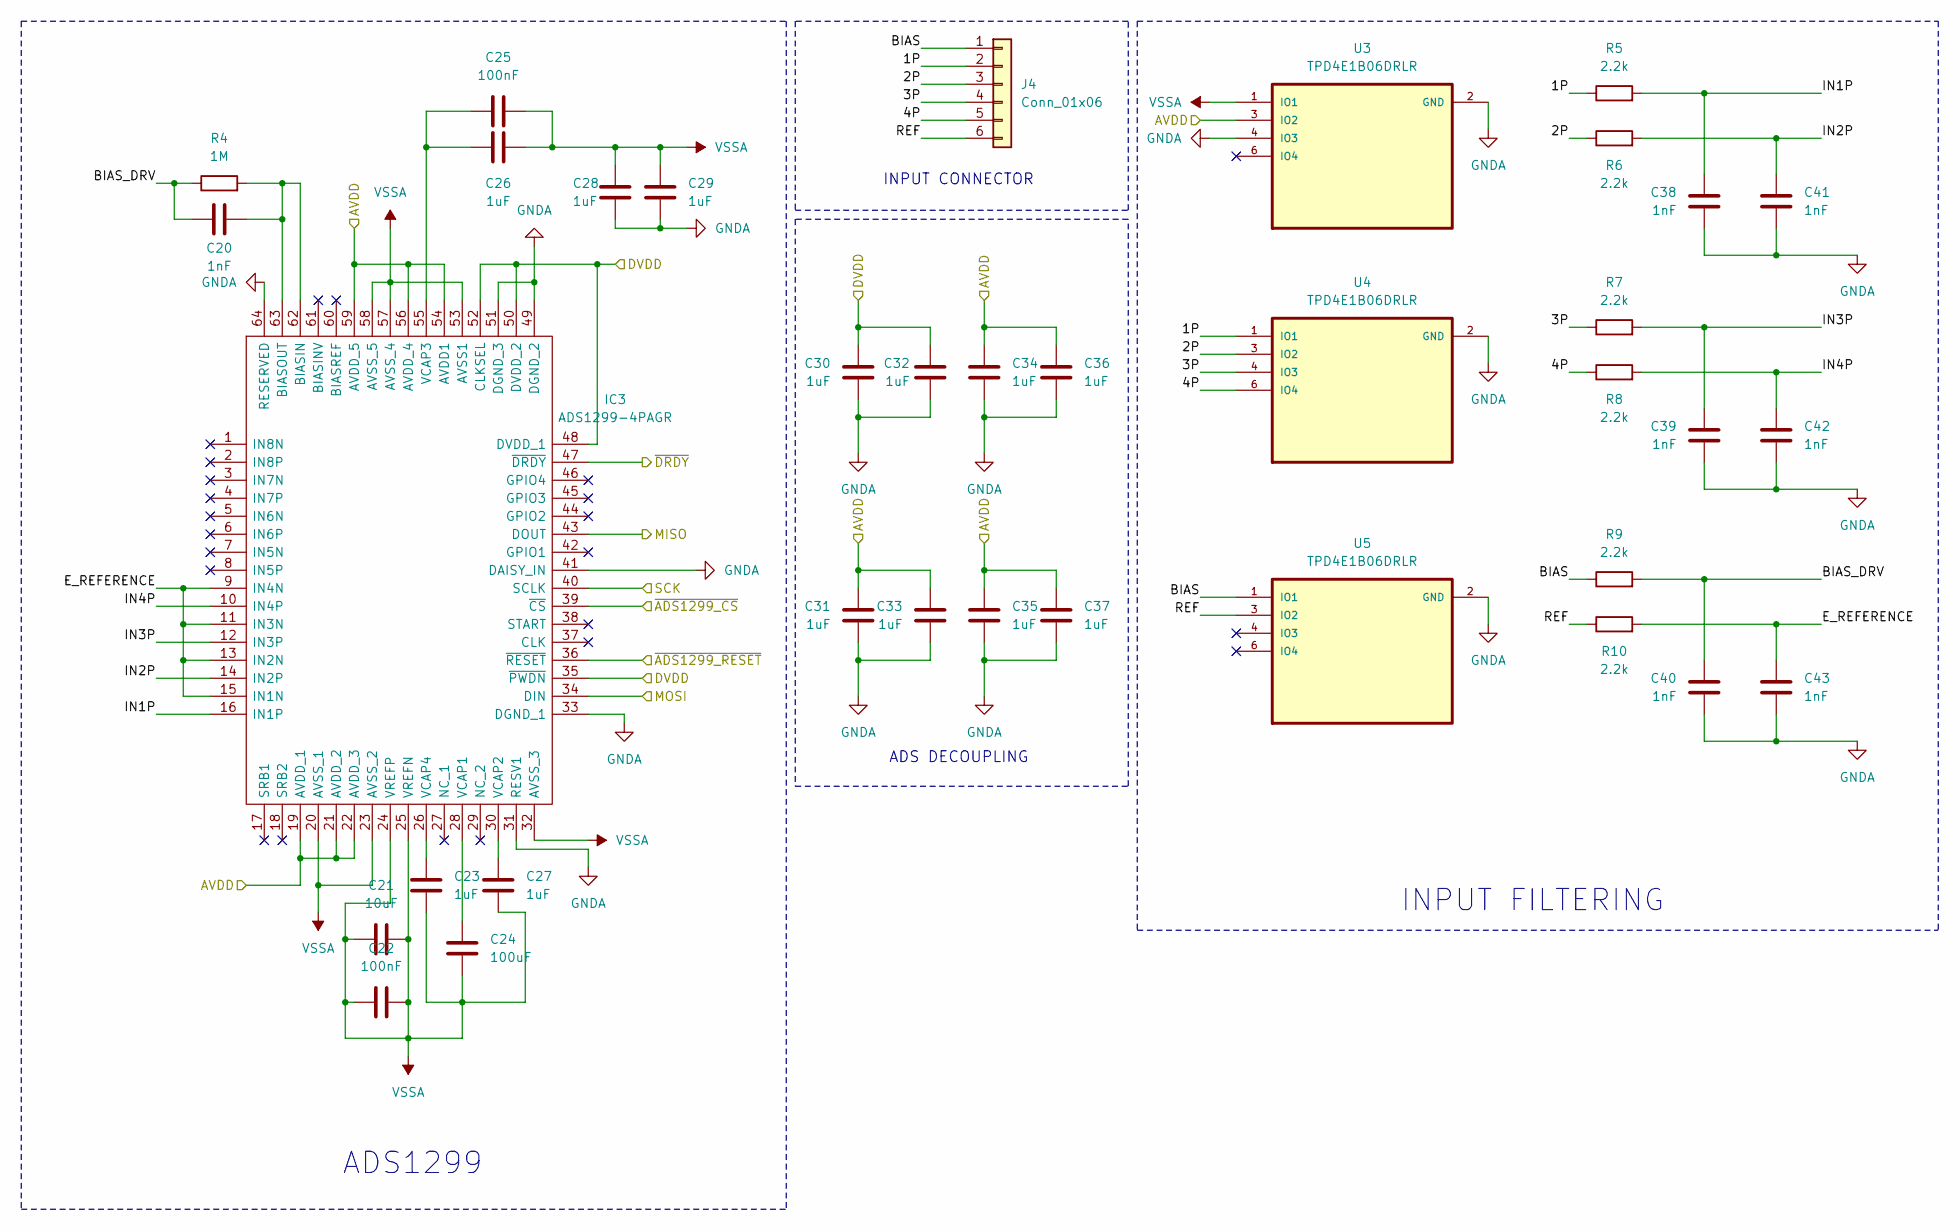
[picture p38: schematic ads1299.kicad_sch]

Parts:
C20, C38, C39, C40, C41, C42, C43: 1nF; C_0402_1005Metric; MANUFACTURER_PART_NUMBER GRM155R71H102KA01D
C21: 10uF; C_0402_1005Metric; MANUFACTURER_PART_NUMBER GRM155R61A106ME44D
C22, C25: 100nF; C_0402_1005Metric; MANUFACTURER_PART_NUMBER GRM155R71C104KA88D
C23, C26, C27, C28, C29, C30, C31, C32, C33, C34, C35, C36, C37: 1uF; C_0402_1005Metric; MANUFACTURER_PART_NUMBER GRM155R61A105KE15D
C24: 100uF; C_0402_1005Metric; MANUFACTURER_PART_NUMBER GRM21BR60J107ME15L
IC3: ADS1299-4PAGR; QFP50P1200X1200X120-64N; Manufacturer_Part_Number ADS1299-4PAGR; Mouser Part Number 595-ADS1299-4PAGR
J4: Conn_01x06; PinHeader_1x06_P1.27mm_Vertical; MANUFACTURER_PART_NUMBER 1.25T-6A
R4: 1M; R_0402_1005Metric; MANUFACTURER_PART_NUMBER RC0402FR-071ML
R5, R6, R7, R8, R9, R10: 2.2k; R_0402_1005Metric; MANUFACTURER_PART_NUMBER RC0402FR-071ML
U3, U4, U5: TPD4E1B06DRLR; SOT50P160X60-6N; MANUFACTURER_PART_NUMBER TPD4E1B06DRLR

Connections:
/AVDD: C31.2, C33.2, C34.2, C35.2, C36.2, C37.2, IC3.19 (AVDD_1), IC3.21 (AVDD_2), IC3.22 (AVDD_3), IC3.54 (AVDD1), IC3.56 (AVDD_4), IC3.59 (AVDD_5), U3.3 (IO2); also elsewhere on the board
/VDD: C30.2, C32.2, IC3.35 (~PWDN), IC3.48 (DVDD_1), IC3.50 (DVDD_2), IC3.52 (CLKSEL); also elsewhere on the board
/ads1299/1P: J4.2, R5.1, U4.1 (IO1)
/ads1299/2P: J4.3, R6.1, U4.3 (IO2)
/ads1299/3P: J4.4, R7.1, U4.4 (IO3)
/ads1299/4P: J4.5, R8.1, U4.6 (IO4)
/ads1299/BIAS: J4.1, R9.1, U5.1 (IO1)
/ads1299/BIAS_DRV: C20.1, C40.2, R4.1, R9.2
/ads1299/E_REFERENCE: C43.2, IC3.9 (IN4N), IC3.11 (IN3N), IC3.13 (IN2N), IC3.15 (IN1N), R10.2
/ads1299/IN1P: C38.2, IC3.16 (IN1P), R5.2
/ads1299/IN2P: C41.2, IC3.14 (IN2P), R6.2
/ads1299/IN3P: C39.2, IC3.12 (IN3P), R7.2
/ads1299/IN4P: C42.2, IC3.10 (IN4P), R8.2
/ads1299/MISO: IC3.43 (DOUT); also elsewhere on the board
/ads1299/MOSI: IC3.34 (DIN); also elsewhere on the board
/ads1299/REF: J4.6, R10.1, U5.3 (IO2)
/ads1299/SCK: IC3.40 (SCLK); also elsewhere on the board
/ads1299/~ADS1299_CS: IC3.39 (~CS); also elsewhere on the board
/ads1299/~ADS1299_RESET: IC3.36 (~RESET); also elsewhere on the board
/ads1299/~DRDY: IC3.47 (~DRDY); also elsewhere on the board
GNDA: C28.1, C29.1, C30.1, C31.1, C32.1, C33.1, C34.1, C35.1, C36.1, C37.1, C38.1, C39.1, C40.1, C41.1, C42.1, C43.1, IC3.31 (RESV1), IC3.33 (DGND_1), IC3.41 (DAISY_IN), IC3.49 (DGND_2), IC3.51 (DGND_3), IC3.64 (RESERVED), U3.2 (GND), U3.4 (IO3), U4.2 (GND), U5.2 (GND); also elsewhere on the board
unnamed: C20.2, IC3.62 (BIASIN), IC3.63 (BIASOUT), R4.2
unnamed: C24.1, IC3.28 (VCAP1)
unnamed: C27.1, IC3.30 (VCAP2)
unnamed: C25.1, C26.1, IC3.55 (VCAP3)
unnamed: C23.1, IC3.26 (VCAP4)
VSSA: C21.1, C21.2, C22.1, C22.2, C23.2, C24.2, C25.2, C26.2, C27.2, C28.2, C29.2, IC3.20 (AVSS_1), IC3.23 (AVSS_2), IC3.24 (VREFP), IC3.25 (VREFN), IC3.32 (AVSS_3), IC3.53 (AVSS1), IC3.57 (AVSS_4), IC3.58 (AVSS_5), U3.1 (IO1); also elsewhere on the board

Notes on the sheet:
ADS DECOUPLING
ADS1299
INPUT CONNECTOR
INPUT FILTERING

Board: 6 copper layers, 80 parts (0 on the bottom side), 65 nets, no tracks yet.

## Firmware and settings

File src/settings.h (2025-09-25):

#ifndef __APP_SETTINGS_H__
#define __APP_SETTINGS_H__

#include <stdbool.h>

#include "hhs_util.h"

#define DEVICE_LIST(X)                                                         \
    /* O2 gas sensor*/                                                         \
    X(O2, = 0)                                                                 \
    /* optional select gas sensor(H2S, CO, NH3, SO2) are common */             \
    X(GAS, )                                                                   \
    X(TEST, )
DECLARE_ENUM(gas_device, DEVICE_LIST)

/* Define a list of Bluetooth events with their corresponding values. */
#define CONFIG_EVENT_LIST(X)                                                   \
    /* event oxygen calibration */                                             \
    X(OXYGEN_CALIBRATION, = 0x01)                                              \
    X(NO2_CALIBRATION, = 0x02)                                                 \
    X(BT_ADV_NAME, = 0x04)                                                     \
    X(ALL_CONFIG_EVENT_FLAG, = 0x07)
DECLARE_ENUM(config_event, CONFIG_EVENT_LIST)

/*  Voltage(0.1%) = (Currently measured voltage value) / ((1+2000/10.7) *
 * (20.9*0.001*0.001*100)) */
#define DEFAULT_O2_VALUE 1900
#define DEFAULT_GAS_VALUE 300

extern struct k_condvar config_condvar;
extern struct k_mutex config_mutex;
extern struct k_event config_event;

/**
 * @brief Updates the configuration based on the type of event and the provided
 * value.
 *
 * This function is responsible for updating the configuration settings of a
 * system. It currently handles the oxygen calibration event by updating the
 * calibration value. The function can be extended to handle other types of
 * configuration events.
 *
 * @param type The type of configuration event that is triggering the update.
 *             This is an enumerated type that should list all possible
 * configuration events.
 * @param value The value associated with the event. For oxygen calibration,
 * this is the new calibration value in millivolts.
 * @return Returns true to indicate the update was successful. Currently, it
 * always returns true.
 */
bool update_config(enum config_event type, void *value);

/**
 * @brief Retrieves a configuration value based on the specified event type.
 *
 * This function looks up a configuration value associated with a particular
 * event type. For example, if the event type is OXYGEN_CALIBRATION, it returns
 * the millivolt value for oxygen calibration. The function currently supports
 * a limited set of events, and can be expanded to include more configuration
 * types as needed.
 *
 * @param type The type of configuration event for which the value is requested.
 *             This is an enumerated type that specifies the particular
 *             configuration value to retrieve.
 * @return The configuration value associated with the given event type. If the
 *         event type is not supported, the function returns 0.
 */
void *get_config(enum config_event type);

#endif

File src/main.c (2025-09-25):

/**
 * @file src/main.c - The starting point of the user application
 *
 * @brief The operation of the main() function, which is the first function
 * called after kernel initialization
 *
 * @author bradkim06@gmail.com
 */
#include <hal/nrf_power.h>
#include <zephyr/device.h>
#include <zephyr/drivers/gpio.h>
#include <zephyr/drivers/hwinfo.h>
#include <zephyr/drivers/watchdog.h>
#include <zephyr/kernel.h>
#include <zephyr/logging/log.h>
#include <zephyr/pm/pm.h>
#include <zephyr/sys/poweroff.h>
#include <zephyr/sys/reboot.h>

#include "gas.h"
#include "version.h"

/* ───── 설정 값 ───── */
#define LONG_PRESS_MS 1000 /* 길게 누름 시간 */

static const struct gpio_dt_spec sw0 = GPIO_DT_SPEC_GET(DT_ALIAS(sw0), gpios);
static struct gpio_callback sw_cb;
static struct k_timer long_press_timer;
static volatile bool off_pending; /* 뗐을 때 power-off 플래그 */
static atomic_t pressed;

/* 타이머 만료 → 1 초 이상 눌림 확인 */
static void long_press_handler(struct k_timer *timer) {
    if (!atomic_get(&pressed))
        return;

    printk("Long press detected – release to power-off\n");
    off_pending = true; /* 뗐을 때 끌 것 */
}

/* 전원 끄기 전 GPIO 핀을 연결 해제하여 누설 전류를 최소화합니다. */
static void configure_gpios_for_poweroff(void) {
    const struct device *const gpio0 = DEVICE_DT_GET(DT_NODELABEL(gpio0));

    if (!device_is_ready(gpio0)) {
        printk("GPIO0 not ready\n");
        return;
    }

    for (uint8_t pin = 0; pin < 32; pin++) {
        switch (pin) {
        case 31: /* wake-up 버튼 – 건드리지 않음 */
            break;

        case 29: /* VBATT 전원 스위치 및 LED 게이트 전원 차단 */
        case 26: /* LED 게이트는 VBATT 스위치를 Low 로 당겨 공유 차단 */
        case 27: /* LED 게이트는 VBATT 스위치를 Low 로 당겨 공유 차단 */
            gpio_pin_configure(gpio0, 29, GPIO_OUTPUT_LOW);
            break;

        default: /* 나머지 – 완전 Hi-Z */
            gpio_pin_configure(gpio0, pin, GPIO_DISCONNECTED);
            break;
        }
    }
}

static void button_cb(const struct device *dev, struct gpio_callback *cb,
                      uint32_t pins) {
    bool val = gpio_pin_get_dt(&sw0);

    if (val) { /* High → 눌림 시작 */
        atomic_set(&pressed, 1);
        k_timer_start(&long_press_timer, K_MSEC(LONG_PRESS_MS), K_NO_WAIT);
    } else { /* Low → 뗌 */
        atomic_set(&pressed, 0);
        k_timer_stop(&long_press_timer);

        if (off_pending) { /* 길게 누른 뒤 손 뗐음 → 끄기 */
            off_pending = false;

            /* 깨우기용: 다음 Rising(High) 에 반응 */
            gpio_pin_interrupt_configure_dt(&sw0, GPIO_INT_LEVEL_ACTIVE);

            configure_gpios_for_poweroff();

            hwinfo_clear_reset_cause();
            sys_poweroff(); /* System-OFF, 전류 ≈ 0.3 µA */
        }
    }
}

LOG_MODULE_REGISTER(MAIN, CONFIG_APP_LOG_LEVEL);
FIRMWARE_INFO();

/**
 * @brief This thread performs kernel initialization, then calls the
application’s main() function (if one is defined).

By default, the main thread uses the highest configured preemptible thread
priority (i.e. 0). If the kernel is not configured to support preemptible
threads, the main thread uses the lowest configured cooperative thread priority
(i.e. -1).

The main thread is an essential thread while it is performing kernel
initialization or executing the application’s main() function; this means a
fatal system error is raised if the thread aborts. If main() is not defined, or
if it executes and then does a normal return, the main thread terminates
normally and no error is raised.
 *
 * @return must be 0(none error)
 */
int main(void) {
    LOG_INF("Firmware : %s", firmware_info);
    LOG_INF("Board:%s  SoC:%s  ROM:%dkB  RAM:%dkB", CONFIG_BOARD, CONFIG_SOC,
            CONFIG_FLASH_SIZE, CONFIG_SRAM_SIZE);

    /* ① 버튼 핀 설정 */
    gpio_pin_configure_dt(&sw0, GPIO_INPUT | GPIO_PULL_DOWN);
    /* 풀다운 저항이 안정될 시간을 줌 */
    k_sleep(K_MSEC(10));

    gpio_pin_interrupt_configure_dt(&sw0, GPIO_INT_EDGE_BOTH);
    gpio_init_callback(&sw_cb, button_cb, BIT(sw0.pin));
    gpio_add_callback(sw0.port, &sw_cb);

    k_timer_init(&long_press_timer, long_press_handler, NULL);

    /* ② 부팅 원인 확인 */
    uint32_t cause;
    hwinfo_get_reset_cause(&cause);
    printk("Hold P0.31 for 1 s to enter deep sleep.\n");

    /* ③ 애플리케이션 루프 */
    while (1) {
        k_sleep(K_FOREVER);
    }

    return 0;
}

#if DT_HAS_COMPAT_STATUS_OKAY(nordic_nrf_wdt)
/* Maximum and minimum window for watchdog timer in milliseconds */
#define WDT_MAX_WINDOW 5000U
#define WDT_MIN_WINDOW 0U

/* Interval for feeding the watchdog timer(ms) */
#define WDT_FEED_INTERVAL 1000U

/* Option for watchdog timer */
#define WDT_OPER_MODE WDT_OPT_PAUSE_HALTED_BY_DBG
#endif

/**
 * @brief Watchdog thread function.
 *
 * This function sets up the watchdog timer and continuously feeds it.
 */
static void watchdog_thread_fn(void) {
    int setup_error_status;  // wdt_setup 결과 코드 저장
    int watchdog_channel_id; // 설치된 watchdog 채널 식별자
    const struct device *const watchdog_device =
        DEVICE_DT_GET(DT_ALIAS(watchdog0)); // watchdog 주변장치 핸들

    // Check if the device is ready before proceeding
    if (!device_is_ready(watchdog_device)) {
        LOG_ERR("%s: device not ready.\n", watchdog_device->name);
        return;
    }

    struct wdt_timeout_cfg watchdog_configuration = {
        /* Reset SoC when watchdog timer expires. */
        .flags = WDT_FLAG_RESET_SOC,

        /* Expire watchdog after max window */
        .window.min = WDT_MIN_WINDOW,
        .window.max = WDT_MAX_WINDOW,
    };

    // Install timeout for the watchdog
    watchdog_channel_id =
        wdt_install_timeout(watchdog_device, &watchdog_configuration);
    if (watchdog_channel_id < 0) {
        LOG_ERR("Error installing watchdog timeout\n");
        return;
    }

    // Set up the watchdog
    setup_error_status = wdt_setup(watchdog_device, WDT_OPER_MODE);
    if (setup_error_status < 0) {
        printk("Error setting up watchdog\n");
        return;
    }

    // Feed the watchdog
    while (1) {
        wdt_feed(watchdog_device, watchdog_channel_id);
        k_sleep(K_MSEC(WDT_FEED_INTERVAL));
    }
}

#define STACKSIZE 1024
#define PRIORITY 14
K_THREAD_DEFINE(watchdog_thread_id, STACKSIZE, watchdog_thread_fn, NULL, NULL,
                NULL, PRIORITY, 0, 0);

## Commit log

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2023-09-13 Feat:adc: battery mon,o2,gas add
    - battery monitoring voltage & percentage
    - o2, gas adc input
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2023-09-13 Fix:battery: batt_mon.c & battery.h integrate to battery.c
    [battery.c]
2023-09-13 Fix:load_switch: switch 코드 파일 분할 & SYS_INIT
    [gas.c]
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2023-09-13 Fix: sleep code fix (ms -> sec)
    [battery.c, gas.c]
2023-09-14 Fix:switch: ctrl delay option add
    [battery.c]
2023-09-14 Fix:Log: dbg -> inf
    [battery.c, gas.c]
2023-09-18 Fix: enum macro create, led device add
    [battery.c, gas.c, led.c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]
2023-09-20 Fix:Log: delete line break
    [battery.c, gas.c, main.c]
2023-09-20 Fix:ble: semaphore -> event
    [gas.c]
2023-09-20 Fix:dts: load_switch (dts -> overlay)
    [gas.c]
2023-09-20 Fix: alarm & enum
    [battery.c, main.c]
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2023-10-17 Fix: Low Power Consumption Setting
    [battery.c, gas.c]
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2023-10-17 Fix: App Log Module Fix
    [battery.c, gas.c, led.c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]
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2023-10-18 Fix: Adc timing fix
    [battery.c, gas.c]
2023-10-20 Feat: BME680 Driver & App
    - CONFIG_BME68X Kconfig 옵션 추가
    - CONFIG_BME68X_IAQ disable시 온도,기압,습도만 측정 3.7uA
    - IAQ 측정 기능 Kconfig Optionable -> CONFIG_BME68X_IAQ, depends on
    CONFIG_BME68X
    - CO2, VOC 측정 기능 추가
    - IAQ accuracy 추가
    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
2023-10-20 Fix: bme680 iaq sample rate option kconfig add
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2023-10-24 Fix: No Serial gas test
    [gas.c]
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2023-10-27 o2: fix o2 max output value
    [gas.c]
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2023-11-01 driver: bme680 library git exclude & path fix
2023-11-03 refactor: hhs_math
    Changes made:
    1. Renamed the function and variables to more descriptive names.
    2. Added Doxygen style comments to the function.
    3. Added comments to explain the logic of the code.
    Please note that the original code seems to assume that the `curve` array is sorted in descending order of `lvl_mV`. If this is not the case, the function may not work as expected.
    In this version, I've added a brief description at the beginning to explain what the function does. I've also added more detail to the parameter descriptions, and clarified the return value.
2023-11-03 bug: bme680: truncate_sensor_data_decimal_places function
    Refactor truncate_sensor_data_decimal_places function in bme680_app.c:
    - Changes the function to take a pointer to the sensor data instead of the sensor data itself. This allows the function to modify the sensor data directly.
    - Adds error logging for invalid input parameters.
    - Changes the function to return void since the sensor data is now modified directly.
    - Updates the calls to this function to pass the address of the sensor data.
2023-11-03 Refactor: Improve code readability and consistency
    This commit includes several changes aimed at improving code readability
    and consistency across multiple files. The changes include:
    - Renamed `batt_value` to `battery_value` for clarity.
    - Renamed `notify_gas_enabled` to `bt_notify_enable` for consistency.
    - Renamed `bt_thread_fn` to `bluetooth_thread` for clarity.
    - Renamed `fw_info` to `firmware_info` for clarity.
    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
2023-11-06 Cleanup: Remove unused includes and reorder variable declaration
    This commit does the following:
    - Adds 'test.txt' to .gitignore
    - Removes unused include 'math.h' from battery.c
    - Removes unused includes 'bluetooth.h' and 'hhs_math.h' from bme680_app.c
    - Reorders the declaration of 'events' variable in bme680_app.c
    - Removes unused include 'errno.h' from led.c and main.c
    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
2023-11-06 Bluetooth: Refactor gas sensor data notification function
    This commit refactors the function that sends gas sensor data via Bluetooth notification. The changes include:
    - Renaming the function parameter to make it clear that it's a pointer to the gas sensor data.
    - Changing the log string to include the length of the data being sent.
    - Updating the warning log message to use more standard language ("smaller than" instead of "small than").
    - Changing the return statement to cast the data length to size_t.
    In addition, a minor change was made in the bme680_app.c file to change an error log message to a warning, as the condition being logged is a possible case.
2023-11-06 bme680: Refactor code for clarity and strictness
    This commit includes several changes to improve code clarity and
    strictness.
    - In .clangd, the Diagnostics section has been updated to enforce
    strict checking of unused includes.
    - In bme680_app.c, the inclusion of "bluetooth.h" is now conditional
    based on the CONFIG_BME68X_IAQ_EN flag.
    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
2023-11-06 gas: Simplify millivolts calculation in convert_adc_to_mv
    This commit simplifies the calculation of millivolts in the
    convert_adc_to_mv function. The previous if-else structure is replaced
    with a ternary operator, reducing the number of lines and improving
    readability.
    [gas.c]
2023-11-06 CMake: Refactor for readability and consistency
    This commit refactors the CMakeLists.txt files for improved readability and consistency. Changes include:
    - Switching from uppercase to lowercase for function names, in line with CMake best practices.
    - Adding line breaks and indentation for better readability in complex function calls.
    - Reformatting comments for consistency and clarity.
    No functional changes are introduced with this commit.
2023-11-07 gas: Improve variable naming and code clarity in update_gas_data
    This commit improves the readability of the update_gas_data function by
    renaming the parameters and some local variables to more descriptive
    names. The change from avg_mv to avg_millivolt and from type to
    device_type, for instance, makes it clearer what these parameters
    represent.
    The commit also moves the O2_THRESHOLD constant into the case statement
    where it's used, reducing its scope and preventing potential naming
    conflicts. It also replaces the macro with a const variable, which is
    more type safe.
    The comment about thread safety is moved to where the semaphore is
    actually taken, making it clear what it refers to.
    This c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
    [gas.c]
2023-11-08 watchdog: Enable watchdog and add watchdog thread
    This commit enables the watchdog in the release.conf and removes the CONFIG_WATCHDOG=n line.
    In addition, it adds a watchdog thread in src/main.c. The watchdog thread checks the device's readiness, installs a timeout for the watchdog, sets up the watchdog, and continuously feeds the watchdog. If the device is not ready or there are any errors, appropriate error messages are printed out.
    The watchdog thread is defined with a stack size of 1024 and a priority of 14.
    [main.c]
2023-11-08 thread: Adjust thread priorities in various subsystems
    This commit adjusts the thread priorities for the following subsystems: battery, bluetooth, bme680, gas, and led.
    The aim is to optimize performance by adjusting the thread priorities to better suit the workload and importance of each subsystem.
    The new priority levels are as follows:
    - Battery: 3
    - Bluetooth: 0
    - BME680: 1
    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
2023-11-14 wdt: Refactor watchdog thread for clarity and consistency
    This commit makes several changes to the watchdog thread function in
    main.c:
    - The function is renamed from 'watchdog_thread' to
    'watchdog_thread_fn' to better reflect its purpose.
    - The names of several variables are changed to be more descriptive
    and consistent with the rest of the code.
    - The code for checking if the device is ready and for setting up the
    watchdog is refactored for clarity.
    - The use of 'printk' for error reporting is replaced with 'LOG_ERR' to
    align with the preferred logging mechanism in the rest of the code.
    - The code for feeding the watchdog is simplified.
    - Comments are added to explain what the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
    [main.c]
2023-11-21 Commit: Implementing line length limit and filter rules in CPPLINT.cfg
    This commit introduces a new configuration for CPPLINT. It sets the line length limit to 100 characters to improve code readability. Additionally, it applies several filter rules to ignore certain wh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
    [CPPLINT.cfg]
2023-11-21 Refactor: Minor code clean up and comment updates
    This commit includes a few minor changes to improve code readability and maintainability. The changes include:
    - Reordered the include statements in bme68x_iaq.c for better organization.
    - Fixed a typo in a comment in battery.c.
    - Removed an unnecessary return comment in bme680_app.c.
    - Added specific developer TODO tags in gas.c for better tracking of tasks.
    - Added a developer tag to a TODO comment for handling temperature sensor error case in gas.c.
    [battery.c, bme68x_iaq.c, gas.c]
2023-11-21 Adjust battery and gas measurement parameters for improved performance
    This commit modifies several parameters related to battery and gas measurement.
    In battery.c, the battery level point has been adjusted from 3550 to 3300 for better battery performance. The log message formatting has been changed to use snprintf instead of sprintf for safer stri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
    In gas.c, the gas average filter size has been reduced from 30 to 10 for faster calculation.
    These changes aim to improve the performance and efficiency of th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
2023-11-22 doc: Clarify watchdog timer unit in comment
    Commit body:
    This commit updates the comment related to the watchdog timer in the main.c file. It changes the comment from "(ms)" to "in milliseconds" to provide better clarity.
2023-11-22 doc: Update CPPLINT configuration and TODO comments in gas.c and gas.h
    The CPPLINT.cfg file has been updated to include '-readability/todo' in the filter.
    In addition, the TODO comments in gas.c and gas.h have been modified to remove specific usernames. The comments now just read 'TODO:' followed by the task description. This change is in line with bes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
    [CPPLINT.cfg]
2023-11-28 refactor:bluetooth: Fix buffer sizes and snprintf usage
    This patch fixes several issues related to buffer sizes and the use of sprintf in bluetooth.c. It ensures that buffers are correctly sized to include the null-terminator and replaces sprintf with snprintf to avoid potential buffer overflows. Additionally, the patch refactors the construction of the notify_data string to use dynamic memory allocation and snprintf, which is safer and more maintainable. The conditional compilation around BME68X sensor data has also been cleaned up for clarity.
2023-11-28 bluetooth/gas: Refactor macros to const variables and reorganize devicetree checks
    Refactor the INITIAL_DELAY macro in bluetooth.c and GAS_MEASUREMENT_INTERVAL_SEC and GAS_AVERAGE_FILTER_SIZE macros in gas.c to use const uint8_t variables for better type safety and readability. Add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
2023-11-28 battery: Improve dynamic log message allocation in battery status check
    The existing static allocation for log messages in measure_battery_status() could potentially lead to buffer overflows if the formatted string exceeds the size of MAX_LOG_CASE. This commit replaces the static buffer with dynamic allocation using malloc, ensuring that the log message buffer is appropriately sized for the formatted content. The snprintf function is now used to calculate the required buffer size and to compose the message, preventing any overflow issues. Additionally, the commit removes the unused MAX_LOG_CASE definition.
    [battery.c]
2023-12-05 bug: heap memory leakage fix
    [battery.c]
2023-12-06 gas: create code for H2S sensor
    This commit introduces several changes across Kconfig, device tree source, and the gas sensor implementation for the HHS NRF52832 board:
    - The device tree source file for the HHS NRF52832 board is updated with corrected ADC configuration values and pin assignments for gas monitoring channels.
    - The `src/gas.h` header file is updated with new measurement range and temperature coefficient data for H2S gas sensors.
    [gas.c]
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2023-12-06 bluetooth: change message format for gas sensor in bluetooth_thread
    The message format string used for creating notification data in bluetooth_thread() was missing a placeholder for the fractional part of the gas sensor value. This commit corrects the format string to include the missing '.u' for the fractional part and updates the snprintf() call to pass the correct gas.val2 argument.
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2023-12-11 adc: Clean up sensor voltage calculation comments
    The comments in the device tree source and header file related to the sensor voltage calculations were inconsistent and contained outdated information. This commit cleans up the comments to reflect the correct calculation of the maximum output voltage for 25% oxygen concentration. The erroneous and unnecessary lines have been removed to avoid confusion.
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2023-12-12 gas: Improve ADC measurement and error handling
    This patch fix the ADC measurement function in the gas sensor driver. It changes the type of the adc_buffer variable from uint16_t to int16_t to properly handle differential ADC values. Additionally, it adds error checking after initializing the ADC sequence and logs a warning if the initialization fails. If a negative ADC value is read, it is now logged as a warning and converted to 0 to maintain system stability. The calibrated ADC value is then calculated using the non-negative value.
    [gas.c]
2023-12-12 Bluetooth: fix BT_DEVICE_NAME
    the device name to "HHS_G0001" to reflect the intended device identifier.
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2023-12-13 gas: Remove unused coefficient calculation in calibration function
    The coefficient calculation in the calculate_calibrated_mv function was commented out as it was not being used in the final calculation. The return value now directly uses the raw millivolt value. Additionally, the GAS_COEFFICIENT_STRUCT macro invocation was commented out as it appears to be unused. The gas sensor's maximum output voltage calculation for oxygen in the header file has been updated to reflect a minor correction in the constant used from 5.28 to 5.3, resulting in a change from 686 to 689 in the calculated value.
    [gas.c]
2023-12-26 doc: schematic document update rev(1.0.1)
    - Oxygen Sensor
    - Voltage Amplification Ratio AdjustmentR11(100 -> 10.7), R12(5.1k -> Addition of Capacitor for Noise Reduction (C22)
    - Gas Sensor
    - Addition of Capacitor for Noise Reduction (R19, C23)
    - Battery Connector pitch fix (2.5mm -> 1.25mm)
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2024-01-17 doc: hardware design add(kicad)
    [bom.csv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]
2024-01-23 Refactoring: Changes for Power Optimization
    drivers:bme68x_iaq: Fix sample rate definitions for ULP
    prj.conf:
    - Enable ultra-low power sample rate for BME68X IAQ
    - Adjust Bluetooth connection parameters for power optimization
    The Bluetooth peripheral preferred connection interval and timeout parameters have been adjusted to optimize power consumption. The minimum and maximum intervals have been reduced, and the timeout has been halved to improve energy efficiency.
    src/battery.c: Optimize battery measurement thread for lower power usage
    Added comments to document the power consumption test results for different thread periods. The initial delay for the battery measurement thread has been r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
    [battery.c, gas.c, led.c]
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2024-03-18 hw: ignore hardware backup
    [sensor.kicad_sch]
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2024-05-30 hw: fix sensor circuit & fix ERC Error
    [BMI270.kicad_sch, POWER SUPPLY.kicad_sch, USB-C.kicad_sch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]
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2024-08-02 fix: temperature calibration restore
    [gas.c]
2024-09-12 feat: hw revision 1.0.2
    Rev 1.0.2
    - Voltage Amplification Ratio AdjustmentR18(10.7 -> 10k), R12(2.0k -> 2M)
    -> Reduce Current Consumption
    - Addition of lowpass filter for Noise Reduction
    - Addition of lowpass filter for Noise Reduction
    - 2 Layter -> 4 Layer
    - hansam digitec requirement
    - If USB and RC are very close, errors may occur
    so increase the distance (R1, R23, R24, C22)
    - BME680 Sensor Enable ctrl remove
    - 32k Crystal Layout fix
    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
    [bom.csv, bom.xlsx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]
2024-10-15 feat: hw revision 1.0.3
    [bom.csv, bom.xlsx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]
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2024-11-13 test: gas biasing circuit
    [bom.csv, bom.xlsx, gas_nrf52832.kicad_pcb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]
2024-12-18 feat: hw revision 1.0.4
    [bom.csv, bom.xlsx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]
2025-03-27 feat: hw revision 2.0.1
    [V1_재고.xlsx, V2_재고.xlsx, bom.csv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]
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2025-07-02 hw 2.0.1 smt add
    [bom.csv, bom.xlsx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]
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2025-09-03 restore hw 2.0.1
    [gas_nrf52832.kicad_pcb, gas_nrf52832.kicad_sch, nrf52832.kicad_sch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]
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
